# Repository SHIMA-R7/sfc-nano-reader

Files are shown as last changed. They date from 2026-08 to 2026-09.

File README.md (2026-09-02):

# SFC (Super Famicom) Cartridge Reader — Nano x3

Arduino Nano 3台だけでスーパーファミコンのカートリッジROMを読み出すプロジェクト。

ESP32-S3やレベル変換IC、シフトレジスタ(74HC595)を一切使わず、**5VネイティブなNanoを
「アドレス生成」「データ読み取り」「バンク生成」の3役に分担させる**ことで、
手持ちのNano以外の追加部品ゼロで構成しています。

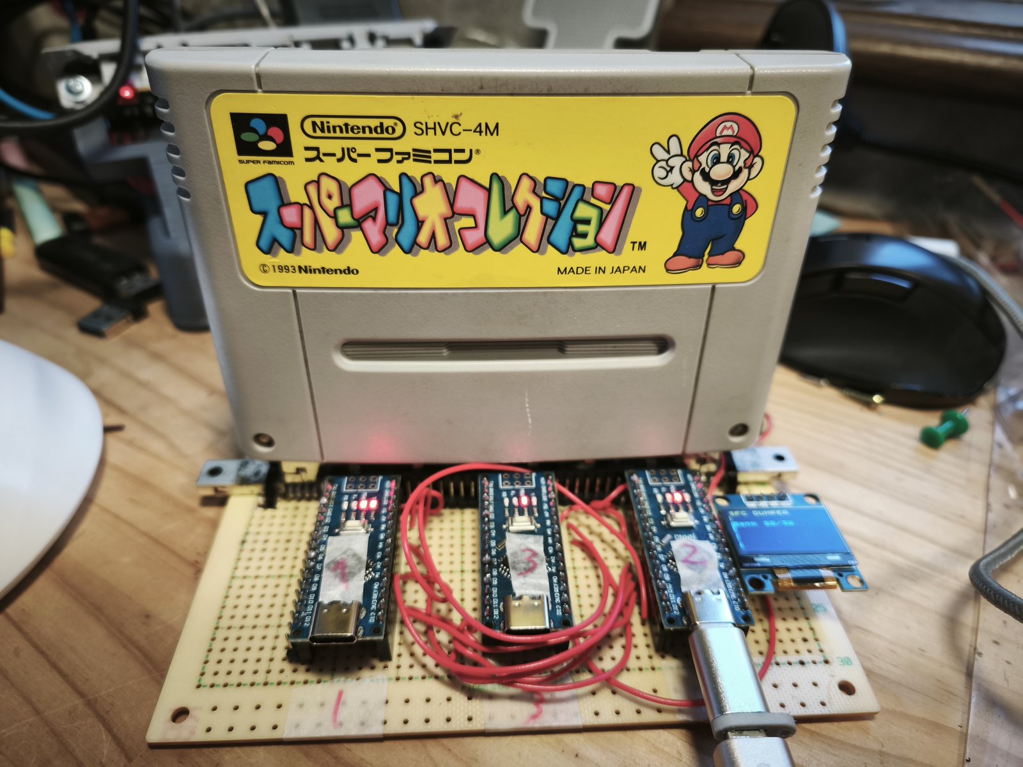
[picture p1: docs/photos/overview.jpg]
全体図


*スーパーマリオコレクション（SHVC-4M）をダンプ中。ユニバーサル基板にNano×3とOLEDを直付けし、
カートリッジコネクタを載せただけの構成。PCBは使っていない。*

> **自分でも作ってみたい方へ** → **[製作・使用ガイド (docs/GUIDE.md)](docs/GUIDE.md)**
> 部品表、コネクタ加工のコツ、配線表、書き込み手順、検証方法、
> トラブルシューティングをまとめてあります。
>
> **ここに至るまでの経緯** → **[開発史 (docs/HISTORY.md)](docs/HISTORY.md)**
> 踏んだ地雷と誤診の記録。「なぜこの設計なのか」はこちらに書いてあります。

## この文書について

**ここには結論と、使うときの注意だけを書いています。**
どう間違え、どう気づいたかの経緯は [開発史](docs/HISTORY.md) にまとめました。
同じ地雷を踏む人を減らすための記録なので、似た症状で困ったらそちらを見てください。

- [開発史](docs/HISTORY.md) — 誤診と訂正の記録（10章）
- [製作報告PDF](docs/SFCダンパー製作報告.pdf) — 20ページの詳細版
- [やさしい解説PDF](docs/やさしい解説.pdf) — 非技術者向け10ページ
- [実験データ](data/) — 判定つきCSV。読み方の注意も同梱

## なぜNano×3なのか

SFCカートを読むには最低でも **アドレス24本 + データ8本 + 制御2本 ≒ 34本** のI/Oが要ります。

| 構成 | 問題点 |
|---|---|
| ESP32-S3 単体 | 5Vトレラントでないため、カートの5V出力を直結すると壊れる。レベル変換IC必須 |
| Arduino Uno 単体 | 5Vネイティブで電圧問題はないが、使えるI/Oが18本しかなく全く足りない |
| Arduino Mega 2560 | I/O 54本で直結でき最も素直（Sanni's Cart Readerがこの構成）。ただし買い足しが必要 |
| **Nano × 3** ← 本プロジェクト | **手持ちのみで完結。全ボードが5Vネイティブなので電圧問題が原理的に発生しない** |

Raspberry Pi Zero 2 を併用する案も検討しましたが、3.3V系のためデータバス8本＋ACKに
分圧抵抗が18本ほど必要になり、「手持ち部品だけで完結する」という利点が失われるため見送りました。

## 構成

```
                    ┌──────────────┐
   A0-A15 ─────────>│              │
                    │  SFCカート   │
   A16-A23 ────────>│  (62pin)     │
                    │              │
   /RD,/ROMSEL ────>│              │
                    └──────┬───────┘
                           │ D0-D7
                           v
  [Nano-1]  <--STROBE--  [Nano-2]  --STROBE-->  [Nano-3]
  A0-A15生成             マスタ/データ読取      A16-A23生成
                         + OLED + USB
                              │
                              v  USBシリアル (1,000,000 bps)
                             PC
```

| ボード | 役割 | スケッチ |
|---|---|---|
| Nano-1 | カートアドレス **A0-A15** を生成。STROBEの立ち上がりで16bitカウンタを+1、RESETで0クリア。**ピン変化割り込み(PCINT)で受ける** | [nano1_addr_low/](nano1_addr_low/) |
| Nano-2 | `/RD`・`/ROMSEL`制御、**D0-D7**読み取り、USBシリアルでPCへストリーム、SH1106 OLEDへ進捗表示 | [nano2_master/](nano2_master/) |
| Nano-3 | カートアドレス **A16-A23**（バンク）を生成。Nano-1と同じくSTROBE方式＋PCINT | [nano3_bank/](nano3_bank/) |

`/WR` と `/RESET` はカート側で +5V に直結（読み出し専用のため）。

**通常のカートではCICロックアウトチップは関係ありません。** CICは本体側のリセット線を
駆動するだけで、ROMバスを塞いではいないので、無視してアドレスを叩けば読めます。
**ただしSA-1カートは例外で、CIC認証が必要です**
（[SA-1はクロックを与えず、CIC認証を通して読む](#sa-1はクロックを与えずcic認証を通して読む)）。

## 実機の写真

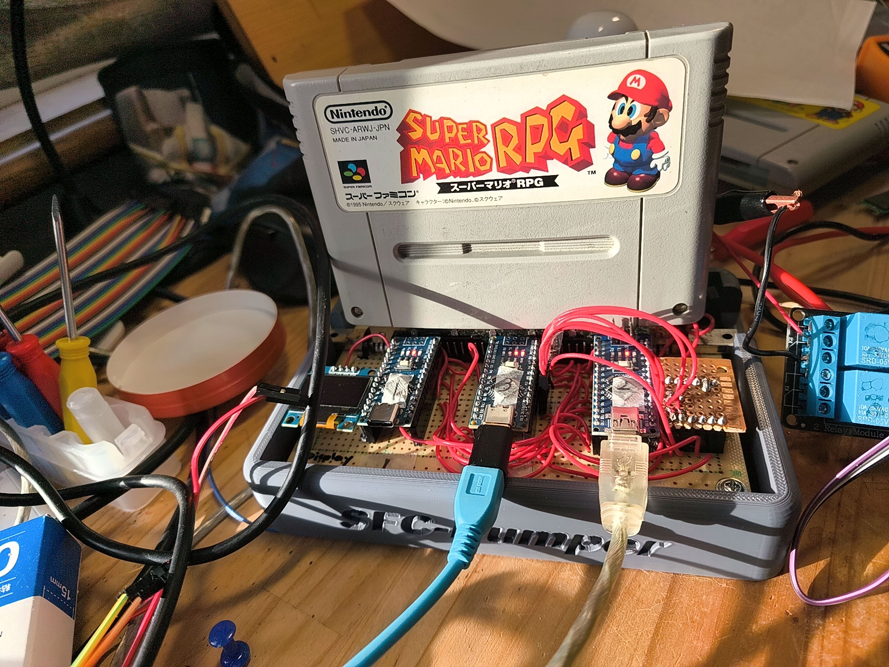
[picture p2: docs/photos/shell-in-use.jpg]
シェルに収めた状態


*3Dプリントしたシェルに基板を収めた状態。スーパーマリオRPG（SA-1）を読み出している。
左からOLED、Nano-3、Nano-1、Nano-2、右端が電源リレー。USBは2本（Nano-2とUno）。*

- 手書きのポンチ図: [docs/schematic-sketch.pdf](docs/schematic-sketch.pdf)
- **シェル（筐体）**: [hardware/shell/](hardware/shell/) — 基板を収める外装。
  裏面の配線を保護し、カートリッジの抜き差しで基板がたわむのも防げる
  - `shell_dumper.stl` — 本体シェル
  - `SFC.stl` — 天面のロゴ
- 3Dプリント部品: [支柱.stl](支柱.stl) — **4本印刷して基板の四隅に取り付ける脚**。
  裏面は配線がびっしり出ているので、机に直置きすると断線やショートの原因になる
  （シェルを使う場合は不要）

| | |
|---|---|
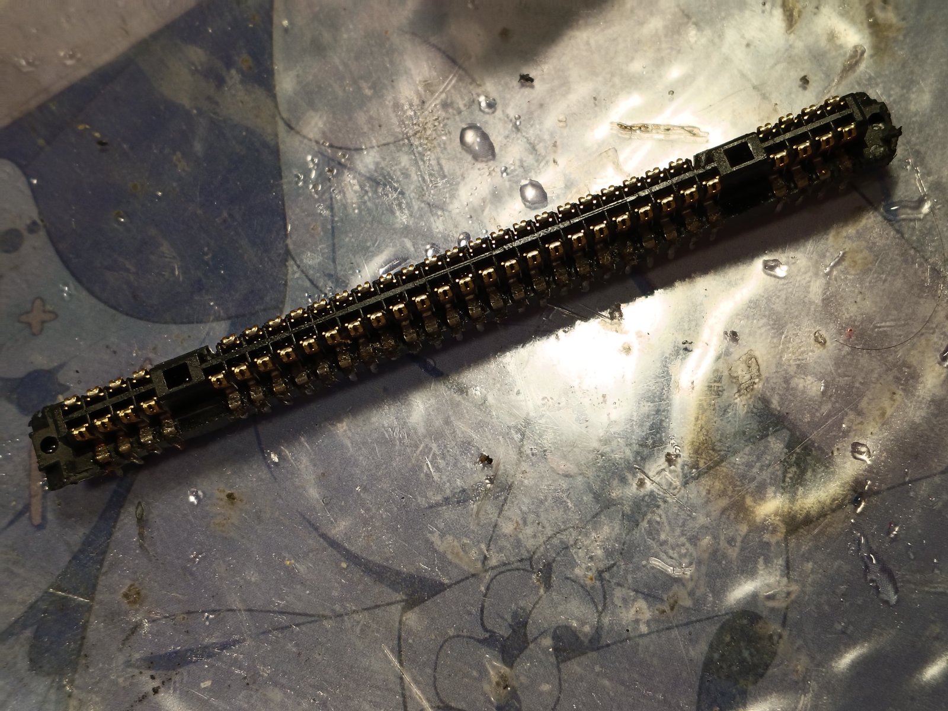
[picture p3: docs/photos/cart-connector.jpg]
カートリッジコネクタ
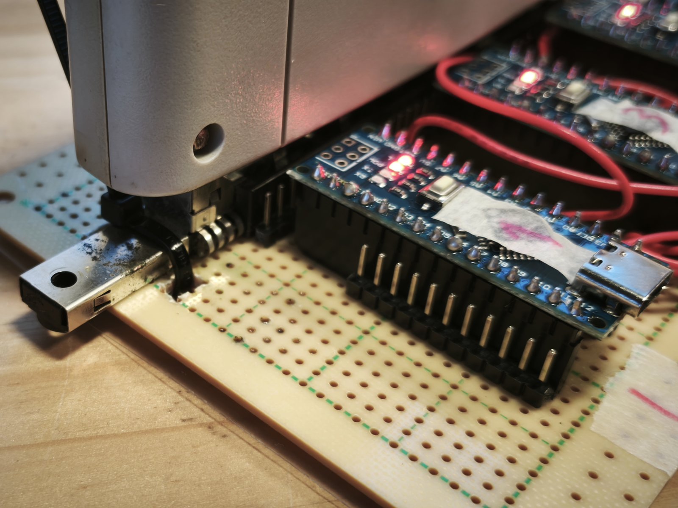
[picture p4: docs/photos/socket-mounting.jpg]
ソケット取り付け
|  |  |
| **ジャンクのスーパーファミコンから取り外した62pinコネクタ。** これが本プロジェクトで唯一「買わずに済ませた」最大の部品。ピッチ2.50mm・列間隔もキー溝も非標準なので、2.54mmのユニバーサル基板に載せるためキー溝を超音波カッターで切断している。 | **Nanoはピンソケットではなくピンヘッダで直付け。** 基板が2.54mmグリッドなので、コネクタ側の寸法差はここで吸収せず力技で押し込んでいる。 |
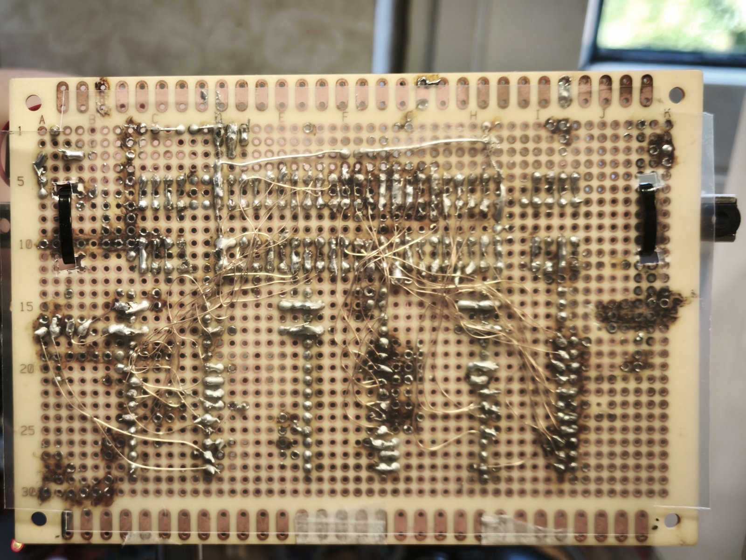
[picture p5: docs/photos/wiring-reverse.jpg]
配線面
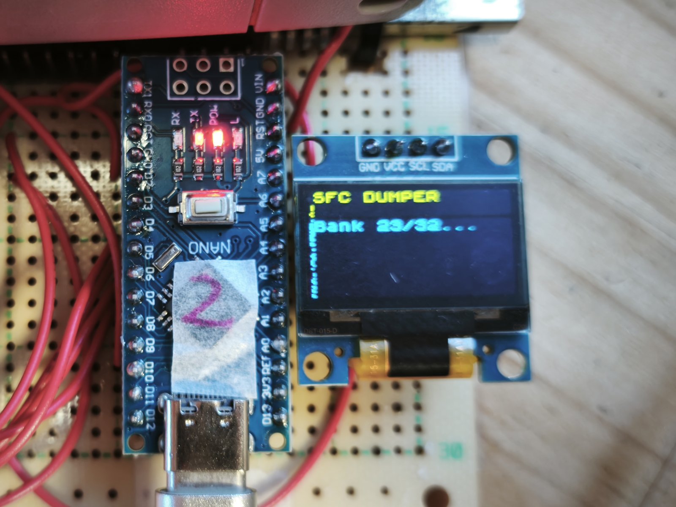
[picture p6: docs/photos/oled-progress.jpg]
OLED表示
|  |  |
| **裏面の配線。** Nano↔カートリッジ間はすべてUEW（ポリウレタン銅線）、それ以外はAWG22のビニール導線。アドレス24本＋データ8本＋制御を手配線している。 | **SH1106 OLEDによる進捗表示。** ハードウェアI2Cピン(A4/A5)はカートのデータバスD4/D5で埋まっているため、ソフトウェアI2CでD11/D12に逃がしている。 |

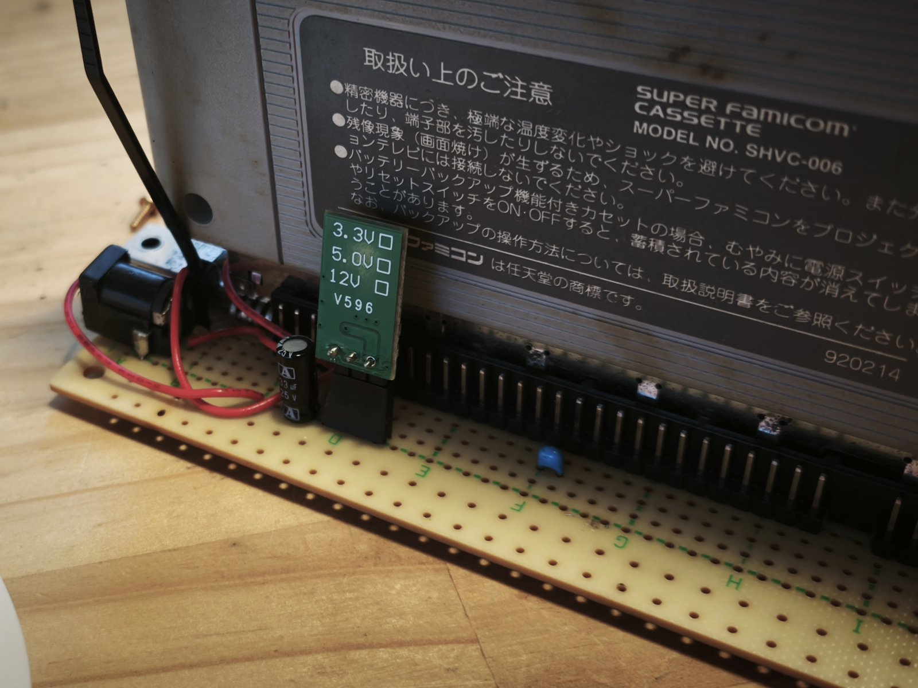
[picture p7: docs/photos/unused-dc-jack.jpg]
未使用のDCジャック


*当初は電源不足を懸念してDC12V入力＋降圧モジュール(3.3V/5.0V/12V可変のV596)を用意したが、
結局USBケーブル1本のバスパワーだけで3台のNano＋OLED＋カートが安定動作したため未使用に終わった。
写真手前の青い部品と電解コンデンサがパスコン。*

## ソフトウェア

### GUIアプリ（推奨）

**[最新版の実行ファイルをダウンロード（Releases）](https://github.com/SHIMA-R7/sfc-nano-reader/releases/latest)**
— Windows向け単一exe。Pythonのインストール不要です。

ソースから動かす場合:

```bash
python gui/sfc_dumper_gui.py
```

ブラウザ不要、Python標準のTkinterのみ（追加依存は `pyserial` だけ）。

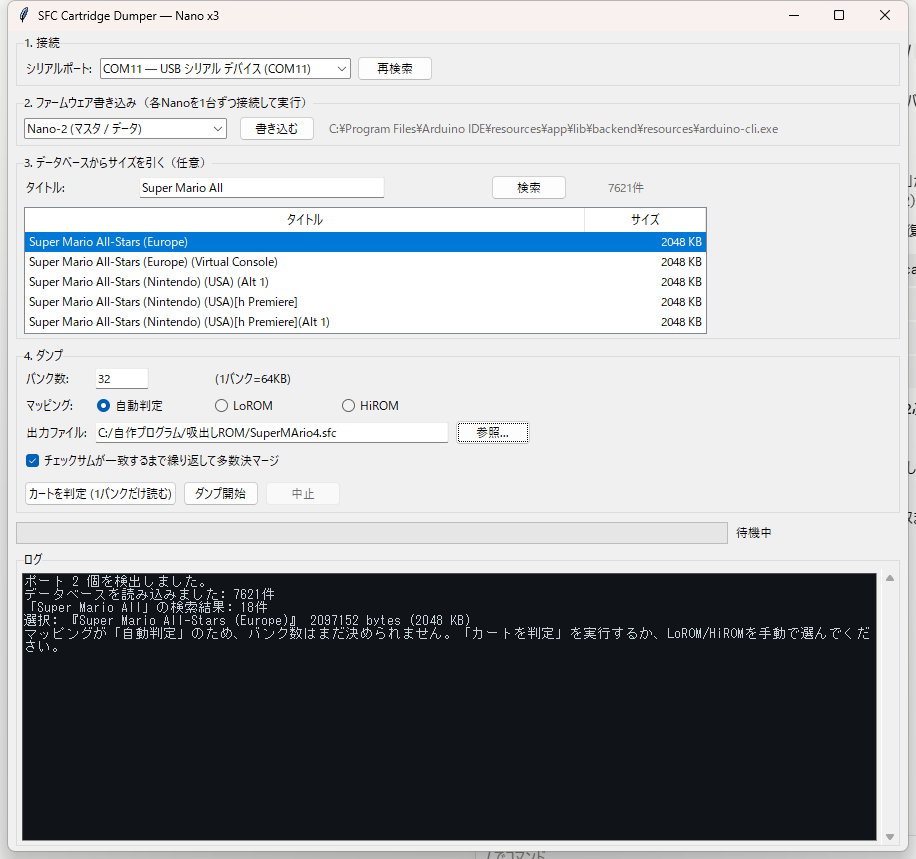
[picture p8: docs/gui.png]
GUI


- **COMポート選択**と自動検出
- **ファームウェア書き込み** — Nano-1/2/3を選んでボタン1つ（`arduino-cli`のパスも自動発見）
- **ROMサイズの指定を3通りから選べる**
  1. **自動判定** — 1バンクだけ読んでヘッダからLoROM/HiROM・サイズ・タイトルを認識
  2. **手動** — バンク数とマッピングを直接入力
  3. **データベース検索** — タイトル名で検索して正確なバイト数を引く（後述）
- **チェックサムが一致するまで自動でダンプを繰り返し、複数サンプルをマージ**
  （バイト単位の多数決とビットORの両方を試し、チェックサムが一致した方を採用する）
- **ダンプ方式を選べる**
  - **2回読んで一致するまで繰り返す**（推奨・速い）
  - **多数決マージ** — 何度読んでも一致しないカート向け。窓ごとの外れ値排除、
    ビット単位の再構成、決着しないバンクだけタイミングを上げて読み足す
    （[host/contact_merge.py](host/contact_merge.py) と同じ実装を共有）
- **タイミング掃引ボタン** — 同じバンクを5段階で2回ずつ読み、
  「タイミング不足 / 接触 / Super FX」のどれなのかを切り分けて、適切な段階を自動で選ぶ
  （[切り分けの根拠](#0xff率が動くかどうかで接触とタイミング不足を切り分ける)）
- **キャッシュのカート照合** — 前回のサンプルを再利用する前に1バンクだけ読んで、
  同じカートかを突き合わせる。違えばその場で止まる
- **2の累乗でないROMの検出** — 読んだ長さで合わなければ短いサイズも試し、
  末尾のミラーを切り落とす（12Mbitのカートが2MBと名乗る問題への対処）

### CLI

```bash
# バンク単位で読む（推奨）。1バンクごとにリセットし、2回読んで一致するまで繰り返す
python host/dump_by_bank.py --port COM12 --banks 64 --mapping lorom --out MyGame.sfc
```

長時間の連続読み出しで誤りが出る問題（後述）を避けられるので、この方式が最も確実です。
確定したバンクは `<出力名>.banks/` にキャッシュされ、中断しても続きから再開できます。

```bash
# 通しで一気に読む（要ファーム変更: バンク単位モードを外す）
python host/receive.py COM12 2097152 dump.bin

# 通しダンプを繰り返してマージ（多数決 / ビットOR）
python host/dump_until_valid.py --port COM12 --banks 32 --mapping hirom --out MyGame.sfc
```

```bash
# 接触が悪くて「2回一致」が永久に取れないカート用。窓ごとの多数決で押し切る
python host/contact_merge.py --port COM12 --banks 64 --mapping lorom --out MyGame.sfc

# カートを挿し直した/配線を変えた直後は、それまでのサンプルを退避してから
python host/contact_merge.py --port COM12 --banks 64 --mapping lorom --out MyGame.sfc --fresh

# 既に取ってあるサンプルだけでマージし直す（カートを挿さなくてよい）
python host/contact_merge.py --merge-only --banks 64 --mapping lorom --out MyGame.sfc
```

生サンプルは `<出力名>.votes/` に1本ずつ残り、中断しても続きから積み増せます。
決着しなかったバイトは `<出力名>.report.txt` に位置が出ます。詳細は
[接触不良のカートを回数で押し切る](#接触不良のカートを回数で押し切る)。

### セーブデータ（バッテリーバックアップSRAM）の吸い出し

GUIの「5. セーブデータ」から実行できます。「カートを判定」を先に押すと、ヘッダから容量を
読んでボタンが有効になります。CLIなら:

```bash
python host/dump_sram.py --port COM12 --rom MyGame.sfc --out MyGame.srm
```

ROMは焼き直せば同じものが手に入るが、**セーブデータは世界に1つしかない**。しかもカート内の
ボタン電池は寿命が近く、切れた瞬間に永久に失われる。ROMより優先度が高い。

`--rom` に検証済みのROMを渡すと、そのヘッダからマッピングとSRAM容量を読んで自動設定する。
出力した `.srm` はそのままRetroArchの `saves/<コア名>/` に置けば実機の続きから遊べる
（夜光虫で3スロットぶんのセーブが読み込めることを実機確認済み）。

**書き込み事故は原理的に起こらない。** `/WR` はカート側で +5V に直結してあるので、
ファームに何を書こうとSRAMへの書き込みは物理的に発生しない。読み出し専用として作った
配線が、そのまま救出対象を守る安全装置になっている。

#### /ROMSEL の極性はマッピングで逆になる

ここが唯一の落とし穴だった。当初は「SRAMはROMとは別物だから `/ROMSEL` をアサートしない」と
考えて実装したが、LoROMでは全バイトが 0x00 になった。SNESの `/CART` がアサートされる条件は
**「バンク $40-$7D は全アドレス、バンク $00-$3F は $8000-$FFFF のみ」** なので:

| マッピング | SRAMの位置 | `/ROMSEL` |
|---|---|---|
| LoROM | `$70:0000-$7FFF` | **アサートする**（バンクが $40-$7D 側） |
| HiROM | `$20:6000-$7FFF` | **アサートしない**（$8000未満） |

全バイト0x00を見て「電池切れか」と早合点しなかったのは、**電池が切れていてもSRAMチップ自体は
カート動作中は+5Vで動くので、読めば何かしら返るはず**という理屈があったため。0x00で埋まるのは
「誰もバスを駆動していない」ときの症状で、これはROMダンプ時にも観測済みだった。

#### ミラーを検証に使う

SRAMの実容量(2KB〜32KB)はバンクの窓(LoROM 32KB / HiROM 8KB)より小さいことが多く、余りには
同じ内容が繰り返し現れる。この繰り返しが一致するかを**1回の読み出しだけで完結する検査**として
使える。ただしカートによってはSRAM外がオープンバスになりミラーが出ないので、判定の主軸は
従来どおり「2回読んで一致」に置き、ミラーは補助的な手がかりとして扱っている。

### データベース検索について

RetroArchに同梱されている `database/rdb/Nintendo - Super Nintendo Entertainment System.rdb`
（No-Intro準拠、7,621件）をそのまま読んでいます。**ネットワークアクセスは不要**です。

このファイルはlibretro独自のバイナリ形式（MessagePack）なので、外部ライブラリを増やさずに
済むよう最小限のデコーダを [gui/rdb.py](gui/rdb.py) に実装しています。

DBを使う利点は、**ヘッダの自己申告が2の累乗に切り上げられている場合があるため**です。
例えば `Super Nazo Puyo Tsuu (Japan)` は実際には 1,572,864 bytes (1.5MB) ですが、
ヘッダのROMサイズバイトは2の累乗でしか表現できません。

## 使い方

1. 62pinカードエッジコネクタ経由でカートと3台のNanoを配線
2. GUIから各ボードにスケッチを書き込み（`arduino:avr:nano:cpu=atmega328old` を使用。
   クローン品はOld Bootloader指定でないと `programmer is not responding` になることが多い）
3. 「カートを判定」でROMサイズを特定し、`nano2_master.ino` の `NUM_BANKS` をその値に変更して再書き込み
4. 「ダンプ開始」

## 特殊チップ搭載カートについて

### SA-1（スーパーマリオRPG / 星のカービィ スーパーデラックス）

**手順が決まっています。GUIの「SA-1カートを吸う」ボタンか、`host/sa1_wake.py` を使ってください。**

```bash
python host/sa1_wake.py --port COM19 --out KirbySDX.sfc --power-cycle --rounds 5
```

| 条件 | 内容 |
|---|---|
| **カート1番（マスタークロック）** | **駆動しない。** LOWに落とすと読めなくなる（通算 0/29） |
| カート57番（PHI2） | 駆動しない |
| **起動読み** | 大きく読む前に $C0〜$FF のどれか1バンクを短く読む |
| 読み方 | 1接続で64バンクを読み切る（4MBで約95秒） |
| 検証 | **総和検査とCRC照合を必ず通す** |

**成功率は40〜60%です。2回に1回失敗します。** リトライ前提で使ってください。
これはカート個体差ではなくSA-1の性質で、2タイトル各20回で確認しています。

**失敗の仕方が危険です。** 「64バンク全部がROMらしい」「ヘッダも読める」のに
中身が3割違う、という壊れ方をします。**品質判定は当てになりません。**
総和検査だけが弾きます。GUIのプレイボタンが検証済みROMしか受け付けないのはこのためです。

CIC認証の要否は**分かっていません**。各20回の全ダンプで 40% 対 45% と、
差を検出できませんでした。「不要」と結論したわけではありません（[開発史](docs/HISTORY.md)参照）。

### Super FX（スターフォックス / ヨッシーアイランド）

**特別な手順は要りません。** 通常のダンプで読めます。

ただし**GSUが $0000-$7FFF に応答する**ため、下位32KBだけを見る古い判定では
HiROMと誤判定されました。現在はヘッダの `map_mode` を優先するので問題ありません。
判定時に「搭載チップ: スーパーFX (GSU)」と表示されます。

### DSP-1（スーパーマリオカート など）

チェックサムが合わない場合、GUIが自動で $C0 から読み直します。
DSP-1は $00-$3F の $6000-$7FFF に居座るためROMが隠れます。

### SA-1のセーブデータ（BW-RAM）

**この装置では読めません。配線の制約です。**

sanniの手順は、SA-1のレジスタに書き込んで窓を開けることが前提です。

```c
// Direct writes to BW-RAM (SRAM) in banks 0x40-0x43 don't work
writeBank_SNES(0, 0x2224, block);   // BMAPS: 8KBブロックを $6000-$7FFF へ
writeBank_SNES(0, 0x2226, 0x80);    // SBWE:  書き込み許可
writeBank_SNES(0, 0x2228, 0);       // BWPA:  保護解除
→ その後 $00:6000-7FFF を読む
```

**バンク $40 を直接読んでも取れません**（sanni自身がそう書いています）。

本機は `/WR` をカート側で **+5V に直結**しており、書き込み事故が物理的に
起こらない設計です。そのぶん**SA-1のレジスタも叩けず、窓を開けられません**。

読めるようにするには `/WR` をマイコンに引き直す配線変更が要ります。
**その場合「書き込み事故は起こらない」という保証が失われます。**
対象は電池でしか保たれていないセーブデータなので、判断は慎重に。

---

## 電源（Alientek DP100）

Unoのリレーは不要です。DP100（USB HID / VID 2E3C / PID AF01）をPCから直接叩けば、
出力ON/OFF・電圧設定・**電流測定**がまとめてできます。

```bash
# SA-1を吸う（起動読み＋電源サイクルつき、無人で粘れる）
python host/sa1_wake.py --port COM19 --out KirbySDX.sfc --power-cycle --rounds 3

# 電源だけ落とす
python -c "from host.dp100 import DP100; p=DP100(); p.apply(False,5000,1000); p.close()"
```

### 安全装置は「引数で渡せない」形にしてある

このダンパーは5V専用で、それ以上かけると壊れる。`host/dp100.py` は次の3段構え。

1. **`VMAX_MV = 5000` を超える要求は例外で拒否する。** 電圧を引数で自由に渡せない
2. **投入前に設定を読み戻して一致を確認する。** 違えば出力を入れない
3. **投入直後に実測を読み、5.3Vを超えていたら即座に切る**

3が要るのは、`index=0x20` の書き込みでは **OVPが30.5Vのまま変更できない**ため。
電源側の過電圧保護は当てにできない。

**実際に効いた。** 初回接続時、DP100には **9.000V / 4.000A の設定が残っていた。**
そのまま出力を入れていたら9Vがかかっていた。

### プレイボタン（RetroArch連携）

吸ったROMをそのままRetroArchで起動する「▶ プレイ (RetroArch)」を付けた。

**検証を通ったROMだけ**が対象で、`.unverified` は遊べない。
64/64バンクが「ROMらしい」のに中身が3割違うダンプを何度も見ているので、
検査を通っていないものを起動させると、動かない理由が分からなくなる。

#### 探し方（配布しても動くように）

**まずこのアプリからの相対で探す。**

    <アプリの場所>/RetroArch/retroarch.exe          同梱した場合
    <アプリの場所>/../RetroArch/retroarch.exe       隣に置いた場合
    <アプリの場所>/../../RetroArch/retroarch.exe    exeを dist/ に置いたまま動かす場合
    <アプリの場所>/retroarch.exe                    RetroArchのフォルダに直接置いた場合

見つからなければ C:\RetroArch / %LOCALAPPDATA% / Program Files を当たり、
それでも駄目なら利用者に選んでもらう。選んだ場所は
`%LOCALAPPDATA%\sfc_dumper.json` に覚えるので、次回から聞かない。

コアは RetroArch の `cores/` から snes9x → bsnes → snes9x2010 → mesen-s の順に探す。
起動は `retroarch.exe -L <コア> <ROM>` で、作業ディレクトリはRetroArch側に置く
（設定やアセットを相対で探すため）。

### 連続読み（最速）

GUIのダンプ方式に「連続読み（最速・1バンクごとにリセットしない）」を追加した。
1接続で全バンクを続けて読む。SA-1で使っているのと同じ経路。

    従来方式（バンクごとにリセット）  214.5秒   9.5 KB/s
    連続読み（2回読んで照合込み）      97.1秒  42.2 KB/s
    → 全体 2.2倍 / 読み出し速度そのものは 4.4倍

スターフォックス(1MB)で実測。**従来方式のダンプとバイト単位で完全一致**し、
チェックサム 0xab12 とNo-Intro『Star Fox (Japan)』にも一致した。

既定では**2回読んで完全一致を確認する**（それでも従来より速い）。
一致しなければ保存せず、「2回読んで一致するまで繰り返す」方式へ切り替えるよう促す。

### 消費電流（5V、参考値）

| 状態 | 電流 |
|---|---|
| 電源断 | 1.2 mA / 0.091 V |
| 待機（カービィSDX） | 87〜91 mA |
| 待機（スターフォックス） | 81 mA |
| 読み出し中 | 66 mA (±1.7) |

**読み出し中のほうが待機より低い。** 待機中はカートの入力が浮いてCMOSの貫通電流が
流れ、読み出し中は正しく駆動されるので減る、という説明がつく。

`host/sa1_dp100.py` は0.5秒刻みで `power_log.csv` に記録する
（列: `t_s, iso, phase, round, mV, mA, mW`。`phase` は off/on/idle/read/done）。

## 注意

読み出したROMデータそのもの（`.sfc` / `.bin`）は著作物なので、このリポジトリには含めていません。
自分が正規に所有するカートリッジのバックアップ用途を想定しています。

## 謝辞 / Acknowledgements

このプロジェクトは、先人が公開してくださった資料・ソフトウェアなしには成立しませんでした。
以下すべてに深く感謝します。

### ハードウェア資料

- **[SNESdev Wiki — Cartridge connector](https://snes.nesdev.org/wiki/Cartridge_connector)**
  62pinカードエッジコネクタの完全なピンアサインを参照しました。本プロジェクトの配線表は
  ここの情報が基になっています。
- **[NESdev Wiki — Cartridge connector](https://www.nesdev.org/wiki/Cartridge_connector)**
  コネクタ全般の背景知識について。
- **[NESdev Forums — SNES Edge Connector](https://forums.nesdev.org/viewtopic.php?t=11389)**
  「SNESコネクタは2.54mmではなく2.50mmピッチであり、列間隔とキー溝も非標準」という、
  自作時に最も重要な指摘をここで得ました。
- **[shmups.system11.org — SNES 62-Pin Connector Replacement Dilemma](https://shmups.system11.org/viewtopic.php?t=53375)**
  互換コネクタの実情について。
- **[Sanni's Open Source Cart Reader](https://github.com/sanni/cartreader)**
  カートリッジダンパーの事実上の標準実装。ピンアサインとメモリマップ処理の
  正解を確認する基準として参照しました。Arduino Megaを使う理由（5Vネイティブ＋I/O数）も
  ここから学んでいます。

### ソフトウェア / ライブラリ

- **[U8g2 by olikraus](https://github.com/olikraus/u8g2)** (BSD-2-Clause)
  SH1106 OLEDの駆動に使用。ハードウェアI2Cピンが埋まっていたため、
  ソフトウェアI2C対応が決定的に助かりました。
- **[libretro-database / RetroArch](https://github.com/libretro/libretro-database)**
  タイトル検索とROMサイズ特定に使用している `.rdb` データベースの提供元。
- **[No-Intro](https://no-intro.org/)**
  上記データベースの元となっているROMセット情報の編纂プロジェクト。
- **[Snes9x](https://github.com/snes9xgit/snes9x)** / **[RetroArch](https://www.retroarch.com/)**
  ダンプ結果の検証に使用。特にSnes9xコアが出力する `Checksum OK` / `Invalid Checksum` の
  判定は、「ヘッダだけ正しくて本体が壊れている」状態を発見する決め手になりました。
- **[pyserial](https://github.com/pyserial/pyserial)**
  PC側のシリアル通信全般。
- **[arduino-cli](https://github.com/arduino/arduino-cli)**
  GUIからのコンパイル・書き込み自動化。

### その他

- SNESのメモリマップ、内部ヘッダ構造（チェックサム/補数の配置、ROMサイズバイトのlog2表現）
  に関する知見は、上記NESdev系Wikiのコミュニティが長年かけて解析・公開してくれたものです。

### 製作者より

こんにちは、ここまでのReadmeはすべてClaudeCodeが書いてくれたものです。お作法などよろしくないところも多そうですが、どうかご勘弁してください。さて、このダンパーは自分の力試しの側面がとても大きいです。というのも、「追加で一つもパーツを購入しない」という縛りプレイで制作したからです。62ピンのコネクターなどというぞっとしないパーツを使ってるにもかかわらず、PCBを使ってないのもそういうわけです。ユニバーサル基盤は2.54mmしかなかったので、カートリッジコネクターの一部を超音波カッターでぶった切る、無理やり結束バンドで止めるなどの無茶をやっています。結線はNano↔カートリッジはすべてUEW、それ以外はAWG22のビニール導線です。このような無茶苦茶な作り方をしても、一応動くようにはなるんだから、SFCってのはやっぱり世界一頑丈なハードなんじゃないかな、と思います。パスコンはあったほうがいいですよ！あと、最初は電源が足りないかなと思いましたが、思いのほかデータ通信用につないだケーブル一本で作動します。最後に、実用性についてですが、まぁ手間に合いませんな。ありあわせのパーツで動かすにはもってこいですが、安く仕上げたいんじゃなかったら絶対ほかのプロジェクトや既製品を参考にした方がいいです。1カートリッジあたり二桁回は吸い出さないとまともなデータが手に入らないのでね。(追記:一発で行けるようになったからそこそこ実用的かも？)もしやるなら絶対にClaudeCodeとかCodexとかといっしょにやった方がいいよ。

## ライセンス

MIT License（[LICENSE](LICENSE) を参照）

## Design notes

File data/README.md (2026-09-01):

# 実験データ

すべてカービィ スーパーデラックス（SA-1）またはスターフォックス（GSU）の実測。
判定は「既知の正解ROMとバイト単位で一致するか」。

| ファイル | 内容 | 試行数 |
|---|---|---|
| `voltage_sweep.csv` | GSU（スターフォックス）の電圧掃引 5.00-4.50V | 60 |
| `clock_sweep.csv` | SA-1のクロック掃引（初回・各5回） | 35 |
| `clock_confirm.csv` | 同上を3条件×20回で取り直し | 60 |
| `wake_sweep.csv` | 起動読みの要素分解 5条件×20回 | 100 |
| `sa1_voltage.csv` | SA-1の電圧掃引 5.00-4.50V ×20回 | 120 |
| `wake_decay.csv` | 起動読みの持続時間 0/10/30/60/180秒 ×15回 | 75 |
| `proxy_check.csv` | 1バンク判定と全64バンク読みの突き合わせ | 20 |
| `baseline40.csv` | 基準条件の追試 | 40 |

`power_log.csv`（0.5秒刻みの電流記録）はリポジトリ直下にある。

## 読むときの注意

**`match` 列は約10%の上振れを含む。** `proxy_check.csv` で検証したところ、
1バンク判定は全64バンク読みと18/20で一致し、外れた2件はどちらも楽観側
（判定は成功・全体は失敗）だった。条件間の比較は同じ偏りを受けるので有効だが、
絶対値は割り引くこと。

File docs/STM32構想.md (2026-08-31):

# STM32F103 + 74HCT による1チップ化の検討

**状態: 机上検討。まだ何も作っていない。**

現行機はNano 3枚でGPIOの不足を人海戦術で埋めている。1枚のマイコンで
まかなえるなら、USB変換チップ由来の 100 KB/s の壁も同時に消える。
ここでは「秋月・千石・共立・アリエクで買えるもの」に限って構成を検討する。

---

## 1. なぜ直結できないのか

STM32F103C8T6（Blue Pill）のGPIOは37本。必要な信号を数えると足りない。

| 信号 | 本数 |
|---|---|
| A0-A23 | 24 |
| D0-D7 | 8 |
| /RD, /ROMSEL, /WR | 3 |
| /RESET | 1 |
| CIC 4線 | 4 |
| マスタークロック(カート1番) | 1 |
| **合計** | **41** |

**41 > 37。落ちる。** さらにBlue Pillの実装では USB(PA11/PA12)、
SWD(PA13/PA14)、32.768kHz水晶(PC14/PC15) が埋まるので実際はもっと厳しい。

## 2. 本当の制約は5Vトレラントピンの数

**F103は全ピンが5Vトレラントではない。** アナログ入力を持つピンは非トレラント。

```
非トレラント : PA0-PA7, PB0, PB1, PC13, PC14, PC15
トレラント   : PA8-PA15, PB2-PB15          （計22本）
  うち USB で PA11/PA12、SWD で PA13/PA14 が埋まる → 実質18本
```

ただし**トレラントが要るのは入力方向だけ**である。

| 方向 | 対象 | 対策 |
|---|---|---|
| カート → MCU | D0-D7、CICのKey応答 | 5Vトレラントピンに直結（10本） |
| MCU → カート | アドレス・制御・クロック | 74HCTでシフト（トレラント不要） |

必要な10本に対して18本。**足りる。** 非トレラントのPA0-PA7は
出力専用として使えば無駄にならない。

## 3. 74HCTでなければならない理由

```
74HC  : V_IH = 3.5V (5V動作時) → 3.3V出力では規格を満たさない
74HCT : V_IH = 2.0V            → 3.3V出力でOK
```

**HCとHCTを間違えると動いたり動かなかったりする。** 買うときに必ず確認する。

---

## 4. ピン割り当て

### 出力専用（非トレラントピンを充てる）

| STM32 | 信号 | 行き先 |
|---|---|---|
| PA0-PA7 | LD0-LD7 | 573×4 の D入力へ共通バス |
| PB0 | LE_A | 573#1 ラッチ許可 (A0-A7) |
| PB1 | LE_B | 573#2 ラッチ許可 (A8-A15) |
| PC13 | /OE | 573×4 共通。10kΩで3.3Vへプルアップ |

`PC13` は駆動能力が3mAしかないが、HCTの入力はほぼ電流を食わないので問題ない。
**プルアップ先は3.3Vにすること。PC13は5Vトレラントではない。**

### 5Vトレラントピン

| STM32 | 信号 | 経路 |
|---|---|---|
| PB8-PB15 | D0-D7 | **カートに直結**（入力） |
| PB2 | LE_C | 573#3 ラッチ許可 (A16-A23) |
| PA8 | MCLK | 573#4 経由 → カート1番 |
| PA9 | /RD | 573#4 経由 |
| PA10 | /ROMSEL | 573#4 経由 |
| PB7 | /WR | 573#4 経由 |
| PB6 | /RESET | 573#4 経由 |
| PB5 | CIC_CLK | 573#4 経由 |
| PB4 | CIC_RESET | 573#4 経由 |
| PB3 | CIC_D0 | **直結**（オープンドレイン）+ 4.7kΩ→5V |
| PA15 | CIC_D1 | **直結**（オープンドレイン）+ 4.7kΩ→5V |

### 予約・使用不可

| ピン | 理由 |
|---|---|
| PA11, PA12 | USB D-/D+ |
| PA13, PA14 | SWD（書き込み・デバッグ） |
| PC14, PC15 | 32.768kHz水晶。外せば空くが用途なし |

**使用 29本 + USB 2 + SWD 2 = 33本。実質的な余りはゼロ。**

---

## 5. 設計上の注意

### PB8-PB15にD0-D7を置いた理由
`GPIOB->IDR >> 8` の1命令で8ビットまとめて読める。ここを飛び飛びに割ると、
読むたびにビットを組み立て直すことになって速度が出ない。

### PB3, PB4, PA15 を使うにはJTAG無効化が要る
これらはJTAGピンなので、起動時に一度だけ解放する。SWDは残るので書き込みはできる。

```c
__HAL_RCC_AFIO_CLK_ENABLE();
__HAL_AFIO_REMAP_SWJ_NOJTAG();   // JTAGだけ切る。SWDは残す
```

**これを忘れるとPB3/PB4/PA15が動かない。** 配線を疑う前にここを見る。

### PB2 は BOOT1 なので、リセット時にLowでなければならない
LE_C に割り当てたのは、573のLEが**Lowでラッチ保持**だから。リセット時にLow＝
アドレスが保持されたまま、で都合がよい。ここに「リセット時にHighであってほしい信号」
を置いてはいけない。

### /OE を必ず入れる
MCUのリセット直後、GPIOは入力（ハイインピーダンス）になる。/OEが無いと
573の出力が不定のままカートのアドレス線を叩く。10kΩのプルアップで
**電源投入時は出力禁止**にしておき、ファームが準備できてからLowに落とす。

### CICの2本はオープンドレインで済む
半二重で、双方が交互に喋る。STM32側をオープンドレイン出力にして5Vへプルアップすれば、
Lowは自分で引き、Highはプルアップが5Vまで持ち上げる。**シフタが要らない。**
ピンは5Vトレラントなので、相手が5Vを出しても壊れない。

### CICのカート側ピン番号は現物で確認すること
この表は機能名で書いてある。24/25/55/56 の対応は現行のNano-3の配線を正とする。

---

## 6. 部品表

### 必須

| 部品 | 個数 | 備考 |
|---|---|---|
| STM32F103C8T6 (Blue Pill) | 1 | アリエク。**WeAct等の素性の良いものを選ぶ** |
| 74HCT573 (8bitラッチ) | **4** | 3個がアドレス、1個が制御。**HCTであること** |
| 62ピン カートスロット | 1 | 現行機から流用可 |
| 0.1µF セラミック | 5 | 各HCTの直近に1個ずつ + 予備 |
| 100µF 電解 | 1 | 5Vバルク |
| 4.7kΩ | 2 | CIC_D0 / CIC_D1 → 5V |
| 10kΩ | 1 | /OE → 3.3V |
| ST-Link V2 | 1 | 書き込み。アリエクで数百円 |
| 5V電源 | 1 | 現行の安定化電源を流用 |

**ロジックICは4個。** 内訳は以下のとおり。

```
573#1 → A0-A7     (LE_A / PB0)
573#2 → A8-A15    (LE_B / PB1)
573#3 → A16-A23   (LE_C / PB2)
573#4 → MCLK, /RD, /ROMSEL, /WR, /RESET, CIC_CLK, CIC_RESET  （7本、LEはHigh固定＝素通し）
```

4個目は「ラッチ」ではなく単なるレベルシフタとして使う。74HCT541でもよいが、
**品番を1種類に揃えた方が買うのも実装も楽**なので573で統一している。

### あると良い

| 部品 | 個数 | 備考 |
|---|---|---|
| DIP-20 ICソケット | 4 | 573用。焼いたとき差し替えられる |
| ピンヘッダ | 適量 | |
| ユニバーサル基板 | 1 | まずは手配線で組んで検証する |

---

## 7. 分かっている限界

**OLEDもSDカードも載らない。** 実質的な余りピンがゼロなので、
現行機のOLED表示を移植する余地がない。

必要なら **STM32F103RCT6（LQFP64、GPIO 51本）** の最小基板に上げる。
アリエクで千円前後。ピンが14本増えるので、OLEDのI2C 2本もSDのSPI 4本も入る。
Flashも256KB、RAMも48KBに増えるので、**バンクを丸ごとRAMに溜めてから
まとめて送る**ことができるようになる。速度面ではこちらの方が有利かもしれない。

## 8. 未検証の前提

以下は**まだ確かめていない**。作る前に潰すこと。

1. **カートの入力が74HCTの出力High(約4.8V)で確実に認識されるか。**
   ほぼ問題ないはずだが、実測していない。
2. **CICのオープンドレイン化が実際のCICと噛み合うか。**
   SuperCICの実装はプッシュプルで送って受信時にHi-Zにしている。
   オープンドレインでも論理的には成立するが、実物で確認していない。
3. **アリエクのBlue Pillに載っているのが本物のSTM32か。**
   CS32/CKSなどのクローンが混ざる。動くことが多いがUSBが不安定な個体がある。
4. **USBネイティブにして実際に何 KB/s 出るか。**
   理屈の上ではNanoの100 KB/sの壁は消えるが、
   ボトルネックがバスのタイミングに移るだけかもしれない。

---
---

# 付録: Raspberry Pi Pico (RP2040) の場合

**状態: 机上検討。**

秋月で買えるという一点でSTM32より条件が良い。ただし**5Vトレラントではない**ので、
レベル変換が両方向に必要になる。

## 1. 決定的な違い

```
STM32F103 : 入力は5Vトレラント → 変換は 出力側だけ
RP2040    : トレラント無し     → 変換は 両方向
```

RP2040のGPIOは絶対最大定格が 3.3V + 0.3V。**カートの5Vを直結すると壊れる。**
pakutoma氏の構成にレベル変換が入っているのはこのためで、避けようがない。

## 2. ピン数

Picoの外に出ているGPIOは26本（GP0-GP22, GP26-GP28）。
STM32の割り当てをそのまま持ってくると29本必要で、**3本足りない。**

そこで**ラッチ入力とデータバスを共用する**。8本浮いて21本になる。

共用が成立する理由は、両者が同時に使われないからである。

```
アドレス確定時 : /RD=High → カートはデータを出さない → MCUがバスを駆動して573にラッチ
データ読み出し : /RD=Low  → カートが駆動 → MCUは入力に切り替えて受ける
```

## 3. ピン割り当て

| GPIO | 信号 | 経路 |
|---|---|---|
| GP0-GP7 | SD0-SD7（共用バス） | 573×4のD入力 ／ LVC245経由でカートD0-D7 |
| GP8 | LE_A | 573#1 (A0-A7) |
| GP9 | LE_B | 573#2 (A8-A15) |
| GP10 | LE_C | 573#3 (A16-A23) |
| GP11 | /OE | 573共通。10kΩで3.3Vへプルアップ |
| GP12 | /RD | 573#4経由。**同時にLVC245の/OEへ** |
| GP13 | /ROMSEL | 573#4経由 |
| GP14 | /WR | 573#4経由 |
| GP15 | /RESET | 573#4経由 |
| GP16 | MCLK | 573#4経由 → カート1番 |
| GP17 | CIC_CLK | 573#4経由 |
| GP18 | CIC_RESET | 573#4経由 |
| GP19 | CIC_D0 | BSS138モジュール経由 |
| GP20 | CIC_D1 | BSS138モジュール経由 |
| GP26, GP27 | (空き) | I2C1。**OLEDが載る** |
| GP21, GP22, GP28 | (空き) | |

**使用21本 / 空き5本。** STM32構成と違ってOLEDが載る。

## 4. うまくいく仕掛け

### LVC245の/OEを/RDに繋ぐ
`74LVC245A` は VCC=3.3V で動かしても**入力が5Vトレラント**なので、
5V→3.3V の変換にそのまま使える。

その /OE を **/RD にそのまま繋ぐ**と、方向制御が自動になる。

```
/RD = Low  → 245が有効。カートのデータが3.3Vに落ちてMCUへ
/RD = High → 245がHi-Z。MCUが共用バスを駆動して573にラッチできる
```

**方向制御にGPIOを1本も使わない。** しかも論理的に間違えようがない。

### GP0-GP7を連番に置く
PIOのステートマシンが「/RDを下げる→待つ→8ビット読む→上げる」を
**CPUを介さずに**回せる。RP2040の速度の源はここにある。飛び飛びに割ると使えない。

### CICの2本はBSS138モジュールで済ませる
CICは半二重で双方が交互に喋る。これはI2Cと同じ使い方なので、
アリエクで100円前後の**BSS138 4chレベルシフタモジュール**がそのまま使える。
オープンドレイン+プルアップ方式なので、双方向の向き制御が要らない。

STM32ではここをピンのトレラント性で解決できたが、Picoではモジュールが1個要る。

## 5. 部品表

| 部品 | 個数 | 入手 |
|---|---|---|
| Raspberry Pi Pico | 1 | **秋月** |
| 74HCT573 | 4 | 3.3V→5V。**HCTであること** |
| 74LVC245A | 1 | 5V→3.3V。**VCC=3.3Vで使う** |
| BSS138 4ch双方向レベルシフタ | 1 | アリエク。CIC 2本用 |
| 62ピン カートスロット | 1 | 流用 |
| 0.1µF セラミック | 6 | 各IC直近 |
| 100µF 電解 | 1 | |
| 10kΩ | 1 | /OE プルアップ |

**ロジックIC 5個 + モジュール1個。** STM32より1個多い。
その代わり**ST-Linkが要らない**（USBにドラッグ&ドロップで書ける）。

## 6. STM32との比較

| | Pico | Blue Pill |
|---|---|---|
| 秋月で買えるか | **○** | ✗（アリエク） |
| 5Vトレラント | ✗ | ○（一部のみ） |
| レベル変換 | **両方向** | 出力側のみ |
| ロジックIC | 5個+モジュール | 4個 |
| GPIO | 26（21使用） | 37（29使用） |
| OLED | **載る** | 載らない |
| RAM | **264KB** | 20KB |
| PIO | **あり** | なし |
| 書き込み | **USB直** | ST-Link必要 |
| 速度の実績 | **200 KB/s（pakutoma氏実測）** | 不明 |

## 7. どちらを採るか

**部品点数だけならSTM32、それ以外はすべてPicoが有利。**

決め手になりそうなのは3つ。

1. **秋月で買える**（今回の制約そのもの）
2. **pakutoma氏が200 KB/sを実測している。** 机上の見積もりではない
3. **264KBのRAM。** 64KBのバンクを丸ごと溜めてから一気に送れる

ロジックICが1個増えることは、これらと引き換えにするなら安い。

## 8. 未検証の前提

1. **74LVC245Aの/OEを/RD(5V)に直結してよいか。**
   LVCは5Vトレラントなので問題ないはずだが、実測していない。
2. **BSS138モジュールがCICの速度に追いつくか。**
   プルアップで持ち上げる方式なので立ち上がりが鈍い。
   CICは1ビットあたり372パルスと遅いので大丈夫と見ているが、確認していない。
3. **共用バスの切り替えが実際のタイミングに間に合うか。**
   入出力の切り替えに時間がかかると、せっかくのPIOが台無しになる。

---
---

# 付録2: Waveshare Core2350B (RP2350B) の場合

**状態: 机上検討。実物の仕様はWaveshareの公表値による。**

## 1. 何が変わるか

RP2350**B** は RP2350A（Pico 2）と違って **GPIO が 48 本**ある。
これで**ラッチが不要になる**。

| | Pico (RP2040) | Core2350B (RP2350B) |
|---|---|---|
| GPIO | 26 | **48** |
| SRAM | 264 KB | **520 KB** |
| PSRAM | なし | **0 / 2 / 8 MB（選択可）** |
| Flash | 2 MB | 16 MB |
| PIOステートマシン | 8 | **12** |
| クロック | 133 MHz | 150 MHz |
| 5Vトレラント | ✗ | **✗（変わらず）** |

**5Vトレラントでないのは同じ**なので、レベル変換は両方向に必要なまま。
増えたのはピンとメモリである。

## 2. ラッチが要らなくなる

必要な信号は41本。**48本あるので全部直結できる。**

| GPIO | 信号 | 本数 |
|---|---|---|
| GP0-GP23 | A0-A23 | 24 |
| GP24-GP31 | D0-D7 | 8 |
| GP32 | /RD | 1 |
| GP33 | /ROMSEL | 1 |
| GP34 | /WR | 1 |
| GP35 | /RESET | 1 |
| GP36 | MCLK | 1 |
| GP37 | CIC_CLK | 1 |
| GP38 | CIC_RESET | 1 |
| GP39 | CIC_D0 | 1 |
| GP40 | CIC_D1 | 1 |
| GP41-GP47 | 空き | 7 |

**41本使用、7本空き。** OLEDのI2C 2本もSDのSPI 4本も入る。

読み出しサイクルが単純になる。

```
ラッチ方式 : 8bit書く→LE_A→8bit書く→LE_B→8bit書く→LE_C→/RD→読む   (7手)
直結方式   : 24bitまとめて書く→/RD→読む                            (3手)
```

**手数が半分以下。** これが速度に効く。

## 3. SA-1にとっての本命は PSRAM

8MB版を選ぶと、**4MBのROMを丸ごとRAMに落としてからPCに送れる。**

現行機はSA-1の窓の中で93秒間ずっとUSB転送を続けている。
PSRAM版なら、**窓の中でやるのはバス読み出しだけ**でよい。

```
現行機      : 窓の中で 93秒 必要（バス読み+USB転送が同時進行）
Core2350B   : 窓の中で 2〜4秒 必要（バス読みのみ。転送は窓が閉じた後）
```

バス側の理論値は、ROMのアクセス時間200ns + HCTの遅延13ns で
1サイクル300nsとすると 3.3 MB/s。4MBなら1.3秒。
余裕を見て1µs/byteでも4.2秒。

**窓の要求が93秒から数秒に落ちる。** 34連敗している今の問題に、
速度の話としてではなく**成功条件の話として**効く。

ただしこれは「窓の長さが有限で、短い方が有利」という仮説に立っている。
**その仮説自体はまだ検証されていない。**

## 4. 部品表

| 部品 | 個数 | 備考 |
|---|---|---|
| Waveshare Core2350B（**8MB PSRAM版**） | 1 | PSRAM版でないと3章の利点が出ない |
| 74HCT541（または245） | 4 | 出力31本を3.3V→5V |
| 74LVC245A | 1 | D0-D7 を5V→3.3V。VCC=3.3V |
| BSS138 4chレベルシフタ | 1 | CIC 2本 |
| 62ピン カートスロット | 1 | 流用 |
| 0.1µF | 7 | 各IC直近 |
| 100µF | 1 | |

**IC 5個 + モジュール1個。Picoと同数。**
ラッチが要らなくなった分がレベルシフタに置き換わっただけで、部品は減らない。

## 5. 実装上の注意

### E9エラッタ。**必ず A4 ステッピングを買うこと**
初期のRP2350には、入力ピンが約2.1Vで固着する不具合(E9)があった。
**バス読み出しでこれが起きると、データが化けたまま気づけない。**

- 2025年7月のA4ステッピングで修正済み
- 刻印が `RP2350B0A4` であることを確認する
- 2025年中頃以降の出荷分は該当するはずだが、**現物の刻印を見ること**

### PIOのGPIOウィンドウ
RP2350のPIOは一度に32本の窓しか見られない（GPIOBASEで 0-31 か 16-47 を選ぶ）。
A0-A23とD0-D7でちょうど GP0-31 を使い切るので、**制御線(GP32以降)が窓の外に出る。**

PIOブロックが3つあるので、
- PIO0 … base=0 でアドレス出力
- PIO1 … base=16 でデータ+制御

と分ければよい。**この分割が要ることを知らずに設計すると詰まる。**
（GPIOBASEがブロック単位かステートマシン単位かは、データシートで確認すること）

### USBがFPCコネクタ経由
Core2350Bは基板上にUSBポートを持たず、**6ピンのFPCコネクタ + 変換基板**で出す。
抜き差しの多い工具としては弱点になる。ケースを作るなら、
変換基板ごと固定してUSBコネクタだけを外に出す設計にする。

### 2.54mmの64ピン
キャリア基板に載せる前提の「コア基板」であって、Picoのように単体で
ブレッドボードに挿す用途は想定されていない。**ユニバーサル基板で試作するなら
先にピンヘッダを立てる必要がある。**

## 6. 入手性

Waveshare製なのでアリエクにはある。**秋月・千石・共立にあるかは未確認。**
PSRAM 8MB版は品番が分かれているので、注文時に取り違えないこと。

## 7. 3案の比較

| | Blue Pill | Pico | Core2350B |
|---|---|---|---|
| ロジックIC | 4 | 5+M | 5+M |
| ラッチ | 必要 | 必要 | **不要** |
| GPIO余り | 0 | 5 | **7** |
| RAM | 20KB | 264KB | **520KB + PSRAM 8MB** |
| SA-1の窓要求 | 93s | 約20s | **数秒** |
| 秋月で買えるか | ✗ | **○** | 未確認 |
| USB | 直 | **直** | FPC経由 |
| 実測の裏付け | なし | **あり(200KB/s)** | なし |

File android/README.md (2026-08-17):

# SFC-Dumper Android アプリ

PCを使わず、Android端末とNano-2(マスタ)をUSB(OTG)で直結してカートをダンプするアプリ。
`host/bankio.py` と `gui/sfc_dumper_gui.py` のロジックをKotlinへ移植したもの。

**ファームウェア(nano1/nano2/nano3)は一切変更していない。** PC版と同じスケッチのまま動く。

実体のAndroid Studioプロジェクトは `C:\Users\<user>\AndroidStudioProjects\SFCDumper`。
このフォルダはソースの参照・バックアップ用。

## 構成

| ファイル | 内容 |
|---|---|
| `CartReader.kt` | Nano-2とのUSBシリアル通信。タイミング段階制御、2回読み一致検証、`AdaptiveTiming` |
| `RomAnalyzer.kt` | LoROM/HiROM判定、ヘッダ解析、ROM本体の抽出、チェックサム検証 |
| `DumpJob.kt` | カート判定 → 全バンク読み出し → ROM抽出 → 検証 の流れ |
| `MainActivity.kt` | 画面、USB接続・権限処理、SAFでの保存先選択 |

## ビルド

Android Studio で `Empty Views Activity` / Kotlin / minSdk 26 /
package `com.shvc.sfcdumper` のプロジェクトを作り、上記ファイルを配置する。
依存関係は `app/build.gradle.kts` と `settings.gradle.kts` を参照
(`usb-serial-for-android` を JitPack 経由で取得)。

## Android移植で判明した注意点

実機で動かすまでに3つの落とし穴があった。同じことをやる人向けに記録しておく。

### 1. 受信は必ずチャンク単位で扱う

`SerialInputOutputManager` の `onNewData()` で受け取ったデータを、1バイトずつ
`LinkedBlockingQueue<Byte>` に詰める実装にすると **1,000,000bps では取りこぼす**。
64KBのバンク1本で65536回のボクシングが発生し、USB受信スレッドが処理に追いつかなくなる。
実際に「59642/65536 で止まる」という症状が出た。
届いた配列をそのままキューに積む方式(`LinkedBlockingQueue<ByteArray>`)にすれば解決する。
併せて `readBufferSize` も既定値から 16384 に上げている。

### 2. 読み出しのたびにDTRでNanoをリセットする必要がある

`nano2_master.ino` は `setup()` の中で `'R'` を送り、1バンク送ったら `loop()` は空、
という「使い切り」の設計になっている。
PC版(pyserial)が読み出しのたびに `serial.Serial()` でポートを開き直していたのは、
**その際のDTR操作でNanoがリセットされ `setup()` が再実行される**ことを利用していたため。

Androidではポートを開いたままにするので、明示的に `setDTR(false)→true` で
リセットパルスを送らないと、2回目以降の `'R'` が来ない。

### 3. Android 14以降のPendingIntent制限

USB権限リクエストで `Intent(ACTION_USB_PERMISSION)` に `FLAG_MUTABLE` を付けると、
Android 14(API 34)以降では暗黙的インテント扱いで例外になりアプリが落ちる。
`setPackage(packageName)` を付けて明示的インテントにする必要がある。

## 既知の制限・今後

- 読み出しのたびにNanoのリセット(ブートローダ起動待ち)が入るため、
  バンクあたり数秒のオーバーヘッドがある。これはPC版と同じ構造。
  ファーム側を `loop()` で繰り返し受け付ける形に改造すればリセット不要になり
  大幅に速くなるが、PC版との互換性に影響するため未着手。
- SRAM(セーブデータ)の読み出しはUI未実装。`CartReader.readBankOnce(sram=true)` は用意してある。
- CIC関連(`cic=true`、クロック分周指定)も同様に引数は用意済みだがUIからは未接続。

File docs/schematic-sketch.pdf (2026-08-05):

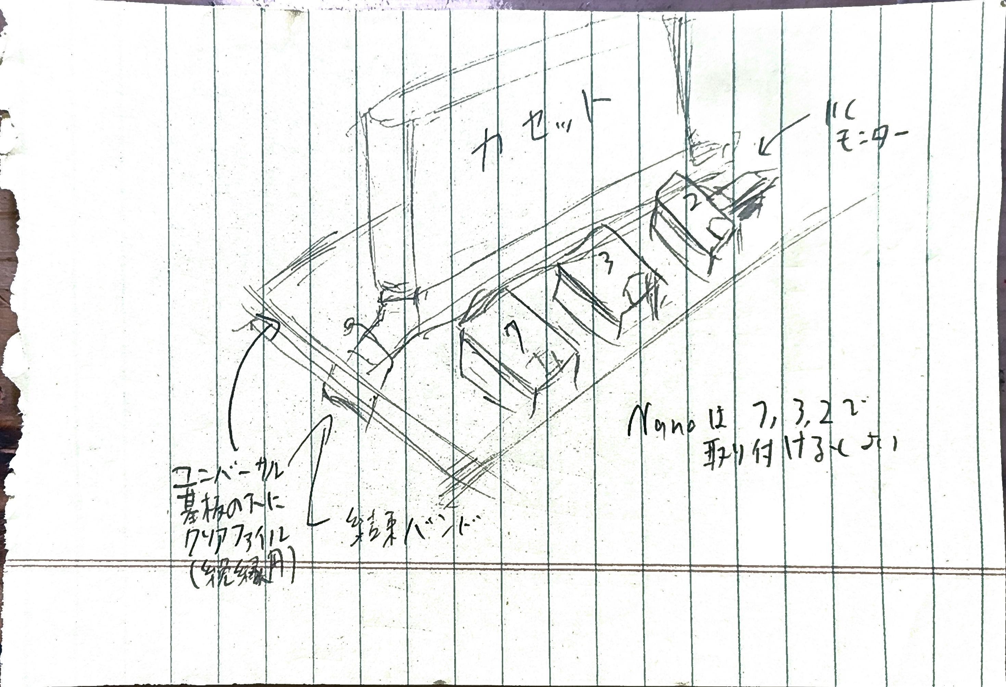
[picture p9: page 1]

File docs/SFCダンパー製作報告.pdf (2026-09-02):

# 「読めない」を分解する

Arduino Nano 3台によるスーパーファミコン

### カートリッジ読み出し装置の製作と、SA-1攻略の報告

2026年8月 実測記録にもとづく報告

要旨

追加部品を一切購入しないという制約のもとで、Arduino Nano 3台によるスーパーファミコン（SFC）カートリッ ジ読み出し装置を製作した。アドレス下位・データバス制御・バンクアドレスの3役を分担させ、レベル変換IC もシフトレジスタも用いずに34本以上の入出力要求を満たしている。17タイトルの読み出しに成功し、全ROMに

ついてヘッダ申告値と全バイト総和の一致を確認した（うち8タイトルはNo-IntroのCRC32とも照合済み）。

本報告の主題は成功手順ではなく、「読むたび内容が変わる」という単一の症状が、電源不足・接触不良・タイ ミング余裕不足・バス調停という4つの異なる原因から生じるという点にある。これらを区別する手続きとして 、「読み出しタイミング段階に対する相違バイト数の単調性」と「0xFF率の安定性」の2指標を提案し、実測で 検証した。

あわせて、SA-1搭載カートリッジ2タイトルの読み出しに成功したことを報告する。必要だったのは、CIC認証を 通したうえで、カートリッジにクロックを一切与えないことだった。SA-1はクロックを与えれば起動してバスを 掌握するが、与えなければ眠ったままでROMは素通しで読める。文献が必須とするマスタークロックは不要だっ たが、CIC認証は必要だった。なお本報告は当初この点を誤って「CIC認証も不要」と結論しており、その誤りの 原因（実験順序による交絡）も7章に記録した。セーブデータは逆にSA-1が動作していなければ読めず、未達で ある。

表1 装置と成果の概要

項目 | 内容
構成 | Arduino Nano ×3（すべて5Vネイティブ）＋ ジャンク実機から摘出した62ピンコネクタ
追加購入部品 | なし（設計上の制約）
読み出し速度 | 1バイト47us（初期実装331usから7.0倍）／2MBあたり約3分
検証済みタイトル | 17（総和一致17／No-Intro CRC32照合8）
対応した特殊チップ | Super FX（GSU / GSU-2）、DSP-1、SA-1（CIC認証あり）
未達 | SA-1カートのセーブデータ（ROMは取得済み）
ソフトウェア | GUI（Tkinter）／CLI／オフラインDB検索（No-Intro準拠7,621件）

本報告は、うまくいった手順よりも外れた仮説の記録に紙面を割いている。誤診はいずれも「もっともらしい説明が先 に立ち、それを検証せずに次の実験へ進んだ」という同じ形をしており、そこに再利用可能な教訓があると判断したた めである。

Arduino Nano 3台によるSFCカートリッジ読み出し装置

1. 序論

1.1 背景

SFCのカートリッジは、62ピンのカードエッジコネクタを介してROMをアドレス空間へ直接露出している。したが って外部からアドレスを与え、制御線を操作し、データバスを読み取れば、原理的にはROMの内容を取り出せる。

この操作を実装した装置は複数存在し、事実上の標準実装は sanni の Open Source Cartridge Reader（以下

OSCR）である。

本プロジェクトの出発点は「ESP32-S3の開発ボードとジャンクのスーパーファミコンが手元にある。これだけで吸 い出せないか」であった。そこに「追加で一つも部品を購入しない」という制約を課した。この制約は単なる縛り ではなく、以降の設計をほぼすべて決定している。

### 1.2 入出力要求と構成の選定

SFCカートの読み出しに必要な信号は、アドレス24本・データ8本・制御2本、電源系を除いて最低34本である。こ の一点で候補の大半が脱落した。

表2 構成候補と却下理由

構成 | I/O | 判断
ESP32-S3 単体 | 十分 | 却下。5Vトレラントでない。カートの5V出力を直結すると破損する。レベル変換ICが必須 だが手持ちがない
Arduino Uno 単体 | 18本 | 却下。34本に遠く及ばない
Arduino Mega 2560 | 54本 | 却下。直結でき最も素直（OSCRがこの構成）。ただし買い足しが要る
Raspberry Pi Zero 2 ＋ Nano | 十分 | 却下。3.3V系のためデータバス8本＋ACKに分圧抵抗が18本ほど必要になり、「手持ちだけ で完結」という利点が消える
Arduino Nano ×3 | 60本 | 採用。全ボードが5Vネイティブで電圧問題が原理的に発生しない。追加部品ゼロ

採用理由は消去法である。しかしこの選択は、後述するようにCIC認証への取り組みにおいて予期しない構造的優位 を生んだ（7章）。

### 1.3 本報告の構成

2章で装置の構成を述べる。3章で読み出しプロトコルと検証手法を整理し、4章で誤診の記録を扱う。ここが本報告

の中核である。5章で性能、6章で検証結果を示す。7章はSA-1に関する未達の報告であり、8章で全体の考察を述べ

る。

## 2. 装置の構成

### 2.1 役割分担

3台のNanoに、アドレス下位・バス制御とデータ読み取り・バンクアドレスを分担させた。Nano-2がマスタとして動 作し、PCとのUSBシリアル通信を独占する。Nano-1とNano-3はPCと通信せず、Nano-2からのSTROBEパルスでカウ ンタを進めるだけの自律動作をとる。

SFCカートリッジ
62ピン カードエッジ

Nano-1
A0-A15 生成

Nano-2（マスタ）

/RD /ROMSEL・D0-D7

Nano-3
A16-A23 生成

PC

アドレス A0-A15 | バンク A16-A23
/RD /ROMSEL | D0-D7
STROBE | STROBE

USB 1 Mbps

PCINTでエッジをラッチ | PCINTでエッジをラッチ

図1 装置のブロック図。Nano-1／Nano-3はPCと通信せず、STROBEの立ち上がりで内部カウンタを+1する。

表3 各ボードの担当

ボード | 担当 | 実装上の要点
Nano-1 | カートアドレス A0-A15 | STROBEの立ち上がりで16bitカウンタを+1、RESETで0クリア。ポート直叩き ・PCINT割り込み・millis()停止まで実装済み
Nano-2 | /RD・/ROMSEL制御、D0-D7読 み取り、USB送信、OLED表示 | 唯一PCと通信する。制御ピンはPORTDにまとめてマクロ化
Nano-3 | カートアドレス A16-A23（バンク）

Nano-1と同一方式。SA-1実験ではCIC役を兼務させた（8章で述べる問題を起こ した）

/WR はカート側で +5V に直結している。読み出し専用として設計したため、ファームウェアに何を書いてもSRA Mへの書き込みは物理的に発生しない。この配線は、後にバッテリーバックアップSRAMの吸い出し機能を追加し たとき、そのまま救出対象を守る安全装置として働いた。

### 2.2 コネクタという物理的な壁

62ピンのカードエッジは基板の両面に31本ずつ端子が並ぶ形式であり、表裏で124本ではない。この装置では、ジャ ンクのスーパーファミコン本体からコネクタを取り外して流用した。これが「買わずに済ませた」最大の部品であ

る。

当初「ピッチが2.0mmだから31ピンで大きくずれる」と説明したが、これは誤りだった。「それなら20ピンで1cmず れる、刺さるはずがない」という指摘を受けて資料を当たり直したところ、実際のピッチは2.50mmで、2.54mmと の差は0.04mm、31ピンでも累積1.2mm程度に留まる。整合しない主因はピッチではなく列間隔とキー溝の位置が非 標準であることだった。最終的にキー溝を超音波カッターで切断し、金属シールドで位置決めして押し込んでいる

。

記録: 数字が合わないと指摘されたときは、自分の記憶ではなく一次資料を当たる。この誤りは、指摘がなければそ のまま設計判断に影響していた。

## 3. 読み出しプロトコルと検証手法

3.1 メモリマップとミラー

SFCのROMマッピングにはLoROMとHiROMがあり、ヘッダの map mode バイトが自己申告している（0x20=LoROM 、0x21/0x31=HiROM、0x30=LoROM+FastROM、0x23=SA-1）。LoROMではA15がROM選択に関与しないため、1バ ンク64KBの上位32KBと下位32KBに同じ内容が現れる。これは故障ではなく正常な電気的挙動である。

この性質は「後半のバンクが前半のミラーになる」と誤解されやすいが、ミラーはバンクの中で起きるのであって バンク単位ではない。2MBのLoROMを読むには32KB×64バンクが必要であり、32バンクでは足りない。

バンク $01

$8000-$FFFF ROM 32KB

$0000-$7FFF ミラー

バンク $00

$8000-$FFFF ROM 32KB

$0000-$7FFF ミラー

実際のLoROM ─ ミラーは「バンクの中」

後半32バンク

＝前半のミラー

前半32バンク

＝実データ

よくある誤解（バンク単位のミラー）

図2 LoROMのミラーは1バンクの内部で起きる。バンク単位のミラーではない。

3.2 チェックサム検証の限界

SFCの内部ヘッダにはチェックサムとその補数が格納されており、2つを足して0xFFFFになるかを検査できる。しか しこれはヘッダの4バイトが正しく読めたことしか保証しない。ROM本体が壊れていても通る。

初期にSuper Puyo Puyoの1MBダンプでこの検査が通ったため「成功」と判断したが、誤判定だった。エミュレータ （Snes9xコア）に読ませたところ Invalid Checksum が出力された。正しい検証はROM全体のバイト総和である。

checksum = rom[off+30] | (rom[off+31] << 8) # ヘッダが主張する値
computed = sum(rom) & 0xFFFF # 実際に計算した値

以降、この総和とNo-IntroのCRC32の両方を検証に用いている。

3.3 2の累乗でないROMの扱い

ヘッダのROMサイズバイトはlog2表現であり、2の累乗でしか表現できない。したがって12Mbit（1.5MB）のカート は2MBと名乗る。このとき後半4Mbitはアドレス空間に2回現れるため、総和も同じ数え方をしなければならない。

ドラゴンクエストI・IIを読んだとき、64バンクすべてが未決着0バイト（＝5サンプルが全バイトで一致）だったに もかかわらず総和が合わなかった（計算0x47b5／期待0x2d8a）。読みが完全に安定している以上、犯人は読み出し

ではない。

sum(前半1MB) + 2 × sum(後半512KB) = 0x2d8a → 期待値と一致
CRC32 = 98bb6853 → No-Intro "Dragon Quest I & II (Japan)" / 1,572,864 bytes と一致

本報告の作成にあたり、かまいたちの夜（3MB）についても同じ検算を行い、sum(前半2MB) + 2 × sum(後半1MB) = 0x815c で期待値と一致することを確認した。

「チェックサムが合わない＝読めていない」ではない。読み出しの品質と、サイズの解釈は別々に疑う必要がある。

## 4. 誤診の記録 — 同じ症状、異なる原因

本章が報告の中核である。「読むたび内容が変わる」という症状は、少なくとも4つの独立した原因から生じる。そ して同じ原因を当てはめると必ず間違える。それを実際に3回繰り返した。

4.1 ストローブの取りこぼし — 最も長く誤診した問題

高速化のため digitalWrite/digitalRead（1回約4us）をポートレジスタ直叩きへ置き換え、ボーレートを1Mbpsに上 げたところ、速度は12倍になったがデータが壊れた。

表4 最初に立てた仮説と、その顛末

仮説 | 検証結果
ポート直叩きで同時スイッチングノイズが増えた | アドレスは毎回+1なので遷移するビットは平均2本程度。説明として苦しい
長時間の連続動作による電圧降下 | 外部電源に替えても変化なし
デカップリング不足 | 最短距離で実装済み・33uF搭載済み・GNDも両方引いている。打つ手は尽 きていた

決定打は、同じバンクを10回読んで毎回きっかり30,966バイトの相違が出たことだった。ノイズであれば数値はば らつく。完全に決定的である。そこで「どう壊れているか」を総当たりで検算した。

表5 出力と正解の対応づけを総当たりで検算した結果

仮説 | 一致率
そのまま 出力[i] == 正解[i] | 5.5%
2倍速 出力[i] == 正解[2i] | 66.7%
半分（重複読み）出力[i] == 正解[i÷2] | 100.0%（32,768/32 ,768）

同じアドレスを2回ずつ読んでいた。Nano-1がストローブをきっかり1回おきに取りこぼしていたのである。ポーリ ングには「ループを一周する間に来たパルスを取りこぼす」という原理的な穴があり、Nano-1の処理時間がNano-2 の1サイクルより長くなれば必ず半分落ちる。パルス幅を60us、100usと広げていたのは、穴を塞がずに誤魔化して

いただけだった。

解決はNano-1／Nano-3のピン変化割り込み（PCINT）化である。エッジをハードウェアがラッチするため、ISRが動 く前にパルスが終わっていても取りこぼさない。穴そのものが消える。

STROBE

ポーリング | 1回おきに落ちる
| → 同じアドレスを2回読む

PCINT

ハードウェアがラッチ

→ 穴そのものが消える

図3 ポーリングは処理時間が1サイクルを超えた瞬間から半分を落とす。PCINTはエッジをハードウェアで保持するため、この失 敗モードが存在しない。

教訓: 数値が毎回ぴたりと同じなら、それはノイズではなく構造的な誤りである。「壊れている」で止めずに「どう 壊れているか」を測ったことが突破口になった。

4.2 スターフォックス — 犯人は電源だった

Super FX（GSU）搭載カートは長らく読めなかった。同じバンクを読むたび数百バイトが化け、2回一致が永久に成 立しない。多数決ダンプを実装して10サンプルを積んだが、1MB中38,937バイトが決着せずCRCも合わなかった。

誤診に至った理由は、症状が「動作中のバスマスタと衝突している」ようにしか見えなかったことである。特に遅 くするほど悪化するという挙動が決定的な誤解を招いた。「読み出しに時間をかけるほどGSUが割り込む機会が増 える」と解釈したが、実際は遅い設定ほど1バンクの読み出しが長引き、弱い電源を長時間虐めていただけだった。

表6 安定化電源を5Vバスへ直結する前後の比較（同一バンクの2回読みの相違バイト数）

段階 | 1バンクの所要 | 改善前 | 改善後
高速 (5us) | 15.0 s | 89 / 75
やや低速 (20us) | 19.2 s | 338 / 611
低速 (50us) | 27.8 s | 5,259 / 2,758
安全 (100us) | 42.3 s | 1,969 / 1,340
最安全 (300us) | 99.1 s | 2,524 / 9,828 | 29

電源改善後、同じ設定で連続5回読んで1バイトも違わなくなった。その状態でLoROM 32バンクを読んだところ、総和もCRC32も一発で一致した（Star Fox: 41a60b3f）。原因はGSUではなく電源だった。

この結果は自動化機構の前提を壊した。本装置のタイミング自動エスカレーション（5→20→50→100→300us）は「 遅くすれば安全になる」を前提にしているが、その前提は電源が健全なときにしか成り立たない。電源が弱いと自動 エスカレーションが自ら傷口を広げる。

4.3 ヨッシーアイランド — 今度は接触だった

次のSuper FXカート（GSU-2、2MB）で、まったく同じ症状が出た。電源が犯人だった直後なので当然そちらを疑 ったが、外れだった。

表7 ヨッシーアイランドで疑ったものと検証結果

疑ったもの | 検証結果
電源不足 | × 安定化電源が4.99Vを維持
発熱 | × 触っても熱くない
アドレス線・データ線の不良 | × どのビットにも偏りなし（各3.4〜6.6%）
カートリッジの接触 | ○ 挿し直しで0xFFが12分の1、連続3回読みで相違0

決め手は数分の間に品質が12倍変動したことである（上位32KBの0xFFが15,306個から1,268個へ）。電気的な設計 問題であればこのような不連続な揺れ方はしない。接触であれば当然である。持ち主の「実機で遊んでいた頃から 調子の悪いカセット」という証言が、こちらの測定より早く正解に近かった。

4.4 かまいたちの夜 — タイミング余裕不足

LoROM 3MBのこのカートは、連続2回読みで上位32KBが2,271バイト相違し、0xFF率が16.8%あった。接触不良にし か見えない。しかし段階を掃引したところ、相違が段階に対して単調に減り、かつ0xFF率がまったく動かなかった

。

表8 かまいたちの夜のタイミング段階掃引

読み出しタイミング | バンク$00 相違 | バンク$28 相違 | 0xFF率
高速 (5us) | 3,238 | 1,502 | 0.1675
やや低速 (20us) | 1,028 | 239 | 0.1678
低速 (50us) | 438 | 51 | 0.1678
安全 (100us) | 110 | | 0.1677
最安全 (300us) | | | 0.1678

0xFF率が段階によらず0.1675〜0.1678に留まることが、その0xFFが本物のデータであることの証拠になる。読 み落としであれば段階を変えれば率が動く。接触不良であれば跳ね回る。

4.5 切り分け手順の確立

以上3件から、2つの指標で原因を分離できることが分かった。

指標 | 意味
相違バイト数の、段階に対する単調性 | 単調に減る＝タイミング不足／無関係＝接触／遅くすると増える＝電源
0xFF率の安定性 | 不動＝その0xFFは実データ／跳ね回る＝接触で読み落としている

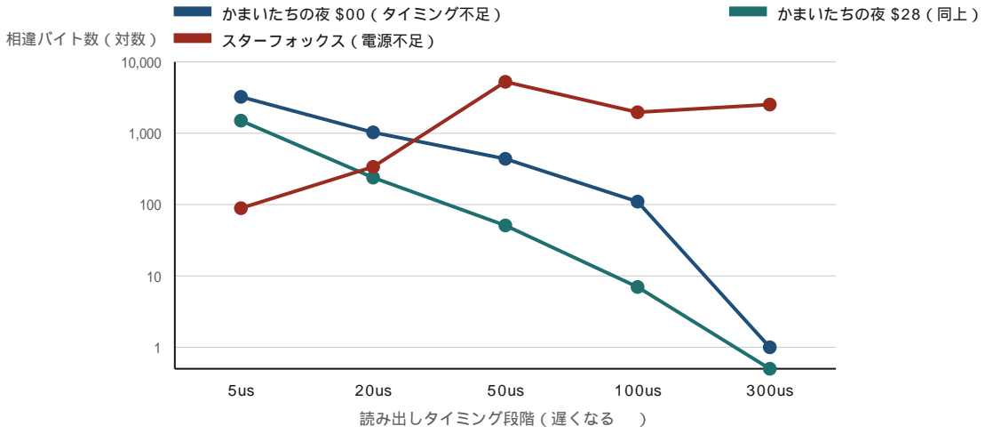
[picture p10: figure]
相違バイト数（対数）; 読み出しタイミング段階（遅くなる →）; かまいたちの夜 $00（タイミング不足）; かまいたちの夜 $28（同上）; スターフォックス（電源不足）

図4 同じ「読むたび化ける」でも、段階に対する応答は逆向きになる。かまいたちの夜は単調減少（タイミング不足）、スター フォックスは遅くするほど悪化（電源不足）。

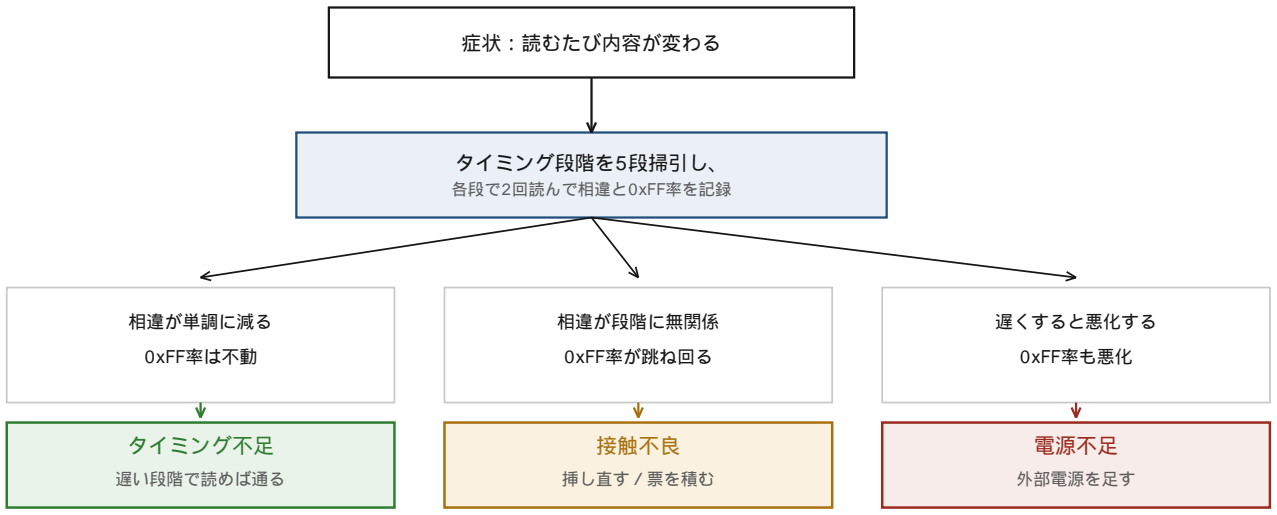
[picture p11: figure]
症状：読むたび内容が変わる; タイミング段階を5段掃引し、; 各段で2回読んで相違と0xFF率を記録; 相違が単調に減る; 0xFF率は不動; タイミング不足; 遅い段階で読めば通る; 相違が段階に無関係; 0xFF率が跳ね回る; 接触不良; 挿し直す／票を積む; 遅くすると悪化する; 0xFF率も悪化; 電源不足; 外部電源を足す

同じ症状に同じ原因を当てはめると必ず間違える。2つの指標で分ける。

図5 確立した切り分け手順。GUIの「タイミング掃引」ボタンとして実装した。

4.6 検証手法そのものが持つ穴

「2回読んで一致すれば正しい」という検証には落とし穴がある。カートが外れて全バイト0x00になった場合、そ の出力は自分自身と必ず一致する。同様に0xFF一色の読みも安定していて一致する。そのため全バイトが同一値の データは異常として弾いている。

さらに深い問題として、キャッシュ機構はカートの同一性を確認していなかった。かまいたちの夜を読み終えたあ と、以前の実行が残していたキャッシュを照合したところ、32,768バイト中32,191バイトが相違した。ずれや化けで はなく、中身がスターフォックスだった（ヘッダのタイトルが STAR FOX、先頭256バイトが別ファイルのオフセッ ト0と完全一致）。現在はキャッシュ再利用時に開始バンクを1本だけ読んで突き合わせ、食い違えばその場で停止

する。

## 5. 性能 — 何が律速か

### 5.1 高速化の経過

初期実装は331us/バイト（2MBで約12分）だった。内訳はほぼ全部が待ち時間であり、ROMの実力（アクセスタイ

ム120〜200ns）から見て500倍以上過剰である。4.1節のPCINT化ののち、待ち時間を段階的に掃引して詰めた。判定 基準は各条件で2回読み、両方とも正解と完全一致した場合のみ合格とした。

この基準は必要だった。実際PULSE=60usは単発では完全一致したのに、繰り返すと数千バイト化けている。

表9 待ち時間の掃引結果（正解既知のカートで照合）

設定 (RD / ADDR / PULSE) | 1バイト | 判定
20 / 20 / 5 | 79 us | 合格
10 / 10 / 3 | 57 us | 合格
5 / 5 / 3 | 47 us | 合格 ← 採用
3 / 3 / 2 | 42 us | 合格
2 / 2 / 2 | 40 us | 合格
1 / 1 / 1 | 38 us | 不合格（ヘッダが化ける）

最速値ではなく1段手前を採用したのは、カートの接触状態のばらつきに対する余裕のためである。

5.2 律速の分解

後日、SA-1攻略のためさらなる高速化を検討した際、「Nano-1が16本のdigitalWriteをしているのでそこが本丸」と いう見込みを立てたが誤りだった。実装を読むと、ポート直叩き・PCINT・millis()停止まですべて済んでいた。誤 解の元は次のコメントである。

delayMicroseconds(addrSettleUs); // Nano-1側の16本分のdigitalWrite完了を待つマージン

これは直叩き化する前の古い記述が残っていただけで、実コードは3命令しか使っていない。コメントを鵜呑みにし て実装を見なかった。

そこで待ち時間を振って実測したところ、明確な回帰が得られた。

1バイトあたり所要時間 ＝ 1.011 × 待ち時間 ＋ 34.1 us

傾きがほぼ1なので待ちはそのまま効くが、問題は切片の34usである。待ちを0にしても36us/バイトより速くならな い。内訳のうちシリアル送信1Mbps 8N1の10us/バイトは物理的な下限であり削れない。残る約26usはArduinoのシリ アル実装（リングバッファ、割り込み）、関数呼び出し、ループ処理である。

331us（初期） | （89us で図の外へ続く）

80us（20/20/5）

47us（5/5/3 採用）

36us（待ち0の床）

20 | 40 | 60 | 80
1バイトあたりの所要時間 [us]
固定費（回帰の切片 34.1us） | 待ち時間（傾き1.011）
うちシリアル1Mbps 10us | うち実装の間接費 26us

図6 1バイトあたり所要時間の内訳。待ちを0にしても36usの床が残り、その約4割はシリアル送信の物理的下限である。

なお、Nano-2の制御ピンをポート直叩き化する変更も実施したが、計算上24us削れるはずのところ実測は77.7us→ 79.6usでほぼ変化がなかった。見込みが外れた事実として記録しておく。

5.3 OSCRとの構造差

OSCRは1バイトあたり約375ns（アドレスを置いて6NOP待って読むだけ）で読み出す。本装置は約48usであり、約1 28倍の差がある。この差は実装の巧拙ではなく構造に由来する。

表10 読み出し1バイトあたりの構造比較

項目 | OSCR (sanni) | 本装置
/RD | 起動時にLow固定、以後不動 | バイトごとにLow→High
/ROMSEL (/CS) | 起動時にLow固定、以後不動 | バイトごとにLow→High
アドレス生成 | PORTF/PORTKへ直接書く | STROBEでNano-1のカウンタを+1
バンク生成 | PORTLへ直接書く | STROBEでNano-3のカウンタを+1
データの行き先 | SDカードへ直接書き込み | USBシリアルでPCへ（1Mbps）
1バイト所要 | 約375 ns | 約48 us

本装置の構造上、シリアル転送が律速である。OSCRはSDカードへ直接書くためシリアル送信が存在しない。した がって375ns/バイトには原理的に届かない。この128倍の差は、7章で述べるSA-1攻略において決定的な意味を持つ

。

6. 結果

2026年8月時点で読み出しに成功したタイトルを示す。総和欄は、ROMサイズを正しく解釈したうえでヘッダ申告 値と全バイト総和が一致したことを表す。CRC32欄の印は、記録上No-Introのデータベースと照合したことが確認で

きるものに限って付けた。

表11 読み出しに成功したタイトル一覧（全ファイルを再検証した）

タイトル | サイズ | map | CRC32 | 総和 | No-Intro
SUPER MARIOWORLD | 512 KB | 0x20 | 0ec0ddac
SIMCITY | 512 KB | 0x20 | a39fd8d8
SUPER MARIO KART（DSP-1） | 512 KB | 0x31 | c8002453
FINAL FANTASY 4 | 1 MB | 0x20 | caa15e97
MARIOPAINT | 1 MB | 0x20 | 38c9626c
SUPER PUYOPUYO | 1 MB | 0x30 | 9b386875
STAR FOX（Super FX） | 1 MB | 0x20 | 41a60b3f
DRAGONQUEST 1・2 | 1.5 MB | 0x20 | 98bb6853
DRAGONQUEST5 | 2 MB | 0x20 | a19c95d1
SUPERMARIO COLLECTION | 2 MB | 0x20 | 232bb5b8
Street Fighter 2 | 2 MB | 0x20 | 5556c5c9
YOSSY'S ISLAND（GSU-2） | 2 MB | 0x20 | 343e0dfb
夜光虫 | 2 MB | 0x30 | 0cd0e8d8
KAMAITACHI NO YORU | 3 MB | 0x20 | 71c631aa
SUPER DONKEY KONG | 4 MB | 0x31 | 50f2d1bc
SUPER MARIO RPG（SA-1） | 4 MB | 0x23 | 5527071e
KIRBY SUPER DELUXE（SA-1） | 4 MB | 0x23 | 1f35f230

17タイトル、合計約32MB。所要時間は現在の設定で2MBあたり約3分である。初期には1タイトルあたり20回以上の ダンプと多数決マージを要していたが（Super Puyo Puyoは27サンプル）、4.1節の解決以降は一発で通るようになった。

6.1 副次的に得られたもの

バッテリーバックアップSRAMの吸い出し。ROMは焼き直せば同じものが手に入るが、セーブデータは世界に1つし かない。しかもカート内のボタン電池は寿命が近い。夜光虫で3スロットぶんのセーブがRetroArchで読み込めるこ とを実機確認した。

実装上の落とし穴は /ROMSEL の極性がマッピングで逆になることだった。SNESの /CART がアサートされる条件は「バンク $40-$7D は全アドレス、バンク $00-$3F は $8000-$FFFF

のみ」であるため、LoROM（$70:0000-$7FFF）ではアサートし、HiROM（$20:6000-$7FFF）ではアサートしない。

DSP-1カートは $C0 から読む。スーパーマリオカートはHiROM 512KBとして8バンク読めるが総和が合わない（実測0x110e／期待0x8a23）。DSP-1がバンク $00-$3F の $6000-$7FFF にマップされ、8KB×8バンク＝64KB分がROMではなくDSPの応答になるためである。領域ごとに異なるバイト値 の種類数を数えると一目で分かる。

領域 | 異なるバイト値の種類数 | 解釈
$4000-$5FFF | 200種 | ROM
$6000-$7FFF | 4種 | DSP-1に乗っ取られている
$8000-$9FFF | 255種 | ROM

HiROMではバンク $C0 以降にもROM全体がマップされ、そちらにDSP-1は居ない。開始バンクを $C0

に変えるだけで総和もCRC32も一致した。

オフラインのタイトルデータベース。RetroArch同梱の .rdb（No-Intro準拠、7,621件）を読むMessagePackデコーダを 外部ライブラリなしで実装した。3.3節で述べた「ヘッダのサイズ申告が2の累乗に切り上げられる」問題に対し、 正確なバイト数を引ける。ネットワークアクセスは不要である。

## 7. SA-1 — クロックを与えず、認証を通す

SA-1搭載カートリッジ2タイトルの読み出しに成功した。本章は成果の報告であると同時に、なぜ25日もかかった のかの分析である。必要だったのはCIC認証と、カートリッジにクロックを一切与えないことだった。文献が必須と するマスタークロックは要らなかった。

表12 SA-1搭載カートリッジの読み出し結果

タイトル | サイズ | CRC32 | 総和 | 所要 | Snes9x
Super Mario RPG (Japan) | 4 MB | 5527071e | 0x4575 一致 | 95秒 | Checksum OK
Hoshi no Kirby Super Deluxe (Japan) (Rev 2) | 4 MB | 1f35f230 | 0xf602 一致 | 95秒 | Checksum OK

カービィは電源を入れ直した2回目の読み出しが1回目と0バイト相違で、再現性がある。両タイトルともRetroArch （Snes9xコア）が ROM+RAM+BAT+SA-1 と正しく認識し、エラーなく起動する。

7.1 なぜSA-1が難しいと思われていたのか

SA-1は10.74MHz動作の65816であり、ROMとバスの間に位置するバス調停チップである。この構造から「SA-1を通 してもらわなければROMに届かない」と考えられてきた。本報告の初版にも、筆者はそう書いた。

文献も一致してそう述べている。sanniのOpen Source Cartridge Reader（OSCR）はSA-1を読む必須要件として、PIC1 2F629にsnesCICを書き込んで実装することと、Si5351によるクロック供給を挙げている。nesdevのフォーラムにも「 21.477MHzがSA-1の認証にとって決定的だった」とある。

本装置ではそのどちらも使っていない。

7.2 実際の構造 — Super FXと同型だった

正しい理解はこうである。SA-1はクロックを与えなければ眠っており、ROMは素通しで読める。クロックを与える と起動してバスを掌握し、自分の状態を返すようになる。つまりクロックを与えるほど読めなくなる。

SA-1は「直列だから読めない」のではなかった。眠らせれば素通しになる

ROM

SA-1
眠っている クロック無し | カートエッジ

ROMが素通しで読める

（セーブ領域には届かない）

ROM

SA-1
起きてバスを握る クロック有り | カートエッジ

ROMはSA-1に握られる

（かわりにセーブ領域が読める）

この2つは両立しない。カート1番へのクロック配線1本で切り替わる。

図7 クロックの有無で見え方が反転する。眠っているSA-1はROMを素通しにするが、セーブ領域には手が届かない。

これは本報告の4.2節で述べたスターフォックスの結論とまったく同じ形である。当時こう書いた——「クロックが 無いから通せない」ではなく「クロックが無いから大人しかった」が正解だった、と。同じ結論が、別のチップで もう一度現れた。

過去の観測が、すべて逆向きに読み直せる。マスタークロックを供給していた時期、SA-1はバンク$C0に対して0x02 や0x34を返していた。これを「施錠されている」と解釈していたが、実際は起動したSA-1がバスを握って自分の状 態を返していた。読めなかったのではなく、こちらが起こしていた。

7.3 誤った結論と、その原因

本報告は当初、この章に「CIC認証も不要だった」と書いた。それは誤りである。原因は実験の順序による交絡であ り、記録として残す価値があるので経緯を書く。

誤った根拠は次のものだった。

① CIC認証を行うファームで、カービィ成功・再現成功・マリオRPG成功
② 認証しないファームに書き換えて「CICなしでも5/6で成功」

②を独立した検証として扱ったが、独立していなかった。①でCIC認証を何度も通したあとの状態で②を実行してい る。SA-1のBW-RAMは電池でバックアップされており、状態が電源サイクルを越えて残る経路が実在する。

表13 交絡を除いた検証（2026-08-29）

条件 | 試行 | 成功
CIC認証なし（一度も認証していない状態から） | 16回
CIC認証あり | 2回 | 1（2回目で成 功）

順序を変えれば結論が変わる実験を、独立した検証として扱っていた。4章で「1回の観測を結論にするな」と繰り 返し述べておきながら、ここでは観測の独立性という別の前提を踏み外している。試行回数を増やしても、交絡は 消えない。

この誤りは指摘によって発見された。装置の製作者から「昨夜の実験はCIC認証→CICなしの順だったから、SA-1に 認証が残っていたのかもしれない」という指摘があり、検証したところ覆った。実験を設計した側は、自分が置いた 順序を疑いにくい。

7.4 実際に必要だったもの

表14 SA-1の読み出しに必要な条件（交絡を除いた検証にもとづく）

項目 | 要否 | 理由
CIC認証 | 不明 | 各20回の全ダンプで 40% 対 45%。差を検出できなかった（7.6節）
起動読み（本番前に短く読む） | 必要 | 無いと 0/20。$E0 を1バンク読むだけで 18/20 になる
マスタークロック（カート1番） | 不要 | 1〜8MHzなら読めるが得はない。21.477MHzは速すぎて有害。ただしLO
Wに落としてはいけない（0/29）。浮かせること
システムクロック（カート57番） | 出さない | sanniの手順でも明示的に禁止されている
1回の接続で全64バンクを読み切る | 必要 | SA-1は時間とともに提示内容を変える。4MBを95秒で読み切る
接触の良いカートリッジ個体 | 必要 | 同一タイトルでも個体で結果が変わる
リトライ | 必要 | 最良条件でも全ダンプ成功率は70%前後。3〜4回に1回は失敗する

マスタークロックが不要である点は、交絡の影響を受けていない。2026-08-29の検証では、I-RAM窓が単一値である こと（＝SA-1が起動していないこと）を確認したうえで読み出しに成功している。

速度が要件になるのは、SA-1が時間とともに提示内容を変えるためである。バンクごとに接続し直す方式では1回の 吸い出しに5〜7分かかり、その間に状態が変わる。1回の接続で読み切る連続バンクモードにより95秒へ短縮したこ とで、この問題は消えた。5.3節で述べたOSCRとの128倍の速度差は、ここでだけ実際に効いていた。

7.5 対照実験でわかったこと（355試行）

上の要件は当初、失敗の観察から推定したものだった。2026年9月1日、条件を1つずつ変えて各20回ずつ取り直した 。判定は「起動読みの後に$C0を1バンク読み、既知の正解とバイト単位で一致するか」。

起動読みの中身 | 成功 | 95%信頼区間
起動読みなし | 0/20 （0%） | 0-16%
$C0 を1回（sanni相当） | 13/20 （65%） | 43-82%
$C0 を6回 | 13/20 （65%） | 43-82%
$E0 を1回 | 18/20 （90%） | 70-97%
6バンク全部 | 18/20 （90%） | 70-97%

効いているのは回数ではなく、どのバンクを叩くかである。$C0 を6回叩いても1回と変わらず、$E0 を1回叩けば6バンク全部と同じ結果になる。

訂正。 本稿では当初「sanniのダミー読みでは足りない」と書いていた。45回連続の失敗が根拠だったが、実験では6 5%通る。真の失敗率が35%なら45連敗の確率は10のマイナス20乗であり、事実上ありえない。あの45回は、いまと は別の何かが違っていた。それが何かは分かっていない。

クロックについても同じ方法で測った。ハイインピーダンス 17/20、2.667MHz 16/20、4.000MHz 10/20、LOW固定 0

/20。カート1番をLOWに落とすと読めなくなり、消費電流も20mA増える。「駆動しない」ことと「LOWにするこ と」は違う。従来は配線していなかったため結果的に浮いており、区別が付いていなかった。

窓の寿命も測った。起こしてから0秒・10秒・30秒・60秒・180秒待って読んでも、成功率は80%・80%・80%・80% ・73%で落ちない。窓は閉じない。「1回の接続で読み切れ」という要件は、窓の寿命が理由ではないことになる。

判定方法そのものも検証した。1バンク判定と全64バンク読みを20回突き合わせ、一致は18/20。外れた2件はどちら も「判定は成功・全体は失敗」という楽観側で、64バンクすべてがROMらしく見えるのにCRCだけ違う型だった。 本節の成功率はすべて約10%の上振れを含む。基準80%に対し、実際の全ダンプ成功率は70%前後と見るのが妥当

である。

7.6 CIC認証は、結局のところ分かっていない

本稿は当初「CIC認証は不要」と書き、次に「必要」と訂正した。その訂正の根拠は「CICあり4回中4回成功、CIC なし6回中1回成功」だった。2026年9月2日、全64バンクをバイト単位で比べて各20回取り直したところ、差は消え た。

条件 | 1バンク判定 | 全64バンク | 95%信頼区間
CICなし | 11/20 | 8/20 （40%） | 22-61%
CICあり | 13/20 | 9/20 （45%） | 26-66%

それでも本稿は「CIC認証は不要」とは書かない。この問いでは既に3回結論を変えている。そして今回の結果は差を 否定できなかっただけであり、「同じである」ことを示したものではない。書けるのは「20回ずつでは差が検出でき なかった」までである。

なお、CICなしのときに観測された「64バンクすべてがROMらしく見えるのに中身が3割違う」という壊れ方は、CI Cありでも同じ頻度で起きた。あれはCIC認証の効果ではなく、元々ある失敗モードだった。

実際の成功率も、この測り直しで下方修正された。1バンク判定では80〜90%だが、全64バンクを正しく吸えるのは 40〜60%である。判定は40回中7回が偽陽性で、楽観側に偏っていた。SA-1は2回に1回失敗する。リトライ前提

の運用しかない。

スーパーマリオRPGでも同じ手順を20回試し、10回成功した（50%）。カービィと同じ水準であり、この成功率は カート個体ではなくSA-1の性質である。失敗した10回はほぼ全て異なるCRCで、しかも64バンクすべてがROMらし く見え、ヘッダの『SUPER MARIO RPG』まで読めた。弾いたのは総和検査だけだった。

7.7 「1回の陰性を結論にしない」

成功率が70〜90%であることは、判断の方法そのものに影響する。スーパーマリオRPGは1回目の読み出しが施錠状 態だった。そこで打ち切っていれば「マリオRPGは読めない」と結論していた。2回目で成功している。

同じ日、筆者は1回の陰性から誤った結論を3回出した（「データ線が断線している」「クロックが届いていない」 「カートを挿すとクロックが死ぬ」）。いずれも試行回数を増やしただけで消えた。

確率的な現象に対して、単発の観測は証拠にならない。これは4章で扱った「決定的か確率的かを見分ける」の裏返 しである。決定的な誤りは1回の観測で捕まえられるが、確率的な現象は陰性を何回積んでも陰性の証明にならない

。

7.8 セーブデータは、逆に取り出せない

ROMとは対称の問題が残った。セーブデータ（BW-RAM）はSA-1が調停しており、SA-1が動作していなければ読 めない。

クロックを与えない → SA-1は眠る → ROMが読める／BW-RAMには届かない
クロックを与える → SA-1が起きる → BW-RAMが読める／ROMはSA-1に握られる

両立しない。カート1番へのクロック配線1本の抜き差しで切り替わる。

表15 BW-RAM窓（$6000-$7FFF）の応答

条件 | I-RAM窓 | BW-RAM窓 | 判定
クロック無・CIC無 | 0x00一色 | 0x00一色 | SA-1が眠っている
クロック無・CIC有 | 0x11一色 | 0x11一色 | 同上
クロック有・CIC有 | 228種 | 204種 | SA-1が起動。実データ

SA-1を起動させた状態で読み出した8KBは、ゲーム自身が初期化する空セーブと同じ位置に同じ構造を持っており 、本物のセーブデータであることは間違いない。しかしゲームに読ませると拒否され、空データで初期化される。

読みごとの相違が8192バイト中27〜166バイトあり、多数決でも詰めきれていない。セーブデータはROMと違い、1 バイト違えば全体が無効になる。原因が読み取り誤差なのか、起動したSA-1が自分でBW-RAMを書き換えているの かは未検証である。同一の電源投入内で連続2回読んで比較すれば判別できる。

なお、スーパーマリオRPGはSRAM 32KBだが窓は8KBであり、残りはSA-1のレジスタ $2224 でブロックを切り替える必要がある。/WR
を+5Vに直結した読み出し専用機では書き込めないため、原理的に到達できない。カービィはSRAM 8KBなので窓1枚で全体が入る。

### 7.7 先行実装との関係

外部ダンパーでSA-1に対応していると明記されているのはOSCRだけであり、そのソースは全て読んだ。本装置は それとは別の解に到達したことになる。

表16 SA-1に対する2つの解

| OSCR (sanni) | | 本装置
方針 | SA-1を起動させて正規の手順で通す | SA-1を眠らせたままROMだけ抜く
必要な追加装備 | PIC12F629（snesCIC）＋ Si5351 | なし
ROM読み出し | 可能 | 可能
セーブデータ | 可能（SA-1が動作しているため） | 不可

両者は優劣ではなく目的が違う。SA-1を起動させるOSCRの方針は、セーブデータまで扱える点で本装置より広い 。本装置の方針は、ROMだけでよいなら追加部品ゼロで済む点で単純である。

「追加で一つも部品を購入しない」という制約から出発した本プロジェクトが、結果として追加部品を必要としな い解に到達したのは偶然ではないかもしれない。部品を足せる立場にあれば、足す方向の解が先に見つかる。

8. 考察

### 8.1 制約が構造を決めた

1.2節で述べたとおり、Nano 3台という構成は消去法で選ばれた。I/Oが足りないから分けるしかなかったのであって 、設計思想があったわけではない。しかしその結果として役割ごとに専任のマイコンを持つ構造が生まれた。

CICは自前のクロックを持たず、与えられたパルスの個数で状態を進める（7.2節）。1ビットあたり372パルスを1つ も取りこぼさずに送る必要がある。3.072MHzなら1ビット周期は121us、1ラウンド16ビットで1.94ms、16ラウンド完 走で31msである。この間、数msのブロッキングも許されない。

表17 CIC担当を確保する構造の比較

構成 | 並行する仕事 | CIC担当
OSCR (sanni) | Mega 1枚に集約。I/Oは足りる | SDカード書き込み・表示・U
SB

別途PIC12F629が必要

本装置 | Nano
3枚に分散。I/Oのため仕方なく

Nano-3は本来バンク生成のみ 3台目がそのまま担える

MegaはSDカードへの書き込み・表示更新・USB処理を抱えており、us精度のパルス生成を並行できない。だから専 用チップを足している。本装置は「1枚では足りない」という弱みのおかげで、CIC専任のマイコンが追加コストゼ

ロで手に入っていた。

強みがそのまま弱みになり、弱みがそのまま強みになった。ただし正確に言えば、これは先見性ではない。Nano-3 は本来バンクアドレス生成係であり、CIC役は後から兼務させたものである。制約が生んだ構造がたまたま適合した というのが正確なところである。

8.2 そして同じ罠を、規模を小さくして踏んだ

SA-1実験のためNano-3にCIC役とバンク生成役を兼務させたところ、割り込み競合でバンクアドレスを2回壊した。 loop() が PORTB
をリードモディファイライトで回している隙間にPCINT0のISRが入り、ISRが書いたバンク上位2ビット（PB0, PB1 = A22, A23）を古い値で上書きしていた。バンク $C0 以降はこの2ビットが両方1なので、潰れると $00-$3F のまったく別のバンクを読むことになる。

実測での現れ方: 「前回と98%相違（64,106/65,536）」の頻発／bank_196.bin と bank_197.bin が完全に同一／ヘッダの補数対がNG

ピンが重複していないことは確認していたが、同じポートレジスタを割り込みとメインループの両方が触る点を見落 としていた。重複はピン単位ではなくレジスタアクセス単位で見る必要がある。精密なタイミングを要する仕事は専 任させること——OSCRのMegaが陥ったのと同じ罠を、規模を小さくして踏んだ。

### 8.3 誤診に共通する形

本報告に記録した誤診は、いずれも同じ形をしている。もっともらしい説明が先に立ち、それが正しいかを測らず に次の実験へ進む。そして測っていないので、その後の実験がすべて無効になる。

表18 誤診の一覧と、気づいた契機

誤診 | 気づいた契機
データ化けは電源／デカコン／電圧降下のせい | 毎回きっかり30,966バイトという決定性
Super FXはバスを支配するので読めない | 安定化電源を直結したら相違0になった
読むたび化けるのは電源不足（ヨッシー） | 数分の間に0xFFが12倍動いた（15,306→1,268）
32KB周期の繰り返しはA15の配線不良 | はんだ付けをやり直しても変化なし。LoROMの正常な 挙動だった
バンク0の前後半が違う＝HiROM | 前半は全部0x00で死んでいただけ。8KB刻みのゼロ率で 判明
1バイトずれるのはストローブの数の問題 | 補正したら2バイトずれた。真因はホスト側の受信バッ ファ未クリア
CICクロック入力は生きている（波形が静止） | 測定器側のバグ。生値を記録したらクロックとリセット が短絡していた
短絡を直したら安定Highになった＝成立 | 数時間後にチップが焦げた。安定Highは動けなくなった 部品の沈黙だった
Nano-1のアドレスが進まないのはファームか配線 | 受け手にパルスを数えさせて切り分け。ソケットに挟ま った金属片だった
高速化の本丸はNano-1のdigitalWrite | 実装は最適化済み。古いコメントが残っていただけだっ た
sanniはSA-1にCIC認証をしていない | 握手はコードでなく別チップ(PIC12F629)が独立して やっていた

特に重い失敗を2つ挙げる。ひとつは測定系そのものが壊れていた件である。CIC認証の「成立」判定を5回作り直し ては、すべて失敗時に条件を満たされた。原因は判定基準ではなく測り方で、analogRead() は1回に約100usかかり 、相手が数十us単位で動いているなら意味のあるしきい値は存在しない。ADCをフリーランニングにして約6.5us間 隔で900サンプルを持ち帰る簡易ロジックアナライザを作って初めて、クロック入力とリセット入力が短絡していた ことが分かった。この時点で、それ以前の実験は全て無効になった。

もうひとつは規定外で動かした部品を信用した件である。短絡を修正した直後、リセット出力は「Highで安定、351 msにわたり遷移ゼロ」になった。これは最初に「成立の証拠」として定義した条件そのものだったが、カートは何 も返さず、数時間後にチップは焦げた。抜いて測るとクロック入力・リセット入力・GNDの3本が導通しており、入 力段が内部で焼損していた。「直った」と「間に合った」は別の話である。

8.4 本装置の実用性について

率直に述べると、費用対効果は良くない。ありあわせの部品で動かすには適しているが、安価に仕上げたいのであ れば既製品や他プロジェクトを参照した方がよい。ただし4.1節の解決以降は一発で通るようになったため、初期の 「1カートあたり20回以上吸わないとまともなデータが得られない」状態からは大きく改善した。

設計上の反省として、相手がどう振る舞うか分からない信号線をマイコンの端子へ直結したのは甘かった。片側がL owに固定された線に電流が流れ込む形になり得る。直列抵抗を入れるべきだった。

## 9. 結論と今後

追加部品を購入しないという制約のもとで、Arduino Nano 3台によるSFCカートリッジ読み出し装置を製作し、15タ イトルの読み出しと検証に成功した。特殊チップのうちSuper FXとDSP-1には対応した。

本報告の主たる成果は装置そのものではなく、「読むたび内容が変わる」という単一の症状を4つの原因へ分離する 手続きである。「相違バイト数の段階に対する単調性」と「0xFF率の安定性」という2指標で、電源不足・接触不良

・タイミング余裕不足・バス調停を区別できることを実測で示した。この手続きは装置に依存せず、他のカートリ ッジ読み出し装置にも適用できる。

SA-1については2タイトルの読み出しに成功した。必要だったのは、文献が必須としている装備を用意することでは なく、それらを一切与えないことだった。クロックを与えなければSA-1は眠り、ROMは素通しで読める。先行実装 がCIC認証を要求するのは、その実装がクロックを供給する設計だからであり、設計選択が自身の要件を作っていた

。

残る未達はSA-1カートリッジのセーブデータである。BW-RAMはSA-1が動作していなければ読めず、ROMの読み 出しとは両立しない。実データの取得までは到達したが、byte単位で正確な複製には至っていない。

9.1 次に行うべきこと

優先 | 項目 | 根拠
| SA-1のセーブデータを正確に取 る | 実データまでは到達している。読みの誤差か、起動したSA-1自身による書き換えかを 、同一電源投入内の連続2回読みで判別する（7.6節）
| 読み出しのさらなる高速化 | シリアル送信の10us/バイトは物理下限。残る26usの間接費を削る（UDR0直書き、読 み出しと送信のパイプライン化）。SA-1では速度がそのまま成功率に効く
| 他のSA-1タイトルでの検証 | 本報告の結論は2タイトル・3個体で確認したものである。一般性の主張には母数が足 りない

なお本報告の結論には、明示しておくべき限界がある。「CIC認証もマスタークロックも不要」は本装置・2タイト ル・3個体で確認した事実であり、他の環境や他のSA-1タイトルで同じとは限らない。とくにカートリッジ個体差 の影響は無視できず、カービィは3枚目で初めて成功している。

## 付録A 装置の諸元

項目 | 内容
制御ボード | Arduino Nano（ATmega328P、16MHz、5V）×3
カートリッジコネクタ | ジャンクのスーパーファミコン本体から摘出した62ピン（実測ピッチ2.50mm、列間隔・キー溝とも非標
準）
配線 | Nano↔カートはUEW（ポリウレタン銅線）、それ以外はAWG22
基板 | 2.54mmユニバーサル基板。PCBは使用していない
表示 | SH1106 OLED。ハードウェアI2Cピン(A4/A5)はデータバスD4/D5で埋まっているためソフトウェアI2Cで
| 逃がしている
ホスト通信 | USBシリアル 1,000,000 bps（Nano-2のみ）
電源 | 通常はUSBバスパワー1本で動作。消費電流の大きいカートでは安定化電源から5Vバスへ直結が必須
読み出しタイミング | RD=5us / ADDR=5us /
PULSE=3us（47us/バイト）。ホストから起動のたびに送るため書き込み直しは不要
CICクロック源 | Nano-2 D11(OC2A)。16MHz/(2×(1+1))＝4.000MHz、誤差0%
マスタークロック源 | 摘出水晶＋裸ATmega328P（CKOUTヒューズ、lfuse=0xBF）で21.477MHz

## 付録B OSCRとのクロック設定の比較

OSCRはSi5351を用いる。設定値の単位は0.01Hz（センチヘルツ）である。投入順序も指定されており、CLK2(CIC) → CLK0(マスター) → 最後にCLK1(CPU) となる。

カートピン | 信号 | OSCRの値 | 本装置
| EXT / マスタークロック | 21.477272 MHz | 21.477 MHz（摘出水晶）
56 | CICクロック | 3.072 MHz | 4.000 MHz（実機旧基板と同値）
57 | システム(CPU)クロック | SA-1では出さない | 無結線（一致）
33 | REFRESH | Low | Low（一致）
26 | RESET | High | High（一致）

CICクロックの周波数について、当初「21.477/7＝3.0682MHzは実機と同じ導出」と記録したが誤りだった。CICクロ ックは映像系（21.477MHz）ではなく音声系（APUの24.576MHz÷8）から来る。数字が近いのを見て、それらし い説明を後付けしていた。また旧型の実機基板は4MHzでCICを回していた実績があるため、本装置は16MHzから誤 差0%で作れる4.000MHzを採用している。

## 付録C 参考にした資料

・ SNESdev Wiki — Cartridge connector.
62ピンカードエッジの完全なピンアサイン。本装置の配線表はこの情報が基になっている。

・ NESdev Forums — SNES Edge Connector (t=11389).
「2.54mmではなく2.50mmピッチであり、列間隔とキー溝も非標準」という、自作時に最も重要な指摘を得た。

・ sanni — Open Source Cart Reader (GitHub). カートリッジダンパーの事実上の標準実装。ピンアサインとメモリマップ処理の正 解を確認する基準として参照した。SA-1関連ではSNES.ino、Discussion #173（SA-1クロックの校正手順）、公式Wiki「Flashing the snesCIC」を参照している。

・ ikari — SuperCIC / snesCIC. supercic-lock.asm および supercic-key.asm。「Key はカートリッジ側、Lock は本体側」という役割の定義、および毎ビットの「両線Low」検査の実装。

・ segher — 本家CIC(D411)の逆アセンブル (Neo-Desktop/SNES-CIC-Disassembly)。SuperCICの再実装ではなく本物のチップのコ ード。命令数を数えて372パルス/ビットを確定した根拠。

・ MAME — SM590の実装。CICの命令セットの確定に使用。

・ nocash / NESdev Forums (t=19441)。旧型の実機基板がCICに4MHzを供給していたという記述。

・ libretro-database / No-Intro。タイトル検索とROMサイズ特定に用いた .rdb データベース（7,621件）。

・ Snes9x / RetroArch。ダンプ結果の検証。Snes9xコアの Checksum OK / Invalid Checksum の判定は、「ヘッダだけ正しくて本体が壊れている」状態を発見する決め手になった。

・ olikraus — U8g2 (BSD-2-Clause)。SH1106
OLEDの駆動。ハードウェアI2Cピンが埋まっていたためソフトウェアI2C対応が決定的に助かった。

・ dumping.guide。SA-1対応の実装に関する調査。

本報告における「確定」と「仮説」の区別について
本文中の数値はすべて実測値であり、装置の記録（README、開発史、CIC実験ノート）および出力ファイルの再検 証から取っている。検証していない推論には、その旨を明記した。とくに7.6節のクロック停止仮説と7.7節の制御線 仮説は、因果の筋は通るが未検証である。

── 門の前までは来ている。記録は続く。

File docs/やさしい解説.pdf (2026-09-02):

# ゲームカセットの中身を

# そっくり写し取る機械を作った話

むずかしい言葉を使わない説明

2026年8月・25日間の記録

ひとことで言うと

30年前のスーパーファミコンのゲームカセットから、中身のデータをそっくりそのままパソコンに 写し取る機械を、新しい部品を一つも買わずに作りました。

最後には、世界でもほとんど誰も成功していない「いちばん手強いカセット」からも中身を取り出 せました。しかもその方法は、専門家が必要だと言っていた装置を何一つ使わない、拍子抜けする ほど単純なものでした。

この文書には専門用語をほとんど出しません。
出すときは必ず、その場で普通のことばに言い換えます。

## 1. 何を作ったのか

ゲームカセット
中に「ROM」がある

自作した装置
Arduino 3台

パソコン
ファイルとして保存
読む | 送る

カセットの中身をそっくりそのままパソコンへ写し取る装置です。

遊ぶためではなく、失われる前に「保存」するために作りました。

図1 カセットの中身を読み取って、パソコンにファイルとして保存します。

そもそも、なぜそんなことを？

ゲームカセットは永遠には持ちません。中の部品は少しずつ傷みますし、端子が汚れて読めなくなる こともあります。とくに深刻なのがセーブデータです。

昔のカセットは、セーブの記録を保つために中に小さな電池が入っています。この電池が切れると、

それまでの冒険の記録は一瞬で消えます。そして30年前の電池は、もういつ切れてもおかしくありま

せん。

ゲームそのものは、また同じカセットを探せば手に入ります。でも自分が遊んだセーブデータは、世 界に一つしかありません。だから中身を写し取っておく意味があります。

中身って、どんなもの？

ゲームの中身は、ぜんぶ「数字の並び」です

78 | 9c | 00 | 42 | 9c | 0c | 42 | 9c | 0b | 42 | 9c | 40

…… これが 400万個 つづきます

絵も音楽もセリフも、すべてこの数字に化けて入っています。

1個でも間違って読み取ると、ゲームは動きません。だから正確さがすべてです。

この装置がやるのは「400万個の数字を、1個も間違えずに読み上げること」。

図2 カセットの中身は、400万個の数字の並びです。

ゲームの絵も、音楽も、セリフも、キャラクターの動きも、すべてこの数字の並びに化けて入ってい

ます。この装置の仕事はその400万個を、1個も間違えずに読み上げることです。

1個でも間違えると、ゲームは正しく動きません。「だいたい合っている」では意味がない、という

のがこの作業の難しさです。

## 2. なぜ3台も使うのか

カセットとやりとりするには、34本以上の電線を同時に操る必要があります。ところが手元にあっ

た小さなコンピュータ（Arduino）は、1台で18本しか扱えませんでした。

本来なら、もっと大きくて高いものを買えば1台で足ります。でも今回は「新しい部品を一つも買わ

ない」という縛りを自分に課していました。そこで、手元にあった小さいものを3台使って分担させ

ることにしました。

1台では手が足りないので、3台で分担しました

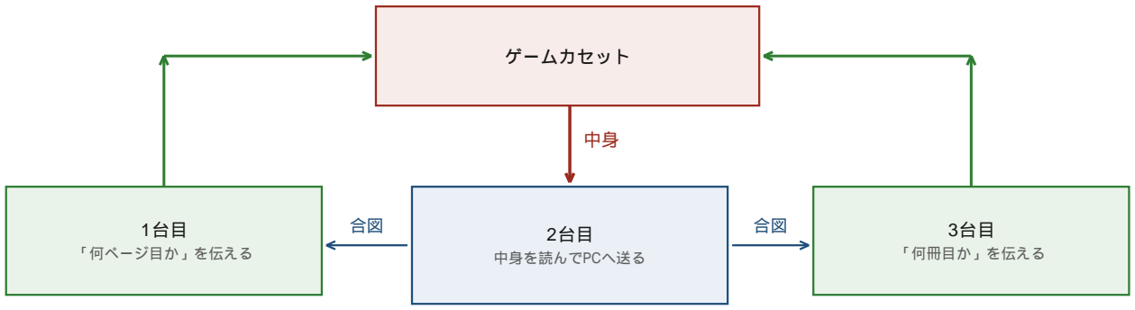
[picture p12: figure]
ゲームカセット; 「何ページ目か」を伝える; 中身を読んでPCへ送る; 「何冊目か」を伝える

図書館で本を読み上げるようなものです。「何冊目の何ページ」を係が伝え、別の係が読み上げる。

図3 図書館で本を読み上げるような分担です。

この「仕方なく」が、あとで効いてきます

じつはこの構成は、世界で一番有名な同種の装置よりもある一点で有利でした。あちらは大きなコン ピュータ1台で全部やるので、他の作業をしながら細かい時間を刻むことができず、専用の部品を追 加で買い足す必要があります。

こちらは最初から3台に分かれているので、1台を専任にすることがタダでできました。「1台では足 りない」という弱みが、そのまま強みになっていたわけです。

ただし正直に言えば、これは狙ってやったことではありません。部品を買えなかったから、そうする しかなかっただけです。結果的に噛み合っただけ、というのが正確なところです。

## 3. いちばん苦労したこと

この25日間で本当に大変だったのは、機械を組み立てることではありませんでした。「うまくいかな

い理由が分からない」ことでした。

しかも症状はいつも同じです。「同じところを読んでいるのに、読むたびに違う答えが返ってくる」

。これだけです。

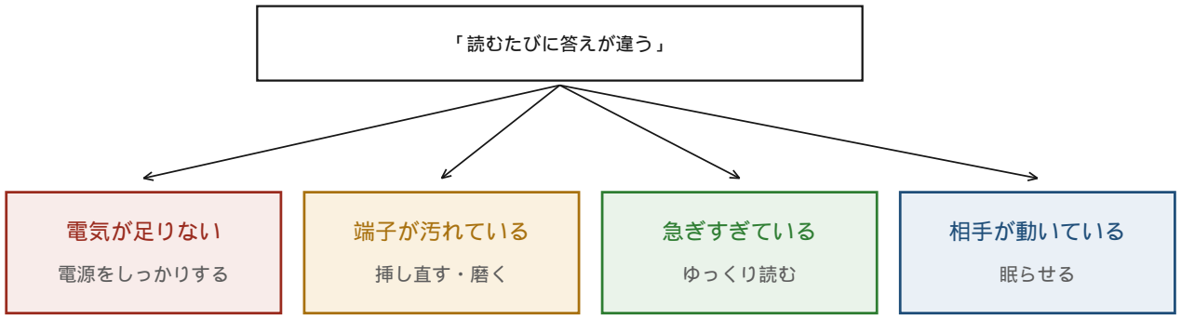
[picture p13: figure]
「読むたびに答えが違う」; 電気が足りない; 電源をしっかりする; 端子が汚れている; 挿し直す・磨く; 急ぎすぎている; ゆっくり読む; 相手が動いている; 眠らせる

たった一つの症状の裏に、まったく違う4つの原因がありました。

医者が「お腹が痛い」の原因を切り分けるのと同じで、

見分ける手順を作るまで、同じ間違いを何度も繰り返しました。

図4 同じ症状の裏に、まったく違う4つの原因がありました。

同じ原因を当てはめて、何度も間違えました

あるカセットで「電気が足りない」ことが原因だと分かりました。そこで次のカセットで同じ症状が

出たとき、当然また電気を疑いました。外れでした。今度は端子の汚れでした。

その次はまた同じ症状で、今度は急ぎすぎが原因でした。ゆっくり読めば正しく読めたのです。

見分ける方法を作りました

そこで、原因を切り分ける手順を考えました。難しいことはしていません。読む速さを5段階に変え

て、間違いの数がどう変わるかを見るだけです。

速さを変えたときの様子 | 犯人
ゆっくりにするほど間違いが減る | 急ぎすぎ。ゆっくり読めばいい
速さを変えても変わらない | 端子の汚れ。挿し直す
ゆっくりにすると、かえって増える | 電気不足。電源を強くする

3番目が意外なところです。ふつう「ゆっくりやれば安全」と思いますが、電気が足りていないとき は、ゆっくり読むほど長い時間だけ無理をさせるのでかえって悪化します。これに気づくまで、ずい ぶん遠回りしました。

## 4. 思い込みで失敗した話

この記録でいちばん多いのは、自分の思い込みで間違えた話です。せっかくなので、分かりやすいも

のを3つ紹介します。

その1 毎回きっちり同じ数だけ間違える

あるとき、読み取りがうまくいかなくなりました。電気のせいだろう、部品が足りないのだろうと、

いろいろ疑いました。全部はずれです。

転機は、10回読んでみて毎回きっかり同じ数だけ間違えていると気づいたときでした。もし電気の乱 れや汚れが原因なら、間違いの数はバラつくはずです。ぴったり同じということは、偶然ではなく仕

組みの間違いです。

調べたら、同じところを2回ずつ読んでいただけでした。1ページ読むごとに「次のページ」と伝える 係が、1回おきに合図を聞き逃していたのです。

教訓：数字がいつもぴったり同じなら、それは偶然の乱れではない。「壊れている」で止めずに「ど ういうふうに壊れているか」を測ったのが突破口になりました。

その2 測っている道具の方が壊れていた

ある晩、電気の様子を見るために測定用の線を1本追加しました。そしてその線から読み取った値を もとに、「ここが繋がりすぎている」「犯人はこの部品だ」と結論を出しました。

その測定用の線が、正しい場所に付いていませんでした。つまり全然関係ないところを測って、そこ から物語を組み立てていたのです。この間、製作者は「配線は正しい」と何度も言っていました。そ

ちらが正しかったのです。

教訓：新しい道具を使い始めたら、まず答えの分かっているもので試す。この日の午前中に「正解の 分かっているカセットで確かめよう」と自分で言っておきながら、自分の測定器には同じことをしま

せんでした。

その3 1回だめだったくらいで諦めない

最後の難関では、うまくいったりいかなかったりを繰り返しました。6回試して5回成功、というよう な具合です。

ここで1回失敗しただけで「これはダメだ」と結論すると、間違えます。実際この日、1回の失敗から

誤った結論を3回出しました。どれも「もう何回かやってみる」だけで消えました。

最後に成功したときも、1回目は失敗しています。そこでやめていたら、25日間は実らずに終わって

いました。

## 5. 最後の壁と、拍子抜けする答え

ゲームカセットの中には、特別な部品が追加で入っているものがあります。当時としては豪華な作り で、より複雑なゲームを動かすためのものです。

その中でも「SA-1」という部品が入ったカセットが、最大の難関でした。スーパーマリオRPGや、星

のカービィ スーパーデラックスがこれにあたります。

なぜ難しいと思われていたのか

この部品は、ゲームの中身と装置のあいだに見張り番のように立っています。だから「見張り番に話 をつけて、通してもらわないと中身に手が届かない」と考えられていました。

実際、世界的に有名な同種の装置の説明書にも、「専用の認証用の部品を追加で用意すること」が必 須条件として書かれています。そこで、その通りにやろうとしました。

見張り番と話をするための「合言葉」の仕組みを解読し、壊れたスーパーファミコン本体から部品を 取り出し、専用の回路を組み、何日もかけて挑みました。通りませんでした。

答えは、まったく逆でした

いちばん手強かったカセットの正体

ゲームの中身 | 見張り番
眠っている 何も与えない | 装置へ | 読める
ゲームの中身 | 見張り番
起きて通せんぼ 電気の合図を送る | 装置へ | 読めない

「起こして話をつける」と何日も頑張っていましたが、答えは逆でした。

図5 見張り番は、放っておけば眠ったままでした。

見張り番は、電気の合図を送らなければ眠ったままだったのです。そして眠っている見張り番は、通 せんぼをしません。中身は素通しで読めました。

こちらは「起こして話をつけよう」と何日もかけていたわけですが、起こしていたのは自分たちで、

起こすから読めなくなっていたのでした。

### 必要だったのは、精密な装置でも特別な部品でもなく、「見張り番を起こさない

こと」と「素早く読み切ること」、そして合言葉を通すことでした。

そして、いちど間違えました

実は一時期、「合言葉も要らなかった」と結論していました。そう思って文書に書き、インターネッ トで公開までしました。これは間違いでした。

なぜ間違えたか。実験の順番のせいです。

最初は合言葉を使って何度も成功させていました。そのあと「合言葉を使わない設定」に変えて試し たら、それでも読めた。だから「合言葉は要らない」と結論したのです。

しかしそれより前に何度も合言葉を通していたので、その影響が残っていた可能性がありました。カ セットの中には電池でデータを保つ部分があり、電源を切っても状態が残る仕組みが実際にあります

。

製作者の指摘で気づきました。

「昨夜の実験は合言葉あり→なしの順だったから、残っていたのかもしれない」と言われて、一度も 合言葉を通していない状態から試し直したところ、16回連続で失敗しました。合言葉を使うと、3回 中2回成功しました。

回数を増やしても、この間違いは見つかりません。順番そのものが間違っていたからです。そして実 験の順番を決めた本人は、それを疑いにくいのです。

それでも45回、続けて失敗しました

合言葉も用意し、見張り番も起こさない。条件は揃ったはずでした。それでも45回続けて失敗しま

した。

読み出そうとすると、いつも同じ「何も入っていない」という結果が返ってきます。そこで「見張り 番が門を閉ざしている」のだと考え、「時間を置けば開くのでは」「電気が足りないのでは」と、い

くつも仮説を立てては外しました。

### 解釈が間違っていました。

きっかけは、製作者が別の普通のカセットに差し替えたことでした。切り分けのために、そのカセッ トの「何も入っていない場所」を読んでみたところ、45回見ていたのと寸分違わぬ結果が出ました

。

「門が閉まっている」のではなく、「そこに何も置かれていない」だけでした。開錠の問題ではなく 、中身を出してもらう問題だったのです。

では、どうすれば出してくれるのか。答えは拍子抜けするほど簡単でした。

### いきなり全部を読もうとせず、先に少しだけ読んで声をかけておく。それだけで

### 、以後は全部読めるようになりました。

ノックもせずに扉を開けようとしていた、という話です。45回の失敗は、運が悪かったのでも装置が 悪かったのでもなく、手順が一段抜けていただけでした。

今度は、ちゃんと数えました

これまで何度も、数回の結果から早とちりして間違えてきました。そこで最後に、条件を1つずつ変 えながら355回読み出して確かめました。夜通し自動で動かした記録です。

分かったことを、いくつか。

・声をかけずに読むと、20回中0回しか読めない。手順は本当に必要だった ・声をかける場所を選べば、1回で十分。何度も繰り返す必要はなかった

・電圧を5.0Vから4.5Vまで下げても、成績は変わらない

・一度声をかけたら、3分待っても効果は消えない

そして、以前の説明の一部が間違っていたと分かりました。

「世界的に有名な装置のやり方では足りない」と書いていたのですが、実際に数えてみるとそのやり 方でも20回中13回は成功します。45回続けて失敗する確率としては、あまりにも低すぎます。

つまり、あの45回の時期は、いまとは別の何かが違っていたのです。それが何なのかは、まだ分かっ ていません。分からないことを、分かったふりで埋めないでおきます。

そして、合言葉の話がまた分からなくなりました

前の版で「合言葉は必要だった」と訂正したことを書きました。その根拠は「合言葉ありで4回中4回 、なしで6回中1回」という結果でした。

回数を20回ずつに増やして測り直したら、差が消えました。合言葉なしで20回中8回、ありで20回中

9回。ほとんど同じです。

それでも「合言葉は要らない」とは書きません。

この一点について、すでに3回も結論を変えているからです。そして今回の結果は「違いを見つけら れなかった」だけで、「同じだ」と示したわけではありません。書けるのは「20回ずつでは違いが分

からなかった」までです。

もうひとつ、成績も下方修正しました。先頭だけ見て確かめていたときは8〜9割成功しているように 見えましたが、全部を正しく読めているのは半分ほどでした。確かめ方が甘かったのです。

### 2回に1回は失敗する。だから毎回きちんと検算して、だめならやり直す。それが

### 正しい使い方でした。

スーパーマリオRPGでも同じ手順を20回試し、10回成功しました。カービィと同じくらいです。この

成績はカセットの個体差ではなく、この部品そのものの性質だと分かりました。

## 6. できたこと・できなかったこと

25日間の道のり

装置を作る

ふつうのカセットが
読めるまで

特殊なカセット

電気不足・端子・速さ
を切り分ける

最後の壁に挑む

見張り番を「起こす」
方法をひたすら探す

答えが出る

起こさなければ
読めた

ここに20日近く

図6 20日近くを「見張り番を起こす方法」に費やしました。

できたこと

項目 | 結果
読み取れたゲーム | 18本（約36MB）
正しさの確認 | 全部について、世界共通の照合表と完全に一致
最難関のカセット | 2本とも成功（マリオRPG／カービィSDX）
かかる時間 | 1本あたり約2〜3分
買い足した部品 | ゼロ

「正しさの確認」が大事なところです。読み取ったつもりでも間違っているかもしれない。そこで、 世界中の人が作った照合表と突き合わせて、1個の数字も違わないことを確かめています。ゲームソ フトとして実際に起動することも確認しました。

できなかったこと

最難関カセットのセーブデータは取り出せませんでした。しかも理由がきれいに裏返しです。

やり方 | ゲームの中身 | セーブデータ
見張り番を眠らせる | 読める | 読めない
見張り番を起こす | 読めない | 読める

両立しません。セーブデータは見張り番が管理しているので、起こさないと手が届きません。ところ が起こすと、今度はゲームの中身が読めなくなる。

セーブデータ自体は、実際に取り出せるところまで来ています。ただ数字がわずかに読み違っていて

、ゲームに読ませると「壊れている」と判断されてしまいます。ここは今後の課題です。

10

## 7. この経験から言えること

うまくいかないときは、まず自分の思い込みを疑う

25日のうち、実際に手を動かしていた時間より、間違った思い込みを追いかけていた時間の方がずっ

と長かったです。

しかもその思い込みは、いつも「もっともらしい説明」の形をしていました。もっともらしいから、 確かめずに次へ進んでしまう。そして確かめていないので、その後の作業が全部むだになる。これを

何度も繰り返しました。

答えの分かっているもので試す

装置が壊れたかと思ったとき、いちばん早い確認方法は「正しく読めると分かっているカセットを1

枚入れてみる」ことでした。2分で終わります。

実際、これで「装置は無実だ」と30分で確定した場面がありました。逆に、これをやらずに重い調査

を始めて、一晩をむだにした場面もありました。

先人に学ぶことと、鵜呑みにすることは違う

今回、世界的に有名な先行例を徹底的に参考にしました。その姿勢自体は正しかったと思います。見 張り番の仕組みを解読できたのも、公開されている資料のおかげです。

ただその資料には「あちらの設計だから必要」な条件も混ざっていました。そこを区別せずに丸ごと

持ち込んだために、20日近くを費やしました。

そして最後に効いたのは、自分たちで見つけたことでした。

別のカセットで苦労して得た「電気の合図を送らなければ、特別な部品はおとなしくしている」とい う発見。そして部品を買えなかったから3台に分けた、という構成。答えは、最初から手元にありま した。

── 25日間の記録より

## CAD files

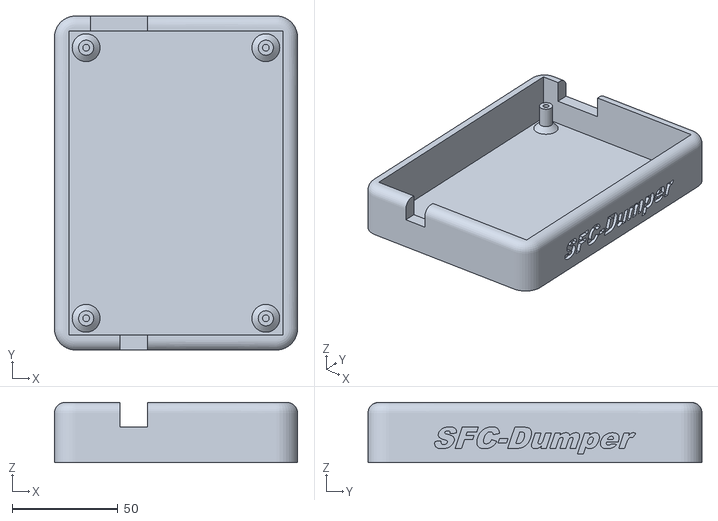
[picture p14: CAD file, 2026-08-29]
hardware/shell/shell_dumper.stl
115.0 x 158.0 x 28.4

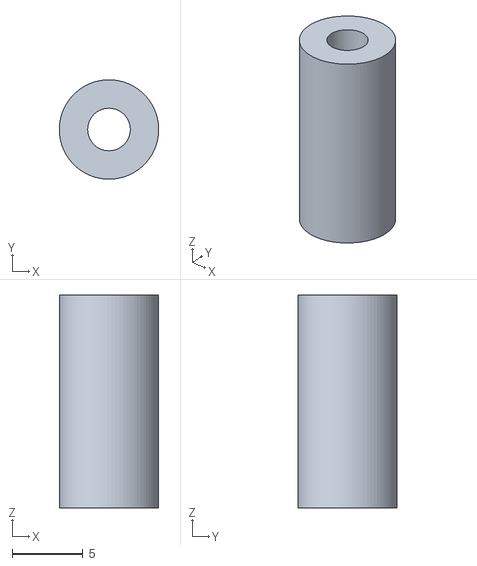
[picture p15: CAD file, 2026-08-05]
支柱.stl
7.00 x 6.99 x 15.0

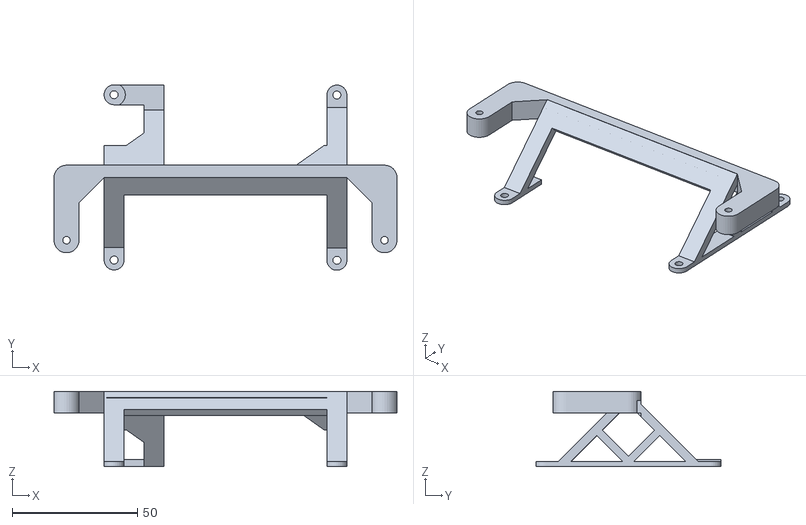
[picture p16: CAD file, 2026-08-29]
hardware/shell/SFC.stl
137.0 x 74.1 x 30.0

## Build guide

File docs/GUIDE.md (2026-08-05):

# 製作・使用ガイド

このダンパーを自分でも作ってみたい人向けの手順書です。
**AIエージェント（Claude Code など）がなくても最後まで到達できるように**、
実際に踏んだ手順と落とし穴をそのまま書いています。

---

## 0. 最初に読んでほしいこと

正直に書きます。**このプロジェクトは「安く手軽にROMを吸い出す」用途には向きません。**

- 62pinカードエッジコネクタの実装が物理的にかなり厳しい（後述）
- 完成後も読み出しが一発で決まらず、検証と再読み出しの仕組みが要る
- 1カートの吸い出しに30分〜数時間かかる

目的が「手持ちの部品だけで動くものを作る」「仕組みを理解する」ならとても面白い題材です。
実用性が目的なら、[Sanni's Open Source Cart Reader](https://github.com/sanni/cartreader) か
市販品を強くおすすめします。

---

## 1. 用意するもの

| 品目 | 数 | 備考 |
|---|---|---|
| Arduino Nano（互換品可） | 3 | クローン品は書き込み時に Old Bootloader 指定が必要なことが多い |
| SFC 62pin カードエッジコネクタ | 1 | ジャンクのスーパーファミコン本体から取り外すのが安上がり |
| ユニバーサル基板 | 1 | 2.54mmピッチ。コネクタとの寸法差は後述の力技で吸収する |
| 配線材 | — | Nano↔カートリッジはUEW（ポリウレタン銅線）が取り回しやすい。他はAWG22程度 |
| 積層セラミックコンデンサ 0.1µF | 数個 | 各Nanoとカートの電源ピン直近に。**あった方がよい** |
| 電解コンデンサ 10〜47µF | 1 | 電源引き込み部に |
| SH1106 or SSD1306 OLED (I2C) | 0〜1 | 進捗表示用。無くても動く |
| 3Dプリント部品 `支柱.stl` | 4 | 基板の底面を机から浮かせる脚。裏面配線を潰さないために必要 |

PC側は Python 3 と `pyserial` だけです。

```bash
pip install pyserial
```

---

## 2. コネクタの取り付け（最大の難所）

### 寸法が合わない

SFCのカードエッジコネクタは**ピッチ2.50mm**で、ユニバーサル基板の2.54mmと合いません。
さらに**列間隔とキー溝の位置も非標準**です。31ピン分でおよそ1.2mmずれます。

実際にやった対処:

1. **キー溝（切り欠き）を超音波カッターで切断する。** 誤挿入防止のためだけの構造なので、
   電気的には切っても問題ありません
2. 上からかぶせる金属シールドで位置決めして押し込む
3. 結束バンドで固定する

### 切った後に必ず確認すること

- **隣接ピン間が短絡していないか。** 切りくずの金属粉が端子間に挟まると、
  1ピンずつの導通チェックでは気づけません。**隣り合うピン同士**に抵抗計を当てて
  無限大（非導通）を確認してください
- **金属シールドが信号ピンに触れていないか。** シールドがGNDに落ちるのは構いませんが、
  信号ピンに触れるとその線がGNDに固定されます
- 挿抜を数回繰り返して、毎回同じ導通結果が出るか（接触の再現性）

### 3Dプリント部品

`支柱.stl` を**4本印刷**し、基板の四隅に取り付けて底面を机から浮かせてください。
裏面は配線がびっしり出ているので、直置きすると断線やショートの原因になります。

---

## 3. 配線

62pinのうち、実際に配線が必要なのは以下だけです。GND/VCCは重複ピンが多いので全部つなぐ必要はありません。

### カートリッジ側ピン番号順

| カートピン | 信号 | 接続先 |
|---|---|---|
| 5, 36 | GND | 共通GNDレール（両方つなぐのが望ましい） |
| 27, 58 | +5V | 共通+5Vレール |
| 6〜17 | A11〜A0 | Nano-1 D13〜D2（番号が逆順なので注意） |
| 37〜40 | A12〜A15 | Nano-1 A0〜A3 |
| 41〜48 | A16〜A23 | Nano-3 D2〜D9 |
| 19〜22 | D0〜D3 | Nano-2 A0〜A3 |
| 50〜53 | D4〜D7 | Nano-2 A4, A5, D8, D9 |
| 23 | /RD | Nano-2 D2 |
| 49 | /ROMSEL | Nano-2 D3 |
| 54 | /WR | **+5Vへ直結**（読み出し専用のため） |
| 26 | /RESET | **+5Vへ直結** |

未接続でよいピン: 1(SYSCLK), 2/33(拡張), 3/4/28〜30/34/59〜61(周辺アドレスバス・/PRD),
18(/IRQ), 24/25/55/56(CIC), 31/62(オーディオ), 32/35(WRAM制御), 57(PHI2)

**CICロックアウトチップは一切関係ありません。** ROMを直接バス読みするだけなので認証は絡みません。

### Nano間

| 信号 | 接続 |
|---|---|
| ADDR_RESET | Nano-2 D10 → Nano-1 A5 |
| ADDR_STROBE | Nano-2 D4 → Nano-1 A4 |
| BANK_RESET | Nano-2 D5 → Nano-3 D10 |
| BANK_STROBE | Nano-2 D6 → Nano-3 D11 |
| GND | 3台すべて共通に |

OLEDを付ける場合は Nano-2 の D11(SDA) / D12(SCL) へ。
ハードウェアI2Cピン(A4/A5)はカートのデータバスで埋まっているので、ソフトウェアI2Cを使います。

### 電源について

3台のNano + OLED + カートで実測おおむね100〜150mAです。USBケーブル1本のバスパワーで
動きますが、**長時間の連続動作では電圧降下が起きて読み出しが化けます**（後述）。
DCジャック＋降圧モジュールで外部給電できるようにしておくと安心です。

---

## 4. ファームウェアの書き込み

3台それぞれに対応するスケッチを書き込みます。

| ボード | スケッチ |
|---|---|
| Nano-1 | `nano1_addr_low/` |
| Nano-2 | `nano2_master/` |
| Nano-3 | `nano3_bank/` |

Arduino IDE でも `arduino-cli` でも構いません。CLIなら:

```bash
arduino-cli compile --fqbn arduino:avr:nano:cpu=atmega328old nano1_addr_low
arduino-cli upload -p COM3 --fqbn arduino:avr:nano:cpu=atmega328old nano1_addr_low
```

### よくあるエラー

```
avrdude: stk500_recv(): programmer is not responding
```

クローンNanoでは **`cpu=atmega328old`（Old Bootloader）** を指定しないと書き込めません。
Arduino IDE の場合は「ツール → プロセッサ → ATmega328P (Old Bootloader)」です。

それでも失敗する場合は、USBケーブルを一度抜き差ししてください。実際これで直ったことが何度もあります。

---

## 5. 吸い出し

### GUIを使う場合（推奨）

```bash
python gui/sfc_dumper_gui.py
```

1. シリアルポートを選ぶ
2. 「カートを判定」でROMサイズとマッピング(LoROM/HiROM)を自動認識
   - タイトル名でデータベース検索して正確なバイト数を引くこともできます
3. `nano2_master.ino` の設定を判定結果に合わせて書き込み直す
4. 「ダンプ開始」

### CLIを使う場合（確実）

**バンク単位方式を使ってください。** 長時間連続で読むと化けるためです。

```bash
python host/dump_by_bank.py --port COM3 --banks 32 --mapping hirom --out MyGame.sfc
```

1バンク（64KB）ごとにNanoをリセットして読み直し、**2回読んで完全一致するまで繰り返します**。
確定したバンクは `MyGame.sfc.banks/` にキャッシュされるので、中断しても続きから再開できます。

---

## 6. 検証（ここが一番大事）

**ヘッダのチェックサム欄だけを見て「読めた」と判断しないでください。**

内部ヘッダにはチェックサムとその補数が入っており、この2つのXORが `0xFFFF` になるかを
見るチェックがあります。しかしこれは**ヘッダの4バイトが正しく読めているかを見ているだけ**で、
ROM本体が壊れていても通ってしまいます。実際これで「成功した」と誤判定しました。

正しい検証は**ROM全体のバイト総和**です。

```python
# HiROMなら 0xFFC0、LoROMなら 0x7FC0 がヘッダ位置
off = 0xFFC0
checksum = rom[off+30] | (rom[off+31] << 8)   # ヘッダが主張する値
computed = sum(rom) & 0xFFFF                  # 実際に計算した値
print(computed == checksum)
```

さらに確実なのは、エミュレータに読ませることです。**Snes9x / RetroArch の Snes9x コアは
ログに `Checksum OK` / `Invalid Checksum` を出力します。**

```bash
retroarch -L cores/snes9x_libretro.dll MyGame.sfc -v --log-file=log.txt
```

No-Intro のCRC32と照合するのも有効です。RetroArch同梱の
`database/rdb/Nintendo - Super Nintendo Entertainment System.rdb` にCRCが入っており、
本リポジトリの `gui/rdb.py` で読めます（ネットワーク不要）。

---

## 7. トラブルシューティング

### 全部 0x00 になる

カートが挿さっていない、GNDが共通化されていない、`/RESET` が+5Vに繋がっていない、
`/RD` や `/ROMSEL` の配線間違い、のいずれかです。まずカートが挿さっているか確認を（実話）。

### 同じ値が2回ずつ並ぶ

アドレスの最下位ビット(A0)が固定されています。カートpin17 ↔ Nano-1 D2 の配線を確認してください。

### 32KB周期で内容が繰り返す

**これは故障ではありません。** LoROMではバンク内の上位32KBと下位32KBが同じ内容に
ミラーされます（A15がROM選択に関与しないため）。ダンプ後に前半32KBだけ抽出してください。
HiROMなら64KBフルに使うのでミラーは出ません。

### 毎回違う位置で少しずつ化ける

長時間の連続読み出しが原因の可能性が高いです。**バンク単位方式**に切り替えてください。
1バンクだけ単独で読む分には、実測で完全に再現します（2回読んで差分0バイト）。

原因は数分間の連続動作による電圧降下と見ています（USBポートのポリスイッチ発熱が有力）。
外部給電にできるなら試す価値があります。

### タイミングを長くしても直らない

読み出しの待ち時間は現行の100usで既に十分です。実測:

| 設定 | 同じバンクを2回読んだ差分 |
|---|---|
| RD=20us / ADDR=20us | 2 バイト |
| RD=100us / ADDR=100us | **0 バイト** |
| RD=400us / ADDR=400us | **0 バイト** |
| RD=1000us / ADDR=1000us | **0 バイト** |

待ちを伸ばしても改善しないので、タイミング以外を疑ってください。

### 読めないカートがある

Super FX / SA-1 / DSP-1 / S-DD1 / SPC7110 / CX4 などの**コプロセッサ搭載カートは
この設計では読めません**。ROMがコプロチップの内部バスにぶら下がっており、
カートのエッジコネクタから直接見えないためです。

該当タイトル例: スターフォックス、ヨッシーアイランド、スーパーマリオRPG、
星のカービィ スーパーデラックス、スーパーマリオカート、スターオーシャン など

---

## 8. 所要時間の目安

| 工程 | 時間 |
|---|---|
| コネクタ取り外し・加工 | 1〜2時間 |
| 配線（アドレス24＋データ8＋制御） | 3〜5時間 |
| 導通チェック | 1時間 |
| ファーム書き込み・動作確認 | 30分 |
| 1カートの吸い出し（バンク単位方式・2MB） | 30分程度 |

---

## 9. 法的な注意

自分が正規に所有するカートリッジのバックアップを想定しています。
吸い出したROMデータの配布は著作権侵害にあたります。本リポジトリにもROMは含めていません。

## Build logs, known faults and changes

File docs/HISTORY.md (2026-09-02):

# 開発史

このダンパーが動くようになるまでの記録です。**うまくいったことより、間違えたことを重点的に**
書いています。同じ地雷を踏む人を減らすためと、「なぜこの設計なのか」を残すためです。

診断を誤った箇所には、何を根拠に誤り、何で気づいたかを明記しています。

---

## 第1章 構成を決める

出発点は「ESP32-S3の開発ボードとジャンクのスーパーファミコンがある。これだけで吸い出せないか」
でした。

SFCカートを読むには最低でも **アドレス24本 + データ8本 + 制御2本 ≒ 34本** のI/Oが要ります。
検討した候補:

| 案 | 却下/採用の理由 |
|---|---|
| ESP32-S3 単体 | **5Vトレラントではない。** カートの5V出力を直結すると壊れる。レベル変換ICが必須だが手持ちなし |
| Arduino Uno 単体 | 5Vネイティブで電圧問題なし。しかし使えるI/Oが18本しかなく、34本には遠く及ばない |
| Arduino Mega 2560 | I/O 54本で直結でき最も素直（Sanni's Cart Readerがこの構成）。**ただし買い足しが必要** |
| Raspberry Pi Zero 2 + Nano | 3.3V系のためデータバス8本＋ACKに分圧抵抗が18本ほど必要。「手持ちだけで完結」の利点が消える |
| **Nano × 3** | **採用。** 全ボードが5Vネイティブで電圧問題が原理的に発生しない。追加部品ゼロ |

制作者の縛りが「追加で一つもパーツを購入しない」だったため、最後の案に決まりました。

途中でESP32-S3を「バスに触らない受け皿（UART受信＋WiFi転送）」として使う案も検討しました。
バスマスタとして使うのが問題だったのであって、受信専任なら電圧問題は起きないという整理です。
結局はPC直結で足りたため採用しませんでした。

---

## 第2章 コネクタという物理的な壁

### 62ピンは表31＋裏31

「62ピン」を表裏で124本と誤解しがちですが、カードエッジは基板の両面に端子が並んでいて、
それをまとめて挟むタイプです。合計62本で正しい。

さらに、62本のうち相当数はGND/VCCの重複です。実際に配線が必要なユニーク信号は
アドレス24＋データ8＋制御2＋電源/GND数本で足ります。

### ピッチは2.54mmではなく2.50mm

制作者から「ユニバーサル基板に微妙に合わない」という報告があり、当初は
「2.0mmピッチだから31ピンで大きくずれる」と回答しました。**これは誤りでした。**
「それなら20ピンで1cmずれる、それでは刺さるはずがない」と指摘され、調べ直したところ:

- 実際のピッチは **2.50mm**（2.54mmとの差は0.04mm、31ピンでも累積1.2mm程度）
- **列間隔とキー溝の位置も非標準**

つまり主犯はピッチの累積誤差ではなく、列間隔とキー溝の変則さでした。
制作者はキー溝を超音波カッターで切断し、金属シールドで位置決めして押し込むという
力技で解決しています。

**教訓: 数字が合わないと言われたら、自分の記憶ではなく資料を当たる。**

---

## 第3章 最初の設計と、そこに埋めた欠陥

3台の役割分担:

| ボード | 役割 |
|---|---|
| Nano-1 | アドレス A0-A15。STROBEパルスで16bitカウンタを+1 |
| Nano-2 | `/RD`・`/ROMSEL`制御、D0-D7読み取り、USBでPCへ送信、OLED表示 |
| Nano-3 | アドレス A16-A23（バンク）。**Nano-2から DATA/CLK/LATCH の3線シリアルで受信** |

Nano-3だけ方式が違います。これが後で牙を剥きます。

---

## 第4章 動き出すまでに踏んだ地雷

### 全部 0x00 になる

原因は**カートが挿さっていなかった**。制作者の申告で判明。
以降、トラブルシューティングの筆頭に「まずカートが挿さっているか」を書いています。

### 同じ値が2回ずつ並ぶ

アドレス最下位ビットが効いていない典型的な症状に見えました。配線を疑いましたが導通は正常。
実際は**待ち時間不足**で、`/RD`アサート後の待ちを1µs→100µsにして解消。

### 32KB周期で内容が繰り返す

「A15の配線不良」と判断して制作者にハンダ付けをやり直してもらいましたが、**変化なし**。
これは故障ではなく、**LoROMではバンク内の上位/下位32KBが同じ内容にミラーされる**という
正常な電気的挙動でした。無駄な作業をさせてしまった箇所です。

### 実行のたびにデータ位置がずれる

Nano-1のアドレスカウンタが起動時に0から始まっていませんでした。
Nano-2 D10 → Nano-1 A5 に **ADDR_RESET線を1本追加**して解決。

### 1バイトずれる

ストローブを1回余計に打って補正しようとしたら**2バイトずれた**（対処が逆方向）。
本当の原因は**PC側スクリプトがシリアル受信バッファをクリアしていなかった**ことで、
前回セッションの残留バイトを読んでいました。`reset_input_buffer()` と
「要求サイズちょうどだけ読む」の2点で解決。

**教訓: ハードを疑う前に、自分のホスト側コードを疑う。**

---

## 第5章 最大の落とし穴 — ヘッダのチェックサムは何も保証しない

ぷよぷよの1MBダンプが取れ、内部ヘッダの検証も通ったので「成功」と報告しました。

**これは誤判定でした。**

SNESの内部ヘッダには「チェックサム」と「その補数」が入っており、
2つのXORが `0xFFFF` になるかを見るチェックがあります。しかしこれは
**ヘッダの4バイトが正しく読めたことしか保証しません**。ROM本体が壊れていても通ります。

発覚したのはエミュレータに読ませたときで、Snes9xコアが `Invalid Checksum` を出力しました。
正しい検証は **ROM全体のバイト総和** です。

```python
checksum = rom[off+30] | (rom[off+31] << 8)   # ヘッダが主張する値
computed = sum(rom) & 0xFFFF                  # 実際に計算した値
```

以降、この総和とNo-IntroのCRC32の両方で検証しています。

---

## 第6章 バンク転送の設計ミス

本体が壊れている原因を追うため、一晩かけて20回以上ダンプし、バイト単位の多数決で
マージしました。結果、**特定のバンクだけが毎回丸ごと化ける**ことが判明。

原因は Nano-2 ⇔ Nano-3 の3線シリアル転送でした。2台は**別々の水晶発振子で非同期に動く**ため、
クロック同期でビットを取りこぼします。パルス幅を5µs→300µsに広げても完全には安定しませんでした。

**解決: Nano-1と同じ「STROBEでカウントアップ」方式に統一。**
バンクは常に0から+1ずつ進むだけなので、シフトレジスタである必要がそもそもなかった。
クロック同期という概念自体が消え、原理的に安定します。

配線は変更不要でした。旧DATA線をRESET、旧CLK線をSTROBEとして読み替え、旧LATCH線は放置。
誤り率が数十万バイトから数千バイトへ、**約100分の1**に激減しました。

その後27サンプルの多数決マージでぷよぷよのチェックサムが一致し、**1本目が完成**しました。

---

## 第7章 スーパーマリオコレクション — 24回読んでも合わない

2本目で最も長く詰まりました。

### マッピングの誤判定

バンク0の前半32KBと後半32KBを比較し、「一致しない＝ミラーなし＝**HiROM**」と判定しました。

**これが誤りでした。** 前半は単に**全部0x00で死んでいた**だけで、それを「別内容」と読み違えていました。

さらに悪いことに、ヘッダの `map_mode` バイトは `0x20`（＝LoROM）と**最初から正しく読めていた**のに、
自分の推論を優先して「HiROMなのに0x20とは妙だ、ビット落ちか」と疑ってしまいました。

### この誤判定が引き起こしたこと

LoROMではROMは各バンクの `$8000-$FFFF` にしか現れません。したがって:

- 2MBのLoROMには**64バンク必要**（32KB×64）なのに、32バンクしか読んでいなかった
- しかも**データのない下位32KBの方を採用**していた

出来上がったのは「実データ1MB＋ゼロ1MB」。**24回ダンプしようが多数決を取ろうが、
合うわけがありませんでした。**

ぷよぷよは上下がミラーだったため下位半分でも正解になり、その成功体験に引きずられました。

### 途中で立てて否定された仮説

| 仮説 | 検証結果 |
|---|---|
| 誤りは「ビット落ち」の一方向のみ。だからORマージが正しい | **誤り。** 基準に多数決値を使ったため、多数決自体が壊れた位置で正しいサンプルが「ビット増加」に見えていた。7サンプル時点で期待値まで682だったのも偶然 |
| OLEDの表示更新が5Vレールを揺らしている | 読み出し中にOLEDへ一切触れなくても誤り率は変わらず。**否定** |
| バンク切替直後の電源整定不足 | OLED更新後に `delay(250)` を入れたら誤りが約6,500→19,000バイトに**悪化**。**否定** |

### 突破口

8KB刻みでゼロ率を出したのが決定打でした。

```
  窓        A15 A14 A13   bank0   bank1   bank2   bank3
  0x0000     0   0   0    100.0%  100.0%  100.0%  100.0%
  0x2000     0   0   1    100.0%  100.0%  100.0%  100.0%
  0x4000     0   1   0    100.0%  100.0%  100.0%  100.0%
  0x6000     0   1   1    100.0%  100.0%  100.0%  100.0%
  0x8000     1   0   0     16.1%   35.4%   73.9%    5.6%
  0xa000     1   0   1      9.0%   39.7%   31.2%    4.2%
  0xc000     1   1   0      4.6%   45.5%   10.8%    3.1%
  0xe000     1   1   1      0.7%   40.5%    3.2%    2.8%
```

**A15=0の領域が丸ごと死んでいる＝LoROM。** ヘッダの申告通りでした。

上位32KBを64バンク分集め直したところ、**一発で通りました**。統計的なマージも再試行も不要。

```
checksum = 0x4bca  計算値 = 0x4bca
CRC32    = 232bb5b8 → No-Intro "Super Mario Collection (Japan)" と完全一致
```

**教訓: ROMが自己申告しているものは、まず信じる。自分の推論より優先する。**

---

## 第8章 高速化 — 「1回おきの取りこぼし」

当初331µs/バイト（2MBで約12分）でした。内訳はほぼ全部が待ち時間で、
ROMの実力（アクセスタイム120〜200ns）から見て500倍以上過剰です。

### 一度目の挑戦と失敗

`digitalWrite`/`digitalRead`（1回約4µs）をポートレジスタ直叩きに置き換え、
ボーレートも1Mbpsへ。速度は12倍出ましたが、**データが壊れました**。

ここでまた誤診を重ねました。

| 仮説 | 実際 |
|---|---|
| ポート直叩きで同時スイッチングノイズが増えた | アドレスは毎回+1なので遷移するビットは平均2本程度。この説明は苦しい |
| 長時間の連続動作による電圧降下 | 外部電源でも変化なし |
| デカップリング不足 | 制作者から「既に最短距離で実装済み、33µF搭載済み、GNDも両方引いている」と回答。**打つ手は尽きていた** |

### 決定打

同じバンクを10回読み、**毎回きっかり30966バイトの相違**という結果が出ました。
ノイズなら数値がばらつくはずです。完全に決定的でした。

そこでアドレスの進み方を検算したところ:

```
そのまま      : 5.5%
2倍速         : 66.7%
半分(重複読み): 32768/32768 (100.0%)  ★
```

**`出力[i] == 正解[i÷2]` が100%一致。同じアドレスを2回ずつ読んでいました。**

Nano-1がストローブを**きっかり1回おきに取りこぼしていた**のです。
ポーリングには「ループを一周する間に来たパルスを取りこぼす」という原理的な穴があり、
Nano-1の処理時間がNano-2の1サイクルより長くなると**必ず半分落ちます**。

パルス幅を60µs、100µsと広げていたのは、この穴を塞がずに誤魔化していただけでした。
電源もデカップリングも無関係で、**純粋なソフトウェアの取りこぼし**でした。

### 解決 — ポーリングから割り込みへ

Nano-1/Nano-3を**ピン変化割り込み（PCINT）**に変更。
エッジをハードウェアがラッチするので、ISRが動く前にパルスが終わっていても取りこぼしません。
穴そのものが消えます。

その後、待ち時間を5段階で振り、**各条件で2回読んで両方とも正解と完全一致した場合のみ合格**
という基準で掃引しました（単発の一致を信じて痛い目を見た教訓の反映。実際PULSE=60は
単発では完全一致したのに、繰り返すと数千バイト化けた）。

```
RD=20 ADDR=20 PULSE= 5 -> 合格 (79us/byte)
RD=10 ADDR=10 PULSE= 3 -> 合格 (57us/byte)
RD= 5 ADDR= 5 PULSE= 3 -> 合格 (47us/byte)   ← 採用
RD= 3 ADDR= 3 PULSE= 2 -> 合格 (42us/byte)
RD= 2 ADDR= 2 PULSE= 2 -> 合格 (40us/byte)
```

最速値ではなく1段手前を採用したのは、カートの接触状態のばらつきに対する余裕のためです。

**331µs → 47µs/バイト（7倍）。2MBが約12分から約3分になりました。**

---

## 第9章 ハマりどころ — 実際に踏んだもの

READMEから移した。**同じ地雷を踏む人を減らすため**の記録なので、
うまくいった手順ではなく、誤診とその気づき方を中心に書いてある。

### コネクタ

- SFCのカードエッジは **62pin = 表31 + 裏31**。表裏で124本ではない
- ピッチは通称2.54mmではなく **実測2.50mm**。さらに列間隔とキー溝の位置も非標準なので、
  2.54mmグリッドのユニバーサル基板とは完全には整合しない
- 62本のうち相当数はGND/VCCの重複。実際に配線が必要なユニーク信号は
  アドレス24 + データ8 + 制御2 + 電源/GND数本で足りる

### メモリマップ

- **LoROMはバンク内で上位/下位32KBが同一内容にミラーされる**（A15がROM選択に関与しないため）。
  これは故障ではなく正常な電気的挙動。ダンプ後に前半32KBだけ抽出する
- HiROMは1バンク64KBをフルに使う（ミラーなし）

### タイミング

- Nano間の3線シフト転送（DATA/CLK/LATCH）は、2台が**別々の水晶発振子で非同期に動く**ため
  クロック同期でビットを取りこぼす。パルス幅を5us→300usに広げても完全には安定しなかった
- 最終的に **Nano-1と同じ「STROBEでカウントアップ」方式に統一**して解決。
  クロック同期という概念自体が消えるため原理的に安定する（誤り率が数十万バイト→数千バイトに激減）
- ROMのアクセスタイム自体は120〜200ns程度。当初は`/RD`後の待ちを100usも取っていたが、
  下記の割り込み化のあとに実測で詰めて5usまで短縮した（1バイト331us→47us）
- **必要なマージンはカートの個体差でかなり違う。** Super Mario Collection と夜光虫は
  5us（最速）で一発で通ったが、Street Fighter II は5usだと2回連続一致すら得られず、
  100usまで上げてようやく安定した。全カート一律で遅くすると要らないカートの速度を捨て、
  一律で速くすると要るカートで延々と読み直すことになる
- そこで `host/bankio.py` に**段階的エスカレーション**を実装した。最速（5us）から始め、
  規定回数一致しなければ次の段階へ落とす（5→20→50→100→300us）。さらに一度落とした後も
  数バンクごとに最速側を試し直し、通れば速度を取り戻す（`AdaptiveTiming`）。
  タイミング値は起動のたびにPCからファームへ送るので、書き込み直しは不要
- 「2回読んで一致すれば正しい」という検証には落とし穴がある。カートが外れて全バイト0x00に
  なった場合、その出力は**自分自身と必ず一致する**ため素通りしてしまう。
  全バイトが同一値のデータは異常として弾いている（`_is_degenerate`）
- **電源が読み取り品質を支配する。** USBバスパワーで動いてはいたが、消費電流の大きい
  カート（Super FX機など）では読むたび数百バイトが化けた。安定化電源から5Vバスへ直結したら
  連続5回読んで1バイトも違わなくなった。**タイミングをいくら詰めても直らない誤りに出会ったら、
  まず電源を疑うこと。**段階を下げたのに悪化するなら、ほぼ電源で確定（コプロセッサ搭載カートの
  節に実測値あり）

#### ストローブの取りこぼし — 最も長く誤診した問題

高速化しようとしてポート直叩き化したところ、データが壊れました。当初は電源やデカップリング、
連続動作による電圧降下を疑いましたが、**すべて外れ**でした。

決定打は、同じバンクを10回読んで**毎回きっかり30,966バイトの相違**が出たことです。
ノイズなら数値がばらつきます。完全に決定的でした。そこでずれ方を総当たりで検算すると:

| 仮説 | 一致率 |
|---|---|
| そのまま `出力[i]==正解[i]` | 5.5% |
| 2倍速 `出力[i]==正解[2i]` | 66.7% |
| **半分 `出力[i]==正解[i÷2]`** | **100.0%** |

**同じアドレスを2回ずつ読んでいた**＝Nano-1がストローブをきっかり1回おきに取りこぼしていた。

ポーリングには「ループを一周する間に来たパルスを取りこぼす」という原理的な穴があり、
Nano-1の処理時間がNano-2の1サイクルより長くなると**必ず半分落ちます**。
パルス幅を60usや100usに広げていたのは、穴を塞がずに誤魔化していただけでした。

**解決: Nano-1/Nano-3をピン変化割り込み(PCINT)に変更。**
エッジをハードウェアがラッチするので、ISRが動く前にパルスが終わっていても取りこぼしません。

その後、待ち時間を掃引して詰めました。**各条件で2回読んで両方とも正解と完全一致した場合のみ合格**
という基準です（単発の一致は当てにならない。実際PULSE=60usは単発では完全一致したのに、
繰り返すと数千バイト化けた）。

| 設定 | 結果 |
|---|---|
| RD=20 ADDR=20 PULSE=5 | 合格 (79us/byte) |
| RD=10 ADDR=10 PULSE=3 | 合格 (57us/byte) |
| **RD=5 ADDR=5 PULSE=3** | **合格 (47us/byte) ← 採用** |
| RD=3 ADDR=3 PULSE=2 | 合格 (42us/byte) |
| RD=2 ADDR=2 PULSE=2 | 合格 (40us/byte) |

最速値ではなく1段手前を採用したのは、カートの接触状態のばらつきに対する余裕のためです。
**331us → 47us/byte（7倍）、2MBが約12分から約3分になりました。**

なお、この真因が判明する前は「複数回ダンプして多数決マージ」で押し切っていました。
Super Puyo Puyo (LoROM 1MB) は27サンプルかけて通しましたが、
Super Mario Collection (LoROM 2MB) は24サンプルでも収束しませんでした。
そちらの真因は別で、**LoROMなのにHiROMと誤判定してデータのない下位32KBを集めていた**ためです。
詳細は [開発史](docs/HISTORY.md) に書いてあります。

#### バンク単位で読む方式

[host/dump_by_bank.py](host/dump_by_bank.py) は1バンクごとにNanoをリセットして読み直し、
**2回読んで完全一致するまで繰り返します**。確定したバンクはキャッシュされるので、
中断しても続きから再開できます。統計的なマージが不要になるため、これを推奨します。

#### コプロセッサ搭載カート

**一括りに「読めない」と書いていたが誤りだったので訂正した。** コプロセッサには2種類ある。

**Super FX（スターフォックス、ヨッシーアイランド）は読める。** 当初「バスを支配するので
読めない」と書いたが、これも誤りだった。2本ともチェックサム・No-IntroのCRC32ともに一致
(Star Fox `41a60b3f` / Yoshi's Island `343e0dfb`)。詳細は下記。

**SA-1（スーパーマリオRPG、星のカービィ スーパーデラックス）も読める。**
3個体・2タイトルでNo-IntroのCRC32が一致し、Snes9xも `Checksum OK` を出す。
必要なのは **CIC認証** と **カートにクロックを与えないこと**、そして
**1回の接続で64バンクを読み切ること**。詳細は
[SA-1はクロックを与えず、CIC認証を通して読む](#sa-1はクロックを与えずcic認証を通して読む)。

    Super Mario RPG (Japan)                      5527071e
    Hoshi no Kirby Super Deluxe (Japan)          151bd470
    Hoshi no Kirby Super Deluxe (Japan) (Rev 2)  1f35f230

> **2026-08-29 訂正:** 以前ここに「CIC認証もマスタークロックも要らなかった」と書いた。
> **CIC認証について、これは誤りだった。** 詳細は下記の訂正節に書く。
> マスタークロックが不要である点は変わらない。

##### Super FX は「特殊チップだから読めない」のではなかった

スターフォックスは長らく読めなかった。同じバンクを読むたび数百バイトが化け、2回一致が
永久に成立しない。多数決ダンプ(dump_voting.py)まで作って10サンプル積んだが、1MB中
38,937バイトが決着せずCRCも合わなかった。

**原因はGSUではなく電源だった。** 安定化電源から5Vバスへ直結したところ、同じ設定で
連続5回読んで**1バイトも違わなくなった**。その状態で普通にLoROM 32バンクを読んだら、
チェックサムもNo-IntroのCRC32も一発で一致した。

誤診に至った理由は、症状がいかにも「動作中のバスマスタと衝突している」ように見えたこと。
特に**遅くするほど悪化する**という挙動が決定的な誤解を招いた（5us:89バイト相違 →
300us:9828バイト相違）。「読み出しに時間をかけるほどGSUが割り込む機会が増える」と解釈したが、
実際は**遅い設定ほど1バンクの読み出しが長引き、弱い電源を長時間虐めていた**だけだった。

電源改善後に同じ比較をすると、この現象は消える:

| 段階 | 所要 | 2回読みの相違（改善前 → 改善後） |
|---|---|---|
| 高速 (5us) | 15.0s | 89/75 → **0** |
| やや低速 (20us) | 19.2s | 338/611 → **0** |
| 低速 (50us) | 27.8s | 5259/2758 → **0** |
| 安全 (100us) | 42.3s | 1969/1340 → **0** |
| 最安全 (300us) | 99.1s | 2524/9828 → **29** |

**教訓: 段階を下げたのに相違が増えるなら、タイミングではなく電源を疑うこと。**
bankio.py のエスカレーション機構は「遅くすれば安全になる」を前提にしているが、
その前提は電源が健全なときにしか成り立たない。電源が弱いと**自動エスカレーションが
自ら傷口を広げる**。

##### ヨッシーアイランド(GSU-2)は接触が原因だった — 症状が同じでも原因は違う

スターフォックスの次にヨッシーアイランド(2MB / GSU-2)を読んだら、**まったく同じ症状**が出た。
読むたび数百〜数千バイトが化け、バンク1で全段階失敗して止まる。電源が犯人だった直後なので
当然そちらを疑ったが、**外れだった**。

| 疑ったもの | 検証結果 |
|---|---|
| 電源不足 | ❌ 安定化電源が4.99Vを維持 |
| 発熱 | ❌ 触っても熱くない |
| アドレス線・データ線の不良 | ❌ どのビットにも偏りなし(各3.4〜6.6%) |
| **カートの接触** | ✅ **挿し直しで0xFFが12分の1、連続3回で相違0** |

決め手は**数分の間に品質が12倍変動したこと**(上位32KBの0xFFが15,306個→1,268個)。
電気的な設計問題ならこんな不連続な揺れ方はしない。接触なら当然。
持ち主いわく「実機で遊んでいた頃から調子の悪いカセット」で、その一言が測定より早く正解に
近かった。

**同じ症状に同じ原因を当てはめると間違える。** 電源・接触・マッパーの三者は、
どれも「読むたび化ける」という同じ顔で現れる。

##### キャッシュは条件を変えたら捨てること

挿し直し後に64バンクすべてリトライなしで読めたのに、チェックサムが **4だけ**合わなかった
(0x7312 / 期待 0x730e)。原因は、**最初の失敗した実行が接触の悪い状態でバンク0を確定させ、
キャッシュに書き込んでいた**こと。以降の実行はそれを再利用し続けていた。

バンク0のキャッシュを消して読み直したら一発で一致した。

中断から再開できるのがキャッシュの利点だが、**悪条件下で確定したバンクも同じように信頼される**
という裏返しがある。**電源・配線・カートの挿し直しなど条件を変えたら、キャッシュを消してから
やり直すこと。** 今回はチェックサムが捕まえたが、検証手段がなければ壊れたROMを保存していた。

##### 接触不良のカートを回数で押し切る

挿し直しで直らないカートが残る。[host/contact_merge.py](host/contact_merge.py) は
そういう相手に、時間を払って票を積む。ここまでに分かっている壊れ方をそのまま設計に写した。

| 実測されている事実 | 設計への反映 |
|---|---|
| 誤りは**数十〜250バイトの連なり**で出る（あるビットが数十ms張り付く） | 外れ値の判定を**256バイトの窓ごと**に行う。壊れた区間だけ票から外し、同じサンプルの正常な区間は数える |
| **数分の間に品質が12倍変動**する（ヨッシーアイランド） | サンプルを**バンクを一周しながら1本ずつ**集める。同じバンクを連続で読むと、その全部が「悪い数分」に入りうる |
| 誤りは**双方向**（ビット落ち一方向説はコミット `d0d1876` で撤回済み） | **ORは使わない**。バイト単位で決着しない場所だけビット単位の多数決に落とす |
| 0xFF一色の読みは安定していて「2回一致」を通す | 全バイト同一のサンプルは票に入れる前に捨てる |
| 悪条件下で確定したキャッシュも同じ重みで信頼される | `--fresh` で退避してから取り直せる。`.banks` の確定済みバンクは既定では票にしない |

`dump_voting.py`（Super FX用）との違いは、外れ値の判定単位が「サンプル1本まるごと」か
「窓ごと」かにある。1本まるごと捨てる方式だと、途中で浮いただけのサンプルの
**正常な数万バイトまで一緒に捨てる**。接触不良ではそれが頻繁に起きる。

窓ごとの判定は、仮の多数決値を基準にしている以上**循環している**。多数決が丸ごと
間違っている窓では、正しいサンプルの方が外れ値に見える。一方向のビット落ちだと誤断したのは
まさにこの循環が原因だったので、相違の少ない上位3本は必ず残し、判定に「多数派から遠い」
以上の意味は持たせていない。0xFFの密度による除外だけは多数決と独立した指標になる。

決着しなかったバイトは `<出力名>.report.txt` に位置が出る。なお、未決着の候補値を
入れ替えればチェックサムが合う組み合わせは、たいてい**存在してしまう**。それを見つけて
書き戻す `--guess-checksum` も用意してあるが、既定では存在を報告するだけにしてある。
このプロジェクトでチェックサムは「本物かどうか」を決める唯一の材料なので、
自分で合わせにいったらその材料を失う。

##### キャッシュは「どのカートから取ったか」を覚えていない

かまいたちの夜を吸い終わったあと、以前の実行が残していた
`KAMAITACHINOYORU.sfc.banks/` の中身を答え合わせしたら、32,768バイト中**32,191バイトが相違**した。
ずれや化けではない。**中身はスターフォックスだった**（ヘッダのタイトルが `STAR FOX`、
先頭256バイトが `STARFOX.sfc` のオフセット0と完全一致）。

上に「条件を変えたらキャッシュを捨てること」と書いたが、危険はもう一段深い。
**キャッシュが信頼しているのは出力ファイル名だけで、カートの同一性は誰も見ていない。**
カートを差し替えて同じ名前で走らせれば、別のゲームのバンクが黙って混ざる。
チェックサムが捕まえてくれなければ、そのまま保存される。

`contact_merge.py` はキャッシュを再利用するとき、**そのキャッシュが名乗るタイトルを表示し、
開始バンクを1本だけ読んで突き合わせる**。食い違ったらその場で止まる。
1本ぶんの時間で、数時間を無駄にする事故を防げる。

```
既存のサンプル 320 本を再利用します。
  キャッシュのカート: SUPER MARIOWORLD
キャッシュと同じカートかを確認しています…

キャッシュのカートは SUPER MARIOWORLD ですが、今挿さっているのは STAR FOX です。
混ぜると壊れたROMができます。--fresh を付けて取り直すか、--out の名前を変えてください。
```

##### 0xFF率が動くかどうかで「接触」と「タイミング不足」を切り分ける

電源・接触・マッパーが同じ顔で現れることは上に書いた。**タイミングマージン不足**も同じ顔をする。
かまいたちの夜(LoROM 3MB)は連続2回読みで上位32KBが2,271バイト相違し、
0xFFが16.8%もあった。接触不良にしか見えない。

段階を掃引したら答えが出た。

| 段階 | バンク$00 相違 | バンク$28 相違 | 0xFF率 |
|---|---|---|---|
| 高速 (5us) | 3,238 | 1,502 | 0.1675 |
| やや低速 (20us) | 1,028 | 239 | 0.1678 |
| 低速 (50us) | 438 | 51 | 0.1678 |
| 安全 (100us) | 110 | 7 | 0.1677 |
| **最安全 (300us)** | **1** | **0** | 0.1678 |

**判定材料は2つある。**

1. **相違が段階に対して単調に減る** → タイミング。接触なら遅くしても変わらないし、
   Super FXなら逆に悪化する（5us:89バイト → 300us:9828バイト）
2. **0xFF率が動かない** → その0xFFは本物のデータ。接触不良なら跳ね回る
   （ヨッシーアイランドは同じ場所で15,306個→1,268個と12倍動いた）

つまりこのカートの16.8%の0xFFは正常で、**遅く読めば読める**。多数決を何本積むかの問題では
なかった。`contact_merge.py` は追加取得のたびにタイミングを1段上げる（`--no-escalate` で無効化）。
**票で駄目なら微秒を払う**——Super FX用の `dump_voting.py` が最速固定なのとちょうど逆で、
どちらが正しいかは事前に分からないので、掃引して決めるのが確実。

##### 「多数決は完璧、それでも合わない」— サイズの方が嘘だった

ドラゴンクエストI・II を `contact_merge.py` で読んだら、**64バンクすべてが未決着0バイト**
（＝5サンプルが全バイトで一致）なのにチェックサムが合わなかった（0x47b5 / 期待 0x2d8a）。
読みが完全に安定しているのだから、犯人は多数決ではない。

**このカートは12Mbit(1.5MB)で、ヘッダのROMサイズ申告 0x0b は2の累乗に切り上げられた
2MBだった。** 後半4Mbitはアドレス空間に2回現れるので、本体もそう数える。
2MBぶんを素直に足せば当然合わない。

```
1.5MBとして sum(前半1MB) + 2 * sum(後半512KB) = 0x2d8a  → 一致
CRC32 = 98bb6853 → No-Intro の Dragon Quest I & II (Japan) / 1,572,864 bytes と一致
```

`contact_merge.py` の検証はこれを見るようにしてある。全体で合わなければ
「2の累乗」または「2の累乗＋2の累乗」の大きさを順に試し、合った時点でそこまでを実体として
末尾のミラーを切り落とす。DBによるサイズ確認が有効なのと同じ理由（[データベース検索について]
(#データベース検索について)）が、読んだ後の検証側にもそのまま当てはまる。

**「チェックサムが合わない＝読めていない」ではない。** 読みの品質とサイズの解釈は
別々に疑う必要がある。

##### SA-1はクロックを与えず、CIC認証を通して読む

    Super Mario RPG (Japan)                      CRC32 5527071e
    Hoshi no Kirby Super Deluxe (Japan)          CRC32 151bd470
    Hoshi no Kirby Super Deluxe (Japan) (Rev 2)  CRC32 1f35f230

4MBを **95秒** で読み切る。Snes9xも `ROM+RAM+BAT+SA-1` と認識して `Checksum OK` を返す。

**必要な条件:**

| 項目 | 要否 |
|---|---|
| **CIC認証**（本体側Lock役を演じる） | **必要** |
| マスタークロック 21.477MHz（カート1番） | **不要。むしろ有害** |
| システムクロック（カート57番） | **出してはいけない** |
| 1回の接続で全64バンクを読み切る | **必要** |
| リトライ（窓は確率的） | **必要** |
| 接触の良いカート個体 | **必要** |

**クロックを与えてはいけない理由。**
Super FXで到達した「クロックが無いから通せないのではなく、
**クロックが無いから大人しかった**」が、そのままSA-1にも当てはまる。
クロックを与えればSA-1は起きてバス調停を始め、ROMを握ってしまう。
与えなければ眠ったままで、ROMは素通しで読める。
MCKを供給していた時期にSA-1が `0x02` や `0x34` を返していたのは、
起きたSA-1がバスを握っていたからだった。

**CIC認証が要る理由。** カート内蔵のCIC(Key)に対して本体側のLock役を演じ、
ラウンド0の握手を成立させる必要がある。本リポジトリのファームは
`nano3_cicbank`（別リポジトリ）で、電源投入300ms後に自力で認証を実行する。

##### 訂正: 「CIC認証は不要」は交絡した実験による誤りだった

2026-08-28、ここに「CIC認証は不要」と書いた。**誤りである。**

誤った根拠はこうだった。

    ① nano3_cicbank（CIC認証あり）で カービィ成功・再現成功・マリオRPG成功
    ② nano3_bank（CIC認証なし）に書き換えて「CICなしでも5/6で成功」

②を独立した検証だと考えたが、**独立していなかった。**
①でCIC認証を何度も通したあとの状態で②を実行していた。
SA-1のBW-RAMは電池でバックアップされており、状態が電源サイクルを越えて
残る経路が実在する。

**一度も認証していない状態からCICなしで試したのは2026-08-29が初めてで、
結果は 0/16 だった**（カービィ8回・マリオRPG8回、いずれも電源サイクルつき）。
同じ条件でCIC認証を有効にしたところ、**2回目で成功した**（CRC 151bd470）。

順序を変えれば結論が変わる実験を、独立した検証として扱ったのが誤りだった。

##### 2026-08-31 追記: 45連敗の原因は「起動読み」の欠落だった

上の訂正のあと、SA-1は45回連続で失敗し続けた。原因は運ではなかった。

**いきなり64バンクを読みに行くと、SA-1はROMを出さない。**
先に1バンクずつ短い読み出しを何度か行うと、以後すべての窓が開く。

    起こす前  : $C0 は 0xFF 一色（異なる値1種）
    起動読み  : $00 $20 $40 $80 $C0 $E0 を1バンクずつ。**$E0 だけ実データが出る**
    起こした後: $C0/$D0/$E0/$F0 すべて 256種。64/64バンク成立

`dump_sa1.py` の prime（バンク$C0のダミーアクセス1回）だけでは足りない。
**SA-1を吸うなら `host/sa1_wake.py` を使うこと。**

**切り分けの決め手は、正常なLoROMカート（スターフォックス）を挿して $C0 を読んだこと。**
LoROMカートに $C0 は存在しないので 0xFF 一色になる。45回見ていたのと同じ絵だった。
そこで「施錠されている」ではなく「**何もマップされていない**」と読み替えられた。

###### CIC認証はやはり必要（起動読みを固定して再検証）

「CIC必要という結論も交絡ではないか」と疑い、Nano-3を `nano3_bank`（CICなし）に
焼き替えて比較した。**起動読みは両条件で同一。**

| 条件 | 正解 | 内訳 |
|---|---|---|
| CICあり | **4/4** | すべて 151bd470、バイト単位で一致 |
| CICなし | **1/6** | 成功1・**壊れたデータ2**・施錠3 |

CICなしの唯一の成功は、CIC版で最後に成功した11分後だった（残留の疑いが濃い）。

**壊れ方が危険である。** CICなしで「64/64バンクがROMらしい」「ヘッダ
『KIRBY SUPER DELUXE』も読める」のに、正解と 31.6% / 96.7% 違う回があった。
`rom_likeness` は全バンク合格していた。**総和検査とCRC照合を外してはいけない。**

###### 対照実験でわかったこと（2026-09-01、355試行）

クロックはハイインピーダンス固定。判定は起動読み後に $C0 を1バンク読み、
既知の正解の先頭64KBとバイト単位で一致するか。

**起動読みの中身（各20回）**

| 条件 | 成功 | 95%CI |
|---|---|---|
| 起動読みなし | **0/20 (0%)** | 0-16% |
| `[0xC0]` 1回（sanni相当） | 13/20 (65%) | 43-82% |
| `[0xC0]` 6回 | 13/20 (65%) | 43-82% |
| **`[0xE0]` 1回** | **18/20 (90%)** | 70-97% |
| 6バンク全部 | 18/20 (90%) | 70-97% |

**効いているのは回数ではなくバンクの選択。$E0 を1回叩けば足りる。**

**訂正:** 「sanniのダミー読みでは足りない」と書いていたが誤り。**65%通る。**
45連敗は 0.35^45 ≒ 10^-20 なので、あの時期は別の何かが違っていた。何かは不明。

**クロック（各20回）**

| 条件 | 成功 | 電流 |
|---|---|---|
| ハイインピーダンス | 17/20 (85%) | 72.3 mA |
| 2.667 MHz | 16/20 (80%) | 71.7 mA |
| 4.000 MHz | 10/20 (50%) | 71.3 mA |
| **LOW固定** | **0/20 (0%)** | **92.2 mA** |

**カート1番はLOWに落としてはいけない。** 通算0/29。電流も20mA多い。
「駆動しない」であって「LOWにする」ではない。従来は配線していなかったので
結果的にハイインピーダンスで、区別が付いていなかった。

1〜8MHzなら読める（21.477MHzで駄目だったのは速すぎたから）が、与えて得はない。

**電圧（各20回）**

5.00〜4.50Vで **97/120 (81%)、傾向なし。** 信頼区間が全部重なる。
**SA-1もGSUと同じく4.5Vまで丈夫。** 電流が71.0→60.9mAと滑らかに下がるので、
USB側の肩代わりは起きていない。

**窓は閉じない**

起こしてから0〜180秒待っても成功率が落ちない（80/80/80/80/73%）。
「1接続で読み切れ」は窓の寿命が理由ではない。

**判定方法そのものの検証**

1バンク判定と全64バンク読みを20回突き合わせた。一致18/20で、
**外れた2件はどちらも「判定○・全体×」＝楽観側。**
64/64バンクが成立してCRCだけ違う、例の静かに壊れる型だった。
**この節の成功率はすべて約10%の上振れを含む。**
基準80% → 実際の全ダンプ成功率は70%前後と見るのが妥当。

###### 2026-09-02 追試: CICの根拠は20回ずつで消えた

前日の「CICあり4/4 対 CICなし1/6」は標本が小さすぎた。
全64バンクをバイト単位で比べて各20回取り直した。

| 条件 | 1バンク判定 | **全ダンプ** | 95%CI |
|---|---|---|---|
| CICなし | 11/20 | **8/20 (40%)** | 22-61% |
| CICあり | 13/20 | **9/20 (45%)** | 26-66% |

**差がない。** しかもこれは判定の死角ではなく、全64バンクで比べた結果である。

**ただし「CIC不要」とは書かない。** この問いでは既に3回結論を変えており、
今回も**否定できないだけで「同じである」ことを示したわけではない。**
書けるのは「**20回ずつでは差が検出できなかった**」までである。

前日CICなしで観測した「31.6%相違」「96.7%相違」という壊れ方は、
**CICありでも同じ頻度で起きた。** あれはCICの効果ではなく元々ある失敗モードだった。

###### 実際の成功率は40〜60%

| | 成功率 |
|---|---|
| 1バンク判定 | 80-90% |
| **全64バンク（実際に使えるROM）** | **40-60%** |

**判定は楽観側に偏る**（40回中7回が偽陽性）。**SA-1は2回に1回失敗する。**
リトライ前提の運用しかない。

失敗はほぼ全て先頭バンク($C0)から崩れ、うち7回は
「64バンク全部がROMらしいのに中身が違う」型だった。

###### prime は効いている（初めて外して測った）

| | 成功 |
|---|---|
| prime 有 | 19/20 (95%) |
| prime 無 | 15/20 (75%) |

全ての読み出しで prime=True を送り続けており、**一度も外して測っていなかった。**
信頼区間は重なるので断定はできないが、外す理由もない。

###### 起動読みの本体は「読むこと」

| 条件 | 成功 |
|---|---|
| 何もしない | 1/20 |
| **接続を開いて閉じるだけ（読まない）** | **0/20** |
| $E0 を1バンク読む | 14/20 |

**リセットだけでは足りない。読み出しそのものが必要。**

そして**「$E0 が特別」は誤読だった。**

| バンク | 成功 |
|---|---|
| $C0 | 11/20 (55%) |
| $D0 | 13/20 (65%) |
| $E0 | 13/20 (65%) |
| $F0 | 17/20 (85%) |
| **$80（窓の外）** | **0/20 (0%)** |

$C0〜$F0 は信頼区間が完全に重なる。**境界は「SA-1のROM窓の内か外か」。**
起動読みの瞬間はほぼ常に何も読めていない（種類1）のに効く。
**sanniが $C0 を使っているのは間違っていない。**

###### マリオRPGでも通る（手順の一般性）

確定版の手順を20回。**10/20 (50%)、CRC 5527071e = Super Mario RPG (Japan)。**
カービィの40-60%とほぼ同じで、**この成功率はカート個体ではなくSA-1の性質。**

失敗10回はほぼ全部違うCRCで、しかも「64/64バンクがROMらしい」
「ヘッダ『SUPER MARIO RPG』も読める」。**弾いたのは総和検査だけ。**

###### 検証済みの組み合わせ

    CIC認証あり ＋ 起動読みあり ＋ クロック供給なし ＋ 1接続で64バンク

    カービィSDX  CRC32 151bd470 / SHA-1 2f2ff2c75eafa705363feb435a88d2c914d301cf
                 電源断からの4回がすべてバイト単位で一致

##### SA-1のセーブデータは、逆に取り出せない（未達）

ROMとは対称の問題が起きる。CIC認証はどちらにも要る。

    クロックを与えない -> SA-1は眠る   -> ROMが読める / **BW-RAMには届かない**
    クロックを与える   -> SA-1が起きる -> BW-RAMが読める / ROMはSA-1に握られる

**両立しない。** カート1番へのクロック配線1本の抜き差しで切り替わる。

MCKを繋いでCIC認証を成立させると、$6000-$7FFF のBW-RAM窓に実データが現れる
（I-RAM窓も応答する＝SA-1が起動している）。カービィSDXで吸い出した8KBは、
ゲーム自身が初期化する空セーブと**同じ位置に同じ構造**を持っており、
本物のセーブデータであることは間違いない。

しかし**ゲームに読ませると拒否され、空データで初期化される**。
読みごとの相違が8192バイト中27〜166バイトあり、多数決でも詰めきれていない。
セーブデータはROMと違って1バイト違えば全体が無効になる。

    未解決: 読みの誤差なのか、起動したSA-1が自分でBW-RAMを書き換えているのか
    未検証: 同一電源投入内で連続2回読んで比較すれば判別できる

なお**スーパーマリオRPGはSRAM 32KBだが窓は8KB**で、残りはSA-1レジスタ `$2224` の
ブロック切替が要る。`/WR` を +5V に直結した読み出し専用機では書き込めないため
**原理的に到達できない**。カービィSDXはSRAM 8KBなので窓1枚で全部入る。

##### Super FXのセーブはヘッダが容量を偽る

ヨッシーアイランドのヘッダはSRAM容量を **0x00 (=なし)** と申告する。実際には32KBの
バッテリーバックアップRAMがあり、`$70:0000-$7FFF` から読める(バンク `$71` は `$70` の
ミラーだった)。GUIの自動判定は「セーブ領域なし」と表示してしまうので、CLIで手動指定する:

```bash
python host/dump_sram.py --port COM12 --mapping lorom --size 65536 --out YoshiIsland.srm
```

窓の上限が32KBなので、64KBを指定しても32KBが返る。それで全部。
実際にRetroArchへ置いてファイルメニューにセーブが出ることを確認済み。

##### GSUのレジスタ窓は下位32KBにある

読み出しが安定した後も、1バンク(64KB)あたり1,059バイトが 0xFF のまま残る。ただしこれは
問題ではなかった。上下32KBのミラーを比較すると、**相違は `$3000-$34FF` に完全に収まる**。
そこはGSUのレジスタとキャッシュRAMの窓で、丸ごと下位32KB側にある。

LoROMのROMは各バンクの**上位32KB**にしか出ないので、そもそも重ならない。残りの 0xFF は
ROMに実在するパディングで、上下のミラーに同じ位置で現れることがその証拠になる。

##### カートへのクロック供給は Super FX には逆効果

Nano-2 の D11(OC2A) から 1MHz を PHI2(カート57番) へ供給できるようにしてある
(フラグ bit2、既定は供給しない)。SA-1やCIC関連には必要になるが、**Super FXでは有害**。

クロックが無い間GSUは眠っていてROMが見えるが、与えた途端に起きてバスを完全に奪い、
読めるのは4種類の16バイトブロックが延々と続くオープンバスだけになる。
「クロックが無いから通せない」ではなく「**クロックが無いから大人しかった**」が正解だった。

##### `/RESET` を引いた結果（否定的結果）

+5Vに直結していた `/RESET` を Nano-2 の D7 へ引き直し、コプロをリセット保持できるように
した。しかし**Super FXにもSA-1にも効果はなかった**。カートエッジの `/RESET` は主に
カート内のCICへ向かう線で(CIC Pinout参照)、GSUを止めるための線ではないため。

配線自体は残してある(フラグ bit1)。無駄ではないが、コプロ攻略の切り札にはならない。

##### SA-1のCIC認証に挑んだ記録（結論: 吸い出しには不要だった）

> **経緯:** 一時期ここに「この苦労はROM吸い出しには不要だった」と書いたが、
> **それ自体が誤りだった**（上記の訂正節を参照）。CIC認証はROMの読み出しに必要である。
> 以下の記録はそのまま残す。

SA-1はROMを開示する前に、自分のCICを介して本物のSNESと通信していることを検証する
（詳細は下記謝辞のCIC関連資料）。本体基板からジャンク機のF411Aを取り外し、Nano-2の
D11(クロック)・D12(RST)・A6/A7(監視)へ配線して、本体側CICとしてSA-1に握手を挑んだ。

**結論から言うと、通らなかった。** ただし過程で分かったことは記録しておく価値がある。

- **CIC自体は生きて動作している**: RSTを解除するとリセットループを示す振動が観測でき、
  クロック周波数に比例して振動周期が変わる。これはプログラムが実行されている証拠
- **本体→カート側CICのリセット経路は機能している**: 11番ピンを監視すると、1MHz以下の
  クロックでHigh固定（＝Key側が解除されて動いている）になる場面があった
- **握手そのものは一度も安定して成立しなかった**: 250kHz〜8MHzの範囲で掃引したが、
  どの周波数でも「成立」と見えた瞬間は再現性がなく、判定条件を3回作り直しては
  失敗モード側に条件を満たされ続けた（詳細はコード内コメント参照）
- 本来の3.072MHzは16MHzから整数分周で作れない。近い周波数（2.67MHz/4MHz等）を
  試したが、これが握手不成立の原因かは特定できていない
- SEEDピン(3番)はコンデンサ経由でVCCに接続する設計。周辺回路ごと切り出した個体
  （1990年前期型）でも試したが、給電経路の問題か個体差か切り分けられないまま終わった

**「新規部品を買わない」という制約が、初めて本当に効いた場所だった。** DSP-1もSuper FXも
既存の配線とタイミング調整だけで突破できたが、SA-1はそもそも相手役のハードウェア
（正確なクロックとCICの認証プロトコル）が要る。ジャンク機からの部品取りには限界があった。

なお、この一連の作業中に配線の物理的なトラブル（ソケットへの異物混入、ボード焼損）が
発生している。詳細は下の「配線トラブルの記録」を参照。

##### 判定をやめて波形を見たら、配線ミスが見つかった

上に「判定条件を3回作り直しては失敗モード側に条件を満たされ続けた」と書いたが、
最終的にこれは**5回**になった。2.5Vしきい値、瞬間4.4V、200ms保持、1秒保持 —
どれも失敗しているときに満たされてしまった。

原因は判定基準ではなく**測り方**だった。`analogRead()` は1回に約100usかかる。
相手が数十us単位で動いているなら、見えるのは「なんとなくLow」だけで、
そこに意味のあるしきい値は存在しない。

そこでADCをフリーランニングモードにして約6.5us間隔で記録し、900サンプルを
まるごとホストへ持ち帰る簡易ロジックアナライザを作った（`host/cic_scope.py` と
Nano-2側の `logicCapture()`）。**判定をやめて波形そのものを見る**方針に変えた。

これが最初に出した答えは「完全に静止」だった。ところが同じピンを `analogRead()` で
見ると 0.00〜3.77V で振れている。**測定器の側のバグだった** — ビットパックで生値を
潰していたことと、ADC設定変更後の捨て変換を入れていなかったこと。
8bitの生値をそのまま記録する方式に直した瞬間、静止どころではない情報が出てきた。

そして生値を見て初めて、**クロック入力とリセット入力が短絡していた**ことが分かった。
表面実装チップへのはんだ付け不良で、クロックがリセット線に乗っていた。

**この時点で、それ以前の実験は全て無効になった。** 極性の判定も、周波数の掃引も、
データ線を入れ替えた比較も、すべて壊れた治具の上での測定だった。

**教訓**: 「判定が安定しない」ときは判定条件を作り直すのではなく、
生の観測値を取りに行くこと。しきい値をいじっている限り、
測定系そのものが壊れている可能性には辿り着けない。

##### 規定外で動かした部品は、直しても信用してはいけない

短絡を修正した直後、リセット出力は「Highで安定、351msにわたり遷移ゼロ」になった。
これは**私が最初に「成立の証拠」として定義した条件そのもの**だったが、カートは
依然として何も返さなかった。そして数時間後、チップは焦げた。

抜いて単独で測ると、クロック入力・リセット入力・GNDの3本が導通していた。
入力段が内部で焼損していた。つまり修正後に観測した「安定したHigh」は成立ではなく、
**もう動けなくなった部品の沈黙**だった。5回目の誤検出である。

壊れた原因は、ほぼ間違いなく**短絡したまま長時間動かしていた期間**にある。
クロックがリセット入力に直結した状態で通電し続けていた。

**教訓**: 配線ミスを見つけて直したとき、「直った」と「間に合った」は別の話である。
規定外の条件で通電していた部品は、修正後の挙動が改善して見えても、
それが回復なのか劣化の途中経過なのかを外から区別できない。
**修正後の最初の観測は、疑ってかかること。**

また、相手がどう振る舞うか分からない信号線をマイコンの端子に直結したのは設計として
甘かった。片側がLowに固定された線に電流が流れ込む形になり得る。
**直列抵抗を入れるべきだった。**

**アドレス空間に間借りしているだけのタイプ** — 読める
- DSP-1（**スーパーマリオカート**、パイロットウイングス）、CX4（ロックマンX2/X3）

ROMは通常どおりバス上にいる。DSP-1の内部ROMは読めないが、それは `.sfc` に含まれない
（エミュレータが自前で持っている）ので問題にならない。

##### DSP-1カートは $C0 から読む

スーパーマリオカートは HiROM 512KB として素直に8バンク読めるが、**それではチェックサムが
合わない**（実測 0x110e / 期待 0x8a23）。DSP-1 がバンク `$00-$3F` の `$6000-$7FFF` に
マップされていて、その8KB×8バンク＝64KB分がROMではなくDSPの応答になるため。

領域ごとに「異なるバイト値の種類数」を数えると一目で分かる:

| 領域 | 異なる値 |
|---|---|
| `$4000-$5FFF` | 200種（ROM） |
| `$6000-$7FFF` | **4種**（DSPに乗っ取られている） |
| `$8000-$9FFF` | 255種（ROM） |

HiROMではバンク `$C0` 以降にもROM全体がマップされ、そちらにDSP-1は居ない。
**`--start-bank 0xC0` で読み直せばチェックサムが一致する**（CRC32もNo-Introと一致を確認済み）。

#### 配線トラブルの記録 — アドレスが0から進まなくなった一日

SA-1のCIC実験の途中から、Nano-1が生成するアドレスが0で固定される症状が出た
（1バンクの全バイトが同一値になる）。原因の特定に非常に長くかかったので、
切り分けの過程と最終的な原因を記録しておく。

**疑って外れたもの**: Nano-1のファーム、Nano-2のファーム（診断コード追加分を含む）、
配線の断線（導通試験は終始「正常」）、電源、接地ループ、新品Nano-1への交換（同じ症状が
再現した＝ボード個体の問題ではないと確定）。

**通電中のAVRピン同士は導通して見える**: 隣接ピン間をテスターの導通モードで測ると、
チップが通電中は静電気保護ダイオード経由でほぼ必ず「導通」を示す。これはそのチップの
正常な仕様であって、2つのピンが実際に繋がっている証拠にはならない。この日は同じ理由で
誤った手がかりを2回追いかけた。

**受け手に数えさせて初めて切り分けられた**: 導通試験は「2点が繋がっているか」しか
見せてくれず、パルスが実際に届いているかは分からない。Nano-1とNano-3にストローブ/
リセットのパルスをカウントして報告するだけの最小限の診断ファームを書き、Nano-2にも
パルスを出し続けるだけの診断ファームを入れて、3枚を同時に生かして初めて
「Nano-3は受信できているのにNano-1だけ受信できていない」ことが確定した。

**真犯人はNano-1のソケットに挟まっていた金属片**だった。GND-RST間を短絡させており、
ストローブが来るたびにNano-1がリセットされ続けてアドレスカウンタが0から進めなかった。
取り除いた瞬間に解決した。ファームを何度戻しても直らなかったのも、新品のNano-1でも
再現したのも、原因が配線でもコードでもなくハードウェアの異物だった以上当然だった。

**この作業中にNano-3、続けてNano-2が物理的に破損した**（絶縁対策なしでの作業中に別の
金属片が接触）。交換したボードはどちらも異なるブートローダ系統（115200bps、
`arduino:avr:nano:cpu=atmega328`）を積んでおり、それまで使っていた
`cpu=atmega328old`（57600bps）では書き込めなかった。書き込み前に
`avrdude -c arduino -b 57600` と `-b 115200` の両方を試すか、`atmega328`/`atmega328old`
を両方試すのが安全。

**教訓**: 複数のNanoを同時にUSB接続すると、共有GND経由の電位差や電源同士の干渉で
故障のリスクが上がる。通常運用（Nano-2だけがPCと通信する）以外では、同時に挿すのは
1枚だけに留める。

### スーパーFXカートがHiROMと誤判定されていた

STAR FOX を連続読みしたら、こうなった。

    判定結果: HIROM （根拠: 下位32KBに独自データあり）
    map_mode=0x20 / ROMサイズ申告 1024 KB
    → バンク数を 16 に設定
    チェックサム 計算値=0xb6e0 期待値=0xab12 → 不一致

**map_mode=0x20 はLoROM**である。ヘッダ自身が正しく読めているのに、
判定がそれを無視して上書きしていた。

原因は判定の前提。「LoROMなら下位32KBは上位のミラーか、駆動されず0x00になる」
としていたが、**スーパーFXカートはGSUが $0000-$7FFF に応答して独自データを返す。**

    bank$00 上位32KB == 正解の先頭32KB : True   ← 抽出そのものは正しい
    bank$00 下位32KB == 上位32KB       : False  ← ミラーではない。GSUの応答
    下位32KBの値の種類: 256

**ヘッダが妥当なら map_mode を信じるようにした。** read_header は
チェックサムと補数の関係を検査しているので、通った時点で位置は正しい。
下位32KBの状態は、ヘッダが読めなかったときの最後の手段として残してある。

    map_mode の下位4bit  0,2 -> LoROM / 1,5 -> HiROM / 3 -> SA-1

あわせてヘッダ 0x16（カートリッジタイプ）から搭載チップを読むようにした。
判定時に「搭載チップ: スーパーFX (GSU)（0x13）」と表示する。
SA-1カートなら「SA-1カートを吸う」ボタンを使うよう促す。

**DSP-1向けの「$C0から読み直す」も、DSP搭載カートに限定した。**
以前は無条件だったため、スーパーFXでも $C0 を読みに行き、
何も無いので「ヘッダが読めない」まで走って50秒を捨てていた。

修正後、STAR FOX は LoROM / 32バンクと判定され、チェックサム 0xab12 一致、
No-Intro『Star Fox (Japan)』一致、従来のダンプとバイト単位で完全一致した。

### 連続読み — なぜ最初からこれにしなかったのか

昔はストローブを取りこぼして化けたため、1バンクずつ読み直す方式に逃げていた。
取りこぼしはピン変化割り込み(PCINT)で直っており、SA-1の連続読みが実際に
通ることで裏が取れた。**バンクごと読みは、もう回避策としては要らない。**
接触が悪いカートで「2回一致」が取れない場合の手段としては残してある。

### 給電方法による歩留まり（2026-08-31 実測）

起動読みを固定し、給電だけを変えて比較した（カービィSDX、条件同一）。

| 給電 | 正解 | 備考 |
|---|---|---|
| 安定化電源 (DP100 5.00V) | **4/4** | すべて 151bd470 |
| ACアダプター | **2/2** | 安定化電源のダンプとバイト単位で一致 |
| USBバスパワーのみ | **2/6** | Nano-2のUSB1本で全体を給電 |

**「ACアダプタでは電力不足で読めない」は誤りだった。** 以前 0/16 だったのは
起動読みをしていなかったためで、電源のせいではない。

**USB給電の壊れ方が危険。** 6回すべてが `rom_likeness` で 64/64バンク合格したのに、
正解は2回だけ。**品質判定は給電不足を検出できない。総和検査だけが弾いた。**

崩れ方には構造がある。最初の49バンクは正しく、**$F1（読み始めから約73秒）で崩れて
そのまま戻らない**（誤りバンク15/64、各95〜99%相違、8本のデータ線に均等に散る）。
読み進むうちに電圧が垂れる形に見える。

運用手順には「USBバスパワーだけではクロック出力の電圧が足りない」と書いていたが、
SA-1ではクロックを与えないのでこの理由は当てはまらない。
**それでも外部電源は要る。理由はクロックではなく、長い読み出しの完走率。**

---

## 第10章 この記録の読み方

同じ問いで結論を3回変えた箇所がある（CIC認証の要否）。
その経緯をあえて残してあるのは、**訂正の過程そのものが結論と同じくらい重要**だからである。

- **1回の成功や失敗で結論しない。** 各20回を基準にした
- **信頼区間を見る。** 5回試行では 1/5 と 4/5 を区別できない
- **判定方法自体を検証する。** 1バンク判定は全ダンプに対し楽観側へ偏っていた
- **否定できないことと、同じであることは違う**

---

## 付随して作ったもの

- **GUIアプリ** — Tkinterのみ（ブラウザ不要）。ポート選択、ファーム書き込み、カート判定、
  チェックサムが一致するまでの自動ダンプ
- **オフラインDB検索** — RetroArch同梱の `.rdb`（No-Intro準拠、7,621件）を読む
  MessagePackデコーダを自前実装。タイトル名から正確なバイト数を引ける。ネットワーク不要
- **検証ツール群** — `timing_tune.py`（正解と照合しながら最速設定を探す）、
  `degradation_test.py`（誤りが累積的か調べる）、`probe_size.py`（ミラーからROM実サイズを測る）

---

## まだ分かっていないこと

- **長時間の連続読み出しで壊れる**現象を、当初は電源の問題と考えていました。
  真因がNano-1の取りこぼしだったと判明した今、この現象も同じ原因だった可能性がありますが、
  **未検証**です。割り込み版で長時間の通しダンプを試せば白黒つきます
- Nano-2の制御ピンはまだ `digitalWrite` のままで、47µsのうち約34µsがそのオーバーヘッドです。
  ここをポート直叩きにすれば **15µs/バイト（2MBで約1分）** が見込めます

---

## 全体を通しての教訓

1. **ヘッダのチェックサム欄が通っても、ROMが正しいとは限らない。** 全バイト総和で検証する
2. **ROMの自己申告（map mode、サイズ）は自分の推論より信頼できる**
3. **単発の測定を信じない。** 2回一致してようやく候補、CRCが合ってようやく確定
4. **決定的か確率的かを見分ける。** 毎回同じ誤りならノイズではなく論理の誤り。
   これが最大の突破口になった
5. **数値の規則性を疑う。** `出力[i] == 正解[i÷2]` に気づけたのは、ずれ方を総当たりで
   検算したから。「壊れている」で止めずに「どう壊れているか」を測る

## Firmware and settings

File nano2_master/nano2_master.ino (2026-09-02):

// Nano-2: バスサイクル制御 + データ読み取り + USBストリーム（案A: SDなし、PC直送）
//
// 手順（1バイトごと）:
//   1. /ROMSEL, /RD をLowにしてROMを選択・読み出しアサート
//   2. 数us待ってからD0-D7を読む
//   3. /RD, /ROMSELをHighに戻す
//   4. Serial.write()でPCへ送信
//   5. STROBEパルスでNano-1のアドレスを+1
//   6. 64KB(1バンク分)読み終えたらNano-3へ次のバンク値を送る
//
// 出荷時点でNUM_BANKSは仮値。実際のROMサイズが分かったら書き換えて再書き込みすること。
// (ヘッダ自動判定は未実装。まずは大きめの値で全部読み、PC側で余分を切り捨てる運用でも良い)

const uint8_t RD_PIN = 2;
const uint8_t ROMSEL_PIN = 3;
const uint8_t STROBE_PIN = 4;
// 旧DATA/CLK/LATCHのシフトレジスタ方式は非同期タイミングのレースで不安定だったため廃止。
// 配線はそのまま流用し、旧BANK_DATA線をRESET、旧BANK_CLK線をSTROBEとして使う(Nano-1と同じ方式)。
const uint8_t BANK_RESET_PIN = 5;
const uint8_t BANK_STROBE_PIN = 6;
// 旧BANK_LATCH線(D7)はNano-3のD12から切り離し、カートの /RESET へ引き直した。
// カート側で +5V に直結していた線は撤去済み(残したままここをLowにすると電源とショートする)。
// 通常はHighに保つ。コプロ(Super FX / SA-1)をリセット状態に保持してROMを覗きたいときだけLow。
const uint8_t CART_RESET_PIN = 7;
const uint8_t D6_PIN = 8;
const uint8_t D7_PIN = 9;
const uint8_t DATA_LOW_PINS[6] = {A0, A1, A2, A3, A4, A5}; // cart D0-D5
const uint8_t ADDR_RESET_PIN = 10; // Nano-1のアドレスカウンタを0に戻す

// 配線替え: このピンは元々カート57番(PHI2/SYSCK)に繋いでいたが、
// SA-1の解錠中にSYSCKを供給するとデータが壊れるという報告があったため、
// カート1番(MCK)へ繋ぎ直した。SA-1には自前の発振子が無く、MCKが無いと
// チップ全体がただの箱になる。CIC認証だけが通ってROMが0のままだった
// 症状は、これで説明がつく。
//
// D11でなければならない理由: ソフトでは出せずタイマーのハードウェア出力が要る。
// Nano-2で解放できるタイマー出力ピンはOC2A(=D11)だけ。
//
// 実機のMCKは21.477MHzだが、AVR(16MHz)のタイマーで単純トグルできる上限は
// 8MHz(Fclk/2)なので正確には出せない。OSCRは解錠時にあえて4MHzへ落として
// 供給し、成功後に21.477MHzへ戻している実績があるため、解錠時は4MHzで試す
// (startCartClockのocr=1が4MHz)。
const uint8_t CART_CLK_PIN = 11;

// カート33番(REFRESH)。SA-1に必要、Low固定で出力する。
// D13は基板上のLED+抵抗が乗るが、ここは静的なLow出力なので問題ない
// (OLEDデータ線や監視線のような双方向・高速・微弱信号ではない)。
const uint8_t REFRESH_PIN = 13;

// 起動時からカートへ出すクロックの分周値。-1 で「読み出し時だけ」。
// 16MHz/(2*(1+n)) が出力周波数。1=4MHz / 3=2MHz / 7=1MHz / 0=8MHz。
//
// **既定は -1（無効）。** Super FX ではカートへのクロックは有害で、与えた途端に
// GSUが起きてバスを完全に奪う（README「カートへのクロック供給は Super FX には逆効果」）。
// 全カートに無条件で流すわけにはいかない。
//
// なお、これを有効にしても読み出し要求時の `--clock` の代わりにはならない。
// スーパーマリオRPGのバンク$C0を安全段階で3回読むと、読み出しごとに明示指定した
// 場合は相違0、起動時クロックだけの場合は1〜2バイト化けた。Nano-2はシリアルを
// 開くたびリセットされるのでクロックも途切れる。sanniがSi5351(独立したIC)を
// 使って回しっぱなしにしているのは、この構造的な差を避けるためでもある。
// 起動時からカートへ出すクロックの分周値。-1 で「読み出し時だけ」。
// 16MHz/(2*(1+n)) が出力周波数。1=4MHz / 3=2MHz / 7=1MHz / 0=8MHz。
//
// **2026-08-28: 一度 1(4MHz常時) にして D11 -> カート56番 を試したが失敗した。**
// 「実データ率1.00」と出たので窓が消えたと判断したが、**判定が誤っていた**。
// 0x00 や 0x02 で埋まっていても「0xFFではない」ので1.00になる。
// 実際には KIRBY の文字列がROM内のどこにも存在せず、中身は空だった。
// Nano-3のD12が認証後に手放すのと同じ状態に戻す。
//
// **既定は -1（無効）。** Super FX ではカートへのクロックは有害で、与えた途端に
// GSUが起きてバスを完全に奪う（README「カートへのクロック供給は Super FX には逆効果」）。
const int8_t BOOT_CART_CLOCK_OCR = -1;

// 検証用。true にすると起動時クロックを約30Hzまで落とす（テスターで平均電圧を読むため）。
// 通常のダンプでは必ず false に戻すこと。
const bool BOOT_CART_CLOCK_SLOW = false;

// ■ sanniの起動シーケンスを再現する（2026-08-28）
//
// setup_Snes() を逐語で読み直したら、**周波数の解釈を間違えていた**。
// Si5351の set_freq は 0.01Hz 単位（後段の 2147727200 = 21.47727MHz から確定）。
// つまり起動時の設定は:
//
//     clockgen.set_freq(400000000ULL, SI5351_CLK0);  // マスター =  4.000MHz
//     clockgen.set_freq(100000000ULL, SI5351_CLK2);  // CIC     =  1.000MHz
//     clockgen.output_enable(SI5351_CLK1, 0);        // CPU     = 無効
//     delay(500);
//     PORTG &= ~(1 << 1);                            // CICリセット解除
//     delay(500);
//     getCartInfo_SNES();                            // ← ここでヘッダを読む
//     // **その後で** 21.477MHz / 3.072MHz へ上げる
//
// **ヘッダが読めるまでは低い周波数で動かしている。**
// こちらは最初から21.477MHzを流しっぱなしだった。順序が違う。
//
// 1MHzはNano-2のTimer2で誤差なく作れる: 16MHz/(2*(1+7)) = 1.000MHz (OCR2A=7)
//
// 0 にするとこの機能を使わない。
const uint16_t BOOT_CLOCK_BURST_MS = 0;

// CICクロック(カート56番)の分周値。7 = 1.000MHz（sanniの起動時と同じ）。
// -1 で出さない。
// -2 = D11を静的にLowで駆動 / -3 = 静的にHigh（配線が生きているかの確認用）
// **CICクロックは21.4MHzduinoが出すようになったので、-1(出さない)にする。**
// D11はカート56番から外れた。ここから出しても行き先が無い。
// 出力の衝突を避けるためにも無効のままにしておくこと。
const int8_t CIC_CLOCK_OCR = -1;
// Nano-3が電源投入300ms後にCICリセットを打つ。sanniはリセット解除後500ms待つので、
// それを覆う時間だけクロックを出し続けてから読み出しに入る。
const uint16_t CIC_SETTLE_MS = 900;

// OLEDは休止中。D11をカートのクロック出力に明け渡した際、データ線をD13へ移したが、
// D13にはNano基板上のLEDと抵抗がぶら下がっていて駆動が足りず表示できなくなった。
// Nano-2に他の空きピンは無いため、進捗表示を諦めてD12/D13をCIC制御へ回す。
// 1に戻せば元の配線(clock=12,data=11)で復活するが、その場合カートクロックは使えない。
#define USE_OLED 0

#if USE_OLED
#include <U8x8lib.h>
U8X8_SH1106_128X64_NONAME_SW_I2C oled(/*clock=*/ 12, /*data=*/ 11, /*reset=*/ U8X8_PIN_NONE);
#else
// 呼び出し側を #if で汚さずに済ませるための何もしない代替。
static const uint8_t *u8x8_font_chroma48medium8_r = nullptr;
struct OledStub {
  void begin() {}
  void clear() {}
  void setFont(const uint8_t *) {}
  void drawString(uint8_t, uint8_t, const char *) {}
  void draw2x2String(uint8_t, uint8_t, const char *) {}
  void setInverseFont(uint8_t) {}
} oled;
#endif

// ── CIC(F411A)の制御 ────────────────────────────────────────────────
// SA-1はROMを開示する前に、自分のCICを介して本物の本体と通信していることを検証する。
// 本体基板から取り外したF411Aを繋ぎ、その検証相手を務めさせるための配線。
//
//   CIC 8番(RST)  <- D12    リセットを解除すると認証が始まる
//   CIC 10番(/RESET出力) -> A6   認証に失敗している間Lowのまま
//   CIC 7番(CLK)  <- D11    カートの56番/57番と同じクロックを分岐して供給
//
// A6を使うのはNanoの入力専用ピンだから。出力に使えず今まで遊んでいた。
// D13を避けるのは上記のLEDのため。監視線に余計な負荷を掛けたくない。
const uint8_t CIC_RST_PIN = 12;
const uint8_t CIC_OK_PIN = A6;   // analogRead専用。digitalReadは使えない
// A7は用途を付け替えながら使う唯一の観測窓。今はCICのデータ線(1番)を見ている。
// 11番(カート側CICのリセット)を見たときは、1MHz以下でHigh固定＝Key側は解除されて
// 動いていることが確認できた。次に知りたいのは「両者が実際に喋っているか」なので、
// データ線に移した。振動していれば通信は起きていて中身が合わないだけ、静止していれば
// どちらかが応答していない。
const uint8_t CIC_PROBE_PIN = A7;

// 16MHz / (2 * (1 + OCR2A)) = 出力周波数。7で1MHz、1で4MHz、0で8MHz。
// slow=true では1024分周を掛ける。16MHz/1024/(2*(1+OCR2A))。OCR2A=255で約30Hz。
//
// なぜ低速モードが要るのか: 「発振しているか」をテスターで確かめるため。
// 50%デューティの方形波はDCモードで電源電圧の半分(2.5V)に見えるはずだが、
// 4MHzでは実測1.75Vだった。テスターのDC帯域は普通数kHz程度しかないので、
// この値は「発振していない」証拠にも「電圧不足」の証拠にもならない。
// 30Hzまで落とせばどんなテスターでも正確に平均でき、2.5Vちょうどが出れば
// 出力は健全（＝1.75Vは測定器側の帯域不足）と確定する。
void startCartClock(uint8_t ocr, bool slow) {
  pinMode(CART_CLK_PIN, OUTPUT);
  TCCR2A = _BV(COM2A0) | _BV(WGM21); // CTCモード、比較一致でOC2Aをトグル
  TCCR2B = slow ? (_BV(CS22) | _BV(CS21) | _BV(CS20))  // 1024分周
                : _BV(CS20);                            // 分周なし
  OCR2A = ocr;
}

// バンク単位モード:
//   長時間連続で読み続けると読み取りが化ける（同じバンクでも全体ダンプ中は毎回700バイト前後
//   誤るのに、単独で読めば2回とも完全一致する）。そこで1回の起動につき1バンクだけ読む。
//   PC側が起動ごとに「読みたいバンク番号」を1バイト送ってくる。
const uint32_t BANK_SIZE = 65536UL;

// PC側がシリアルポートを開くたびDTRでリセットがかかるため、放っておくと
// 1バンクごとに起動演出が流れる（64バンク×2回=128回）。
// SRAMの内容はリセットでは保持され、電源を切ると失われる。この性質を使って
// 「電源を入れた最初の1回」だけ演出を出す。.noinit なので初期化されない。
__attribute__((section(".noinit"))) uint32_t bootMagic;
const uint32_t BOOT_MAGIC = 0x5FC0DEADUL;

// 読み出しタイミングはPC側から毎回指定される（コンパイル時固定ではない）。
// 理由: 必要なマージンはカートのROMチップ個体差でかなり違う。同じ5usの設定で
// Super Mario Collection と 夜光虫 は一発で通ったが、Street Fighter II は
// 2回連続一致に何度失敗しても揃わず、100usまで上げてようやく安定した。
// 全カート一律で遅くするのは、マージンが要らないカートの速度を無駄に捨てることになる。
// そこでPC側が「まず5usで試し、駄目なら段階的に上げる」エスカレーションを行い、
// 都度この変数へ値をセットしてから読む。
uint16_t rdSettleUs = 5;
uint16_t addrSettleUs = 5;
uint16_t pulseUs = 3;

void setDataPinsInput() {
  for (uint8_t i = 0; i < 6; i++) pinMode(DATA_LOW_PINS[i], INPUT);
  pinMode(D6_PIN, INPUT);
  pinMode(D7_PIN, INPUT);
}

// cart D0-D5 -> A0-A5 = PINC bit0-5 / cart D6-D7 -> D8-D9 = PINB bit0-1
// ■ 制御線のポート直叩き（2026-08-27 高速化）
// digitalWrite は1回**約4us**かかる。ピン番号からポートを引き、割り込みを止め、
// PWMを無効化する処理が毎回走るため。1バイトあたり6回呼んでいたので24us、
// tier1の実測77.7us/byteのうち3割がここだった。
//
// RD_PIN=2 / ROMSEL_PIN=3 / STROBE_PIN=4 はいずれも PORTD なので、
// ビット操作1命令(約0.06us)で置き換えられる。70倍速くなる。
//
// なお Nano-1 は**既に直叩き化済み**だった。addrSettleUs のコメントにある
// 「Nano-1側の16本分のdigitalWrite完了を待つマージン」は、直叩き化する前の
// 古い記述が残っていたもの。実コードは writeAddr() で3命令しか使っていない。
#define RD_HIGH()     (PORTD |= _BV(PD2))
#define RD_LOW()      (PORTD &= ~_BV(PD2))
#define ROMSEL_HIGH() (PORTD |= _BV(PD3))
#define ROMSEL_LOW()  (PORTD &= ~_BV(PD3))
#define STROBE_HIGH() (PORTD |= _BV(PD4))
#define STROBE_LOW()  (PORTD &= ~_BV(PD4))

static inline uint8_t readDataBus() {
  return (uint8_t)((PINC & 0x3F) | ((PINB & 0x03) << 6));
}

void resetNano1Addr() {
  digitalWrite(ADDR_RESET_PIN, HIGH);
  delayMicroseconds(pulseUs);
  digitalWrite(ADDR_RESET_PIN, LOW);
  delayMicroseconds(100);
}

void pulseStrobe() {
  STROBE_HIGH();
  if (pulseUs) delayMicroseconds(pulseUs);
  STROBE_LOW();
  // Nano-1がPCINT割り込みでアドレスを更新し終えるのを待つ。
  // Nano-1側は既に直叩き(writeAddrは3命令)なので、必要なのは
  // 「割り込みが起動してISRが走り終わる」時間だけ。従来の20usは過剰の疑いがある。
  // ただし削りすぎるとアドレスがずれたまま読むので、正解の分かっている
  // カートで実測して決めること。
  if (addrSettleUs) delayMicroseconds(addrSettleUs);
}

void resetNano3Bank() {
  digitalWrite(BANK_RESET_PIN, HIGH);
  delayMicroseconds(pulseUs);
  digitalWrite(BANK_RESET_PIN, LOW);
  delayMicroseconds(100);
}

// Nano-1のpulseStrobe()と同じ発想: このパルス1回でNano-3のバンクが+1される
void pulseBankStrobe() {
  digitalWrite(BANK_STROBE_PIN, HIGH);
  delayMicroseconds(pulseUs);
  digitalWrite(BANK_STROBE_PIN, LOW);
  delayMicroseconds(100);
}

void splashScreen() {
  oled.clear();
  oled.setFont(u8x8_font_chroma48medium8_r);

  // 枠線
  oled.draw2x2String(1, 1, "SFC");
  oled.draw2x2String(1, 4, "DUMP");
  oled.drawString(2, 7, "Nano x3 Reader");

  delay(600);

  // ローディングバー風アニメーション
  char bar[17] = "[              ]";
  for (uint8_t i = 0; i < 14; i++) {
    bar[i + 1] = '#';
    oled.drawString(0, 6, bar);
    delay(70);
  }
  delay(300);

  // 起動完了フラッシュ演出
  for (uint8_t i = 0; i < 3; i++) {
    oled.setInverseFont(1);
    oled.drawString(2, 7, "Nano x3 Reader");
    delay(120);
    oled.setInverseFont(0);
    oled.drawString(2, 7, "Nano x3 Reader");
    delay(120);
  }

  delay(400);
  oled.clear();
}

// セーブ用SRAMを読むときは /ROMSEL をアサートしてはいけない。
// ROMは /ROMSEL で選択されるが、カート上のSRAMはバンク($70〜 / $20〜)とアドレスを
// カート内部のデコード回路が見て自前で選択する。ROM読み出しと同じように /ROMSEL を
// Lowにすると、SRAMではなくROM側が応答してしまう。
//
// なお /WR はカート側で +5V に直結してあるので、ここで何をしようとSRAMへの書き込みは
// 物理的に起こらない。救出対象のセーブデータを壊す事故は原理的に発生しない。
bool sramMode = false;

// ■ sanni方式: /RD と /ROMSEL を Low に固定したまま読む（2026-08-28）
//
// sanni の setup_Snes() は起動時に一度だけ落として、以後**一切動かさない**:
//
//     PORTH &= ~((1 << 3) | (1 << 6));   // /CS と /RD を LOW
//
// そして readBank_SNES() は「アドレスを置く → 6NOP待つ → PINCを読む」だけ。
// **制御線をバイトごとに触らない。**
//
// こちらは1バイトごとに /ROMSEL と /RD を Low→High と往復させていた。
// 64KBなら65536回。SA-1は**バス調停チップ**なので、制御線が動くたびに
// 「SNES側が新しいバスサイクルを始めた」という信号になり、
// **そのたびに調停の機会を与えている**ことになる。
//
// 「バンクの途中で力尽きる」「数秒で閉じる」という実測は、
// この往復のどこかでSA-1にバスを奪われていると考えると筋が通る。
//
// HOLD_STROBES_LOW = 1 でsanni方式（固定）、0 で従来方式（往復）。
//
// **注意**: /RD をLow固定にするとROMが常時データを出し続ける。
// アドレス変更中も出力されるので、配線によってはバス競合や消費電流増が起きうる。
// sanniのMega構成では問題ないが、この配線で同じとは限らない。
#define HOLD_STROBES_LOW 0

// ══════════════════════════════════════════════════════════════════════
// カートへの書き込み（SA-1のBW-RAM窓を開けるためのレジスタ書き込み用）
//
// **既定では絶対に動かない。** ホストが flags bit6(0x40) を立てたときだけ通る。
// /WR を出すのは Nano-1 で、こちらは「長いストローブ」で指示する。
//
// ■ なぜ長いストローブなのか
// Nano-1 はPCと通信できず、知っているのは STROBE と RESET だけ。
// STROBE の立ち上がりでアドレスを+1したあと、まだHIGHのままなら書き込み指示、
// という約束にしてある。**アドレスを進めた直後なので目的の番地に書ける。**
// RESET幅で判定する案は、リセット直後でアドレスが必ず0になり使えなかった。
//
// ■ 手順
//   1. RESET（短く）           addr = 0
//   2. STROBE × (A-1) 回（短く） addr = A-1
//   3. データバスを出力にして値を置く
//   4. STROBE × 1 回（長く）    addr = A になり、その状態で /WR が出る
//   5. データバスを入力に戻す
//
// ■ 守っていること
//   ・データはストローブを上げる**前**に確定させる（/WRはISR内で即座に出るため）
//   ・書き終わったら必ず入力に戻す。カートと出力がぶつかる時間を最小にする
//   ・/ROMSEL は上げたまま（$2224 等は $8000 未満なのでROM領域ではない）
// ══════════════════════════════════════════════════════════════════════

// Nano-1 が「書き込み指示」と判定する閾値を確実に超える長さ。
// Nano-1 側は WR_COUNT_MIN 回のループで判定しており、実測前なので余裕を取る。
const uint16_t WRITE_STROBE_US = 200;

void setDataPinsOutput(uint8_t value) {
  // 先に値を確定させてから出力にする。出力にした瞬間に前の値が出ないように。
  for (uint8_t i = 0; i < 6; i++) digitalWrite(DATA_LOW_PINS[i], (value >> i) & 1);
  digitalWrite(D6_PIN, (value >> 6) & 1);
  digitalWrite(D7_PIN, (value >> 7) & 1);
  for (uint8_t i = 0; i < 6; i++) pinMode(DATA_LOW_PINS[i], OUTPUT);
  pinMode(D6_PIN, OUTPUT);
  pinMode(D7_PIN, OUTPUT);
  // pinMode後にもう一度書く。INPUT時のdigitalWriteはプルアップ設定なので。
  for (uint8_t i = 0; i < 6; i++) digitalWrite(DATA_LOW_PINS[i], (value >> i) & 1);
  digitalWrite(D6_PIN, (value >> 6) & 1);
  digitalWrite(D7_PIN, (value >> 7) & 1);
}

void pulseStrobeLong() {
  STROBE_HIGH();
  delayMicroseconds(WRITE_STROBE_US);   // Nano-1 がここで /WR を出す
  STROBE_LOW();
  delayMicroseconds(20);
}

// バンク0の address に data を1バイト書く。
// SA-1のレジスタ($2224/$2226/$2228)を叩くのが目的なので bank は0固定でよい。
// Nano-3 にCIC認証をやり直させる。
//
// **バンクリセット線を長く保持するだけ。配線は増やさない。**
// Nano-3側は「短い→バンクを0に戻す（従来）」「長い→加えて認証やり直し」で分けている。
//
// 認証は数十ms掛かり、その間 Nano-3 はバンクストローブを受け付けない。
// **戻ってくるまで読み出しを始めてはいけない。** 余裕を見て待つ。
const uint16_t REAUTH_HOLD_US = 1000;   // Nano-3 の閾値を確実に超える長さ
const uint16_t REAUTH_WAIT_MS = 300;    // 認証と再初期化が終わるのを待つ

void requestReauth() {
  digitalWrite(BANK_RESET_PIN, HIGH);
  delayMicroseconds(REAUTH_HOLD_US);
  digitalWrite(BANK_RESET_PIN, LOW);
  delay(REAUTH_WAIT_MS);
  resetNano3Bank();          // 認証後の状態を揃えるため、通常のリセットを1回入れる
}

void writeCartByte(uint16_t address, uint8_t data) {
  // **バンク(A16-A23)を0に戻すのを忘れてはいけない。**
  // ここを抜かしたまま実装し、起動読みで $E0 を読んだ直後の状態から書いていたため、
  // SA-1のレジスタがある $00:2224 ではなく $E0:2224 に書いていた。
  // 「窓が開かない」のではなく、窓を開ける場所に書いていなかった。
  resetNano3Bank();                       // A16-A23 = 0
  resetNano1Addr();                       // addr = 0
  for (uint16_t i = 0; i + 1 < address; i++) pulseStrobe();   // addr = address-1
  setDataPinsOutput(data);                // **ストローブより先に値を確定させる**
  if (addrSettleUs) delayMicroseconds(addrSettleUs);
  pulseStrobeLong();                      // addr = address になり /WR が出る
  setDataPinsInput();                     // **必ず入力へ戻す**
}

uint8_t readByte() {
#if HOLD_STROBES_LOW
  // 制御線はsetup()でLowにしたまま。ここでは触らない。
  if (rdSettleUs) delayMicroseconds(rdSettleUs);
  return readDataBus();
#else
  if (!sramMode) ROMSEL_LOW();
  RD_LOW();
  // delayMicroseconds(0) はArduinoの実装でループカウンタがアンダーフローし、
  // 極端に長く待つ既知の罠がある。0のときは呼ばない。
  if (rdSettleUs) delayMicroseconds(rdSettleUs);
  uint8_t v = readDataBus();
  RD_HIGH();
  if (!sramMode) ROMSEL_HIGH();
  return v;
#endif
}

// CICを起動して認証の成立を待つ。戻り値は成立したかどうか。
//
// 10番ピンは本体のリセット線を駆動する出力で、CICは認証が通らない限りここをLowに
// 保持し続ける。つまり**ROMを読む前に握手の成否だけを切り分けられる**。
// これが無いと「読めない」という結果だけを見て、認証・配線・クロックのどれが悪いのか
// 区別できなくなる。
// 監視ピンの実測値の範囲も返す。'成立/不成立'の一言だけだと、A6がCICを本当に読めて
// いるのか(繋がっていて常にLow)、それとも浮いてノイズを拾っているだけなのかが分からない。
// 実測の最小値・最大値が分かれば、固定Low・固定High・不安定のどれかを判別できる。
// リセットを解除したあと、監視ピンが実際に何をしているかを1秒間観測して返す。
//
// 二値の「成立/不成立」を判定条件で決めようとして三度失敗した(2.5V閾値・4.4V瞬時・
// 200ms保持)。いずれも失敗モード側が条件を満たせてしまう。CICは認証に失敗すると本体を
// リセットし続けるので出力は振動し、クロックを落とすほどその周期が伸びて、どんな
// 「一定時間High」条件もいつかは通過してしまう。
//
// なので判定をやめて波形を測る。認証が通ったならリセットは恒久的に解除され、遷移は
// 起きないはず。失敗しているなら往復が観測される。
// Arduinoのプリプロセッサは構造体定義より前に関数プロトタイプを差し込むため、
// 自作型を引数に取るとコンパイルが通らない。素直にグローバルで受け渡す。
uint8_t obsKeyLo, obsKeyHi, obsKeyTransitions;  // 11番(カート側CICのリセット)の観測
uint8_t obsLo, obsHi;        // 観測した電圧の範囲(0-255に丸め)
uint8_t obsTransitions;      // Low↔Highの遷移回数。0でHigh維持なら本物
bool obsEndedHigh;

// ── 簡易ロジックアナライザ ──────────────────────────────────────────
// analogRead()は1回に約100usかかる。CICの握手はそれよりずっと速く進むので、
// 「Low固定に見えた」のは単に速すぎて見えていなかっただけの可能性がある。
//
// ADCを毎回起動・停止するのをやめ、フリーランニング(連続変換)モードにすると
// 1変換13クロック。プリスケーラ8で16MHz/8=2MHz、つまり約6.5us間隔まで詰められる。
// 8bit精度(ADLARで上位バイトだけ読む)で十分——見たいのはHigh/Lowだけなので。
//
// 1サンプル1ビットに潰してRAMへ詰めるので、900バイトで7200サンプル＝約47ms分。
// CICの握手は内部計算を挟みながら進むので、開始部分を捉えるにはこれで足りる。
#define LA_BYTES 900
uint8_t laBuf[LA_BYTES];

// ch: 6=A6(CICの10番/リセット出力) 7=A7(CICのデータ線)
static void logicCapture(uint8_t ch, bool activeLow, uint8_t decim) {
  // ADC設定: 基準電圧AVCC、左詰め(上位8bitだけ読む)、指定チャンネル
  ADMUX = _BV(REFS0) | _BV(ADLAR) | (ch & 0x0F);
  ADCSRB = 0;                                   // フリーランニング
  // ADEN=有効 ADATE=自動トリガ ADPS=8分周(2MHz)。まだ開始しない。
  ADCSRA = _BV(ADEN) | _BV(ADATE) | _BV(ADPS1) | _BV(ADPS0);

  // 初回変換は25クロックかかる上、チャンネル切替直後の値は当てにならない。
  // 捨て変換を数回まわしてから本番に入る。ここを省いて同じ古い値を読み続け、
  // 「完全に静止」という誤った観測を得ていた。
  ADCSRA |= _BV(ADSC);
  for (uint8_t i = 0; i < 4; i++) {
    while (!(ADCSRA & _BV(ADIF))) { }
    ADCSRA |= _BV(ADIF);
  }

  // リセットを解除して、その瞬間から記録を始める。時間の基準点になる。
  //
  // 極性を引数で受けるのは、以前「アクティブLowで確定」と判断した根拠が、
  // 7-8番ピンが短絡していた時期の観測だったため。あの時はRSTピンにクロックが
  // 乗っていて、どちらの極性を指定してもチップは叩かれ続けていた。判定は無効。
  pinMode(CIC_RST_PIN, OUTPUT);
  digitalWrite(CIC_RST_PIN, activeLow ? LOW : HIGH);
  delay(20);
  digitalWrite(CIC_RST_PIN, activeLow ? HIGH : LOW);

  // 閾値で潰さず、8bitの生値をそのまま記録する。
  // 「完全に静止」という結果が測定系のバグなのか本当に信号が無いのかを、
  // 二値化した後のデータからは区別できない。生値なら中間電位もノイズも見える。
  // decim個に1個だけ記録して観測窓を伸ばす。握手の開始が遅い場合、
  // 6.5us刻みの5.8msでは窓の外に出てしまうため。
  for (uint16_t i = 0; i < LA_BYTES; i++) {
    for (uint8_t d = 0; d < decim; d++) {
      while (!(ADCSRA & _BV(ADIF))) { /* 変換完了待ち */ }
      laBuf[i] = ADCH;
      ADCSRA |= _BV(ADIF);
    }
  }
  ADCSRA = 0;   // ADCを止めて通常のanalogRead()に戻せるようにする
}

static void cicObserve(bool activeLow, uint16_t windowMs) {
  pinMode(CIC_RST_PIN, OUTPUT);
  digitalWrite(CIC_RST_PIN, activeLow ? LOW : HIGH);
  delay(20);
  digitalWrite(CIC_RST_PIN, activeLow ? HIGH : LOW);

  uint16_t mn = 1023, mx = 0, kmn = 1023, kmx = 0;
  uint8_t tr = 0, ktr = 0;
  bool prevHigh = false, kPrevHigh = false, first = true;
  const uint32_t deadline = millis() + windowMs;
  while (millis() < deadline) {
    const uint16_t v = analogRead(CIC_OK_PIN);
    if (v < mn) mn = v;
    if (v > mx) mx = v;
    const bool h = (v > 900);
    if (!first && h != prevHigh && tr < 255) tr++;
    prevHigh = h;

    const uint16_t k = analogRead(CIC_PROBE_PIN);
    if (k < kmn) kmn = k;
    if (k > kmx) kmx = k;
    const bool kh = (k > 900);
    if (!first && kh != kPrevHigh && ktr < 255) ktr++;
    kPrevHigh = kh;
    first = false;
  }
  obsKeyLo = (uint8_t)(kmn >> 2);
  obsKeyHi = (uint8_t)(kmx >> 2);
  obsKeyTransitions = ktr;
  obsLo = (uint8_t)(mn >> 2);
  obsHi = (uint8_t)(mx >> 2);
  obsTransitions = tr;
  obsEndedHigh = prevHigh;
}

void setup() {
  // /RESET はアクティブLow。先にポートビットを立ててから出力に切り替えると、
  // 一瞬もLowを出さずに済む。逆順だと数サイクルLowが出てカート内のチップが不用意に
  // リセットされる。なお電源投入からここに来るまでの間はINPUTのまま浮いている。
  digitalWrite(CART_RESET_PIN, HIGH);
  pinMode(CART_RESET_PIN, OUTPUT);
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
void loop() {}

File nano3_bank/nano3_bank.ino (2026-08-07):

// Nano-3: cart A16-A23（バンク）カウンタ ＋ OLED進捗表示
// Nano-1のアドレスカウンタと同じ「STROBEで+1、RESETで0」方式。
// 旧DATA/CLK/LATCHのシフトレジスタ方式は、2枚のNanoが非同期クロックで動くため
// タイミングのレースでビットを取りこぼし不安定だったので廃止した。
// 配線は変更していない。旧BANK_DATA線(D10)をRESET、旧BANK_CLK線(D11)をSTROBEとして使う。
// 旧BANK_LATCH線(D12)は未使用。
//
// Nano-1と同じ理由でピン変化割り込みを使う（ポーリングだとパルスを取りこぼす）。
//
// ■ OLEDをNano-2からこちらへ移した理由
// 元はNano-2が読み出しループの中で8192バイトごとにI2Cをビットバンギングしていた。
// 読み出しの真っ最中に数msかけてピンを叩き、表示モジュールが電流を食う設計で、
// 読み取り品質への影響が疑われた。またNano-2のD11をカートのクロック出力に明け渡した際、
// OLEDのデータ線をD13へ逃がしたところ基板上のLEDと抵抗が負荷になって表示できなくなり、
// Nano-2には他に空きピンが無かった。
//
// Nano-3は本来ほぼ遊んでいる上に、**バンク番号をすでに知っている**（ストローブを数えた
// 値がそのままバンク番号）。バイト位置もNano-2→Nano-1のSTROBE線を分岐して数えれば分かる。
// 表示が多少もたついても、あるいは取りこぼしても、**ダンプの正しさには一切影響しない**。
//
// ピン割り当てとポートの対応:
//   A16-A21 -> D2-D7  = PORTD bit2-7
//   A22-A23 -> D8-D9  = PORTB bit0-1
//   RESET   -> D10    = PINB bit2 (PCINT2)
//   STROBE  -> D11    = PINB bit3 (PCINT3)
//   OLED SCL-> A0                          (ソフトI2C。D13はLEDが負荷になるので使わない)
//   OLED SDA-> A1
//   BYTE STB-> A2     = PINC bit2 (PCINT10) Nano-2 D4から分岐した1バイトごとのパルス

#include <U8x8lib.h>

const uint8_t BANK_PINS[8] = {2, 3, 4, 5, 6, 7, 8, 9}; // A16..A23
const uint8_t RESET_PIN = 10;
const uint8_t STROBE_PIN = 11;
const uint8_t BYTE_STROBE_PIN = A2;

#define RESET_BIT  _BV(PB2)
#define STROBE_BIT _BV(PB3)
#define BYTE_BIT   _BV(PC2)

U8X8_SH1106_128X64_NONAME_SW_I2C oled(/*clock=*/ A0, /*data=*/ A1, /*reset=*/ U8X8_PIN_NONE);

volatile uint8_t bank = 0;
volatile uint16_t byteCount = 0;

static inline void writeBank(uint8_t v) {
  // PORTD bit0,1 は RX/TX、PORTB bit2,3 は入力、bit6,7 は水晶なので保存する
  PORTD = (PORTD & 0x03) | (uint8_t)((v & 0x3F) << 2);
  PORTB = (PORTB & 0xFC) | (uint8_t)((v >> 6) & 0x03);
}

// PCINT0 は PORTB の変化でまとめて呼ばれる。立ち上がりだけを拾う。
ISR(PCINT0_vect) {
  static uint8_t last = 0;
  const uint8_t now = PINB & (STROBE_BIT | RESET_BIT);
  const uint8_t rose = (uint8_t)(now & ~last);
  last = now;

  if (rose & RESET_BIT) {
    bank = 0;
    byteCount = 0;   // 1バンク読み出しの開始。バイト位置も0から
    writeBank(0);
  } else if (rose & STROBE_BIT) {
    writeBank(++bank);
  }
}

// PCINT1 は PORTC の変化。A2(バイトストローブ)だけを有効にしてある。
// 1バイトあたり47us程度なので約21kHz。表示用の数え上げなので、
// OLED更新中に取りこぼしても表示がわずかにずれるだけで実害はない。
ISR(PCINT1_vect) {
  static uint8_t last = 0;
  const uint8_t now = PINC & BYTE_BIT;
  if (now && !last) byteCount++;
  last = now;
}

void setup() {
  for (uint8_t i = 0; i < 8; i++) pinMode(BANK_PINS[i], OUTPUT);
  pinMode(RESET_PIN, INPUT);
  pinMode(STROBE_PIN, INPUT);
  pinMode(BYTE_STROBE_PIN, INPUT);
  writeBank(0);

  // 以前はここで TIMSK0 = 0 として millis() を止めていた。ポーリングで
  // パルスを追っていた頃、タイマ割り込みが邪魔だったため。割り込み方式に
  // 変えた時点でその理由は消えており、U8x8が delay() を使うので有効に戻す。

  oled.begin();
  oled.setFont(u8x8_font_chroma48medium8_r);
  oled.clear();
  oled.drawString(0, 0, "SFC DUMPER");
  oled.drawString(0, 2, "waiting...");

  PCICR |= _BV(PCIE0) | _BV(PCIE1);
  PCMSK0 = STROBE_BIT | RESET_BIT;
  PCMSK1 = _BV(PCINT10);   // A2のみ。A0/A1はI2C出力なので絶対に含めない
  sei();
}

void loop() {
  // 割り込みで進む値を、人が読める速さで描くだけ。
  // I2Cは数ms掛かるので、毎回描くと割り込みを塞ぐ時間が増える。
  static uint32_t lastDraw = 0;
  static uint8_t shownBank = 255;
  if (millis() - lastDraw < 120) return;
  lastDraw = millis();

  uint8_t b;
  uint16_t n;
  noInterrupts();          // 16bitの読み出しは分割されると壊れるので止めて読む
  b = bank;
  n = byteCount;
  interrupts();

  char line[17];
  if (b != shownBank) {
    shownBank = b;
    snprintf(line, sizeof(line), "Bank $%02X       ", (unsigned)b);
    oled.drawString(0, 2, line);
  }
  snprintf(line, sizeof(line), "%5u/65536    ", (unsigned)n);
  oled.drawString(0, 4, line);
}

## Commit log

2026-08-04 Add SFC cartridge reader: Nano x3 (address/data/bank) + host tools
    No level-shifter/shift-register ICs needed - all three Nano boards
    run natively at 5V. Verified against a real Super Puyo Puyo cartridge
    (checksum-valid dump, confirmed booting in Snes9x/RetroArch).
2026-08-05 Add GUI app, offline title database, and detailed README
    - gui/: Tkinter GUI covering port selection, firmware upload, cart
    identification, and repeat-until-checksum-valid dumping
    - gui/rdb.py: dependency-free MessagePack reader for RetroArch's
    bundled SNES .rdb, enabling offline title search -> exact ROM size
    - host/dump_until_valid.py: CLI equivalent of the repeat/merge loop
    - Replace the Nano-2 <-> Nano-3 three-wire shift transfer with the same
    STROBE counter scheme Nano-1 uses; the async clock races were the
    root cause of the corrupted banks (error rate dropped ~100x)
    - README: rationale, wiring, pitfalls hit in practice, and full
    acknowledgements to every source this project r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
    [dump_until_valid.py, nano2_master.ino, nano3_bank.ino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]
2026-08-05 Fix merge strategy: read errors are one-directional bit drops
    Comparing samples showed every observed value at a disputed position is a
    bit-subset of one maximal value (e.g. 0x83 / 0x82 / 0x02 / 0x00) - ones
    fall to zero, zeros never rise. The ROM briefly fails to drive the bus.
    Majority voting cannot converge under this failure mode: wherever the
    dropped-bit reading is in the majority, it locks in the wrong value. A
    bitwise OR across samples recovers the dropped bits and approaches the
    true value monotonically. Measured on Super Mario Collection (7 samples):
    OR landed 682 away from the expected checksum while majority was far off.
    Both the CLI and GUI now try OR first and fall back to maj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
    [dump_until_valid.py, sfc_dumper_gui.py]
2026-08-05 Add build photos and hand-drawn schematic
    Six photos of the actual build (overview, salvaged 62-pin connector,
    socket mounting, reverse-side hand wiring, OLED progress display, and
    the DC jack that turned out to be unnecessary) plus the hand-drawn
    sketch as a PDF.
    Photos are downscaled to 1600px and re-encoded with all EXIF stripped -
    five of the originals carried GPS coordinates.
2026-08-05 Retract the one-directional bit-drop claim; document what was ruled out
    The earlier "errors are always bit drops, so OR-merge converges" finding
    was wrong. It compared each sample against the *majority* value, so
    wherever the majority itself was corrupted, correct samples looked like
    spurious bit additions. Against known-good data the errors go both ways.
    Two hardware theories were tested and disproven as well:
    - Disabling the OLED entirely during reads left the error rate unchanged
    - Adding a settle delay after the OLED update made it markedly worse
    (~6.5k -> ~19k bad bytes), so the OLED update stays inline
    What is actually established: errors come in runs of tens to ~250 bytes
    where a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
    [dump_until_valid.py, nano2_master.ino, sfc_dumper_gui.py]
2026-08-05 Read one bank per power-up: continuous dumping is what corrupts data
    A timing sweep settled the question. Reading a single 64KB bank in
    isolation is perfectly repeatable - two reads differ by 0 bytes at
    100us settle and above. The same bank read partway through a 12-minute
    32-bank dump differs by ~700 bytes every time.
    So the corruption is not signal integrity or settle time; it is
    duration. Something sags after minutes of sustained draw (a USB
    polyfuse heating up fits). That also explains why bank 0 was always
    clean - it is read right after startup.
    nano2_master now dumps exactly one bank per power-up, taking the bank
    number over serial after an 'R' handshake. dump_by_bank.py drives it,
    r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
    [dump_by_bank.py, nano2_master.ino, timing_sweep.py]
2026-08-05 Add a build-and-use guide so this is reproducible without an AI agent
    docs/GUIDE.md walks through parts, the connector hack, the full wiring
    table, flashing, dumping, and verification, with a troubleshooting
    section built from the failures actually hit: all-zero reads, doubled
    bytes from a stuck A0, 32KB LoROM mirroring mistaken for corruption,
    and drift during long continuous dumps.
    It also states plainly that header checksum/complement agreement only
    proves four bytes read correctly - the whole-ROM sum is the real check.
    That mistake cost a lot of time here.
    Documents 支柱.stl as well: print four, fit them at the corners to lift
    the board off the desk so the reverse-side wiring is not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
    [bank_stability.py, cross_timing_check.py]
2026-08-05 Latch strobes with pin-change interrupts: 331us -> 47us per byte
    Polling could never be made reliable. Whenever Nano-1's loop took longer
    than one Nano-2 cycle it dropped exactly every other strobe, and widening
    the pulse to 60-100us only papered over the hole.
    What proved it: reading the same bank ten times gave the identical 30,966
    differing bytes each run - deterministic, not noise. Testing offset
    hypotheses showed output[i] == correct[i/2] at 100%, i.e. every address
    was read twice because the counter advanced half as often as it should.
    Nano-1 and Nano-3 now take the strobe on a pin-change interrupt, so the
    hardware latches the edge even if the ISR starts after the pulse ends.
    Timing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
    [bank_stability.py, cross_timing_check.py, degradation_test.py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]
2026-08-05 Rework the GUI for per-bank dumping; splash only on cold boot
    The GUI still spoke the old whole-ROM protocol at 250k baud, so every
    action timed out against the current firmware. It now uses the per-bank
    protocol ('R' handshake, then a bank number), reads each bank twice
    until two reads match, caches confirmed banks so a run can resume, and
    verifies with checksum plus CRC32 matched against the local database.
    Mapping detection no longer trusts the header's map_mode byte alone.
    It decides from the state of the lower 32KB - a mirror of the upper half
    or all zeros means LoROM, independent data means HiROM - which is what
    the Super Mario Collection misidentification came down to. LoROM
    extracti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
    [nano2_master.ino, sfc_dumper_gui.py]
2026-08-05 Escalate read timing per bank, and probe back toward fast
    The margin a cart needs varies a lot between chips. Mario Collection and
    Yakouchuu both dumped at 5us on the first try, but Street Fighter II could
    not even get two matching reads until 100us. A single global setting is
    wrong in both directions: slow wastes time on easy carts, fast burns
    retries on hard ones.
    bankio.py now starts at the fastest tier and steps down (5/20/50/100/300us)
    only as needed, remembering across banks what the current cart requires.
    Staying slow forever is its own waste, so it re-probes the fastest tier
    every few banks and recovers speed when the cart allows it.
    Timing is sent from the PC on every bank read, s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
    [bankio.py, dump_by_bank.py, nano2_master.ino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]
2026-08-05 Match cart titles against the database ignoring case, spacing and numerals
    Cart headers store titles uppercase with no separators ("MARIOPAINT",
    "FINALFANTASY4"), while the .rdb spells them normally ("Mario Paint",
    "Final Fantasy IV"). A plain substring match can never hit, so every
    lookup returned zero results.
    Comparison now strips non-alphanumerics and maps standalone Roman numeral
    tokens to digits. Both sides get the same transform, so an ambiguous token
    like a pronoun "I" still matches itself.
    Verified against the real 7621-entry database: MARIOPAINT, FINALFANTASY4,
    STREET FIGHTER 2, SUPER MARIOWORLD, YAKOUCHUU and SUPER DONKEY KONG all
    resolve now.
    [rdb.py]
2026-08-06 Search several locations for RetroArch's SNES database
    The .rdb path was pinned to ~/Downloads/RetroArch/RetroArch-Win64. RetroArch
    is a portable install that can sit anywhere, so moving it made every title
    lookup silently return nothing - no error, just zero results, which reads
    like a broken search rather than a missing database.
    Now walks a list of common install roots and takes the first hit, with
    SFC_DUMPER_RDB as an override for anything unusual.
    [rdb.py]
2026-08-06 Dump battery-backed save SRAM
    ROMs can be re-dumped; save files cannot. The coin cells in these carts are
    near end of life and take the saves with them when they go, so this is the
    data actually worth rescuing.
    Reads the SRAM bank and slices it to the size declared in the ROM header.
    /WR is already tied to +5V on the cart side, so no firmware mistake can
    write to the chip - the read-only wiring doubles as the safety interlock.
    The one trap was /ROMSEL polarity, which inverts with the mapping. /CART is
    asserted for all addresses in banks $40-$7D but only above $8000 in banks
    $00-$3F, so LoROM SRAM at $70:0000 needs it asserted while HiROM SRAM at
    $20:6000 does not. Guessing the other way ga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
    [bankio.py, dump_sram.py, nano2_master.ino]
2026-08-06 Add save-data dumping to the GUI
    Same flow as dump_sram.py, driven from the cart detection that already
    runs: the header's SRAM size now comes back with the rest of the header,
    so identifying a cart is enough to enable the button and show the capacity.
    Mapping decides both the bank and the /ROMSEL polarity, so the button
    refuses to run until a mapping is confirmed rather than guessing and
    producing an all-zero read.
    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
2026-08-06 Read DSP-1 carts from $C0, and stop calling them undumpable
    Super Mario Kart dumps as plain 512KB HiROM but the checksum lands on
    0x110e instead of 0x8a23. The DSP-1 sits at $6000-$7FFF in banks $00-$3F,
    so 8KB per bank comes back as the coprocessor's response rather than ROM -
    that region has 4 distinct byte values where its neighbours have 200+.
    HiROM mirrors the whole ROM into $C0 and up, where the DSP-1 is not mapped,
    so reading from there gets the real bytes. Checksum and No-Intro CRC32 both
    match now. The CLI takes --start-bank; the GUI retries from $C0 by itself
    when a HiROM dump fails verification, since the checksum makes that safe to
    attempt automatically.
    The README claimed ever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
    [dump_by_bank.py, sfc_dumper_gui.py]
2026-08-06 Drive cart /RESET from D7, and record that it does not unlock SA-1
    Rewired /RESET from its +5V tie to Nano-2 D7 (the old BANK_LATCH stub,
    now cut from Nano-3 D12) so the line can actually be driven, then tried
    holding Super Mario RPG's SA-1 in reset to see if it would release the bus.
    It does not. Every combination of bank $00/$C0 and /RESET high/low returns
    all 0x00. Super Mario Kart in the same rig reads correctly at $C0 and
    returns byte-identical data whether /RESET is high or low, which confirms
    both that mask ROM ignores /RESET and that D7 really is on /RESET - a
    mis-wire onto /RD or an address line would have corrupted that read.
    So the all-zero result is the SA-1's own behaviour, no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
    [bankio.py, nano2_master.ino]
2026-08-06 Add majority-vote dumping for carts that never read the same way twice
    dump_by_bank.py waits for two identical reads, which assumes errors are
    rare. That assumption fails against a cart with its own bus master: Star
    Fox's bank 0 changed 75-89 bytes out of 65536 on every single read, so two
    reads never agreed no matter how long it ran.
    Voting per byte across several reads recovers the data instead, and the
    header checksum still decides whether the result is real.
    Two things learned the hard way are built in. Slowing down makes Super FX
    worse, not better (5us gave 89 differing bytes, 300us gave 9828), so this
    stays at the fastest tier and spends reads rather than microseconds. And
    occasional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
    [bankio.py, dump_voting.py]
2026-08-06 Star Fox dumps clean - the Super FX problem was the power supply
    Star Fox resisted for hours. Every read of a bank differed from the last by
    hundreds of bytes, two reads never agreed, and majority voting over ten
    samples still left 38,937 bytes undecided across 1MB.
    None of that was the GSU. Running the cart from a bench supply instead of
    USB made five consecutive reads byte-identical, after which a plain 32-bank
    LoROM dump matched both the header checksum and the No-Intro CRC32 on the
    first try.
    What sold the wrong diagnosis was that slowing down made it worse - 89
    differing bytes at 5us against 9828 at 300us. That reads exactly like
    losing races to a bus master, so I built a whole voting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
    [bankio.py, dump_voting.py, nano2_master.ino]
2026-08-06 Yoshi's Island too - and it was contact, not power
    Second Super FX cart, same symptoms as Star Fox: hundreds to thousands of
    bytes changing between reads, bank 1 failing every timing tier. Having just
    found the power supply behind Star Fox, that is where I looked. Wrong.
    The supply held 4.99V and nothing was warm. What gave it away was quality
    swinging twelve-fold within a few minutes - 15,306 stray 0xFF bytes in the
    upper half of a bank, then 1,268. An electrical design fault does not move
    like that; a contact does. Reseating the cart made three consecutive reads
    byte-identical. The owner had already said it was a flaky cart back when he
    played it on real hardware, which beat my measuremen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
2026-08-07 Move OLED to Nano-3, add cart clock + CIC control, chase down a metal sliver
    OLED moves off Nano-2 onto Nano-3 (SCL/SDA on A0/A1, byte position tapped
    from Nano-2's D4 strobe via A2). Nano-2 was doing I2C bit-banging mid-read
    every 8192 bytes; Nano-3 already knows the bank number for free (it's
    literally what it counts), so this drops one more variable from the read
    loop and frees D11 back up on Nano-2.
    Nano-2 gains cart clock output (D11, selectable divider) and CIC control
    (D12 reset, A6/A7 monitoring) for the SA-1 authentication attempt - see
    README for what that did and didn't prove. Wasn't reachable this round,
    but the wiring stays since SA-1 is the only cart left that needs it.
    Also: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
    [bankio.py, nano2_master.ino, nano3_bank.ino]
2026-08-07 Stop judging, start scoping: a logic analyzer found the real wiring fault
    The CIC handshake test had produced five false positives in a row. Each new
    pass/fail criterion got satisfied by the failure mode. The problem was never
    the threshold - analogRead() takes ~100us per sample, so anything moving
    faster than that just looks like a flat line.
    Replaced the judgment with measurement. host/cic_scope.py plus logicCapture()
    in nano2_master run the ADC free-running at ~6.5us intervals and ship 900 raw
    samples back to the host. No threshold on the device.
    The first version reported "completely static" - which was a bug in my own
    instrument, not a finding. Bit-packing threw away the raw values an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
    [cic_scope.py, nano2_master.ino]
2026-08-09 Rewire cart clock to MCK, add REFRESH pin and SA-1 prime sequence
    SYSCK during SA-1 unlock was corrupting data; SA-1 has no oscillator
    of its own so it needs MCK (cart pin 1) instead - explains why CIC
    auth passed but ROM read back as zeros. Also ties REFRESH (pin 33)
    low as SA-1 requires, and adds an OSCR-style warm-up (1024 dummy
    reads at bank $C0) before the real read, gated by a new prime flag.
    [bankio.py, nano2_master.ino]
2026-08-17 Androidアプリを追加: スマホとNano直結でPCなしダンプ
    host/bankio.py と gui/sfc_dumper_gui.py のロジックをKotlinへ移植した。
    ファームウェア(nano1/nano2/nano3)は一切変更していない。PC版と同じ
    スケッチのまま、AndroidからUSB(OTG)直結で動作する。
    CartReader.kt : Nano-2との通信。5段階タイミング制御、2回読み一致検証、AdaptiveTiming
    RomAnalyzer.kt : LoROM/HiROM判定、ヘッダ解析、ROM抽出、チェックサム検証
    DumpJob.kt : 判定 → 全バンク読み出し → ROM抽出 → 検証
    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
2026-08-25 Vote per byte in windows, and tell timing faults from bad contact
    dump_by_bank waits for two identical reads and dump_voting drops whole
    samples as outliers. Both assume errors are spread evenly. Contact faults
    are not: they come in runs of tens to ~250 bytes, and quality swings
    within minutes, so one sample can be clean for 40KB and garbage after.
    Dropping the whole sample throws away the good part with it.
    contact_merge.py rejects outliers per 256-byte window instead, gathers
    samples by sweeping across banks rather than reading one bank five times
    in a row, and falls back to bit-level voting only where no byte value
    wins. It does not OR - errors go both ways (d0d1876).
    Two carts went thr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
    [contact_merge.py, sfc_dumper_gui.py]
2026-08-25 Reach SA-1 ROM once, and find the power behind it
    Super Mario RPG had returned nothing but 0x00 for months. It read out once
    tonight - the 65816 reset routine (REP #$30 / SEI / LDA #$0000 / TCD), the
    SUPER MARIO RPG header with a valid complement pair, and bank $C0 reading
    identical three times in a row. It has not been reproducible since, so the
    README still does not claim SA-1 works.
    The cause was never the coprocessor. Five variables got ruled out one by one
    - clock frequency, when the clock starts, whether CIC authentication is
    complete, the power-up order, the cart seating - and all of them were wrong.
    What settled it was measuring the clock pin instead of reasoning about it:
    1.75V whe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
    [bankio.py, dump_by_bank.py, nano2_master.ino]
2026-08-27 Add a boot-time cart clock, and admit the readings that fooled me
    The SA-1 cart only answered for a few seconds after power-up, so this adds
    knobs for driving the cart clock from Nano-2's D11 while the wiring moved
    from Nano-3's D12: continuous, a burst that then releases the pin, and a
    static level. None of them changed what the cart returned, which is itself
    the finding - the signal is not reaching pin 56 and no amount of clock
    shaping fixes that.
    Also records what the delay sweep showed. Replacing digitalWrite with
    direct port writes saved nothing measurable: the fit is 1.011 x delay +
    34.1us, and the floor stays at 36us/byte even with every delay at zero.
    Ten of those microseconds are t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
    [nano2_master.ino]
2026-08-28 Hold the strobes low, and stop driving the CIC clock from Nano-2
    Reading sanni's setup_Snes() line by line turned up the difference that
    matters most. It drops /CS and /RD low once at startup and never touches
    them again; readBank_SNES only sets the address, waits six NOPs, and reads
    PINC. This rig toggles /ROMSEL and /RD on every single byte - 65536 times
    per bank - and the SA-1 is a bus arbiter, so each of those edges is another
    chance for it to take the bus back. That would explain banks that read fine
    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
2026-08-29 Retract "SA-1 needs no CIC": the experiment was confounded
    I concluded that SA-1 needs neither a clock nor CIC authentication. The
    clock half holds. The CIC half was wrong, and the way it was wrong is
    worth recording.
    The evidence was: run with CIC authentication, dump Kirby, reproduce it,
    dump Mario RPG; then reflash without CIC and get five successes in six.
    I treated the second run as an independent check. It was not. Every
    no-CIC attempt happened after many authenticated power cycles, and SA-1's
    BW-RAM is battery backed, so there is a real path for state to survive
    losing power.
    Starting from a cartridge that had not been authenticated at all:
    no CIC 16 attempts 0 successes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
    [dump_sa1.py]
2026-08-29 Add the printed shell, and stop claiming CIC never matters
    The shell holds the board, protects the hand-wiring underneath and keeps
    the perfboard from flexing when a cartridge is pushed in. Photo shows it
    in use with Super Mario RPG -- the SA-1 cartridge that took three weeks.
    While adding it, found the overview section still telling readers that
    "the CIC lockout chip is entirely irrelevant". True for ordinary
    cartridges, where CIC only drives the console's reset line and leaves the
    ROM bus alone. Not true for SA-1, as yesterday's retraction established.
    That sentence sat two screens above the correction, which is exactly
    where someone would stop reading.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
    [SFC.stl, shell_dumper.stl]
2026-08-31 docs: 1チップ化の机上検討（STM32F103 / Pico / RP2350B）
    Nano×3をやめて1枚のマイコンで賄えるかを、部品の入手性込みで検討した記録。
    まだ何も作っていない。
    要点:
    - 5Vトレラントは「受け」しか解決しない。「送り」は結局レベルシフタが要る
    （SNESDRONEもpakutoma氏の実装も、独立に同じ結論に達している）
    - STM32F103は直結だと41本必要で37本に足りない。74HCT573×3のラッチで28本に落ちる
    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
2026-08-31 電源をDP100(USB HID)へ。リレーとUnoが不要になった
    出力ON/OFF・電圧設定・電流測定をPCから直接できる。
    VID 2E3C / PID AF01。フレームは [0xFB, op, 0x00, len, data..., CRC16-Modbus]で、
    **先頭にレポートID 0x00 が要る**（無いと fa 00 00 01 しか返らない）。
    ■ 安全装置は「引数で渡せない」形にした
    このダンパーは5V専用で、それ以上かけると壊れる。
    1. VMAX_MV = 5000 を超える要求は例外で拒否する
    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
    [power_log.csv]
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2026-08-31 GUI: ヘッダが読めないと落ちる不具合を修正 / 終了時の後始末
    ■ unsupported format string passed to NoneType.__format__
    verify_checksum はヘッダが読めないと (False, None, None, len(rom)) を返すが、
    表示側は expected しか None を見ておらず、computed を素通ししていた。
    f"計算値=0x{computed:04x}" ← None が来ると落ちる
    2026-08-05 の 496e368 から在ったもので、今日の連続読みで踏んだ。
    2か所直した。
    - 発生源: ヘッダが読めなくても計算値そのものは出せるので rom_sum を返す
    - 表示側: computed も None を許す。加えて「ヘッダが見つかりません。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
    [sfc_dumper_gui.py]
2026-08-31 スーパーFXカートがHiROMと誤判定される不具合を修正
    STAR FOX を連続読みすると、こうなっていた。
    判定結果: HIROM （根拠: 下位32KBに独自データあり）
    map_mode=0x20 / ROMサイズ申告 1024 KB → バンク数を 16 に設定
    チェックサム 計算値=0xb6e0 期待値=0xab12 → 不一致
    **map_mode=0x20 はLoROMである。** ヘッダ自身は最初から正しく読めていたのに、
    判定がそれを無視して上書きしていた。
    ■ 原因
    判定の前提が「LoROMなら下位32KBは上位のミラーか、駆動されず0x00になる」
    だったが、スーパーFXカートはGSUが $0000-$7FFF に応答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
    [sfc_dumper_gui.py]
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2026-09-01 SA-1を対照実験で測り直した（355試行）／PDFを訂正
    条件を1つずつ変えて各20回ずつ取った。クロックはハイインピーダンス固定。
    判定は「起動読み後に $C0 を1バンク読み、既知の正解とバイト単位で一致するか」。
    ■ 起動読みの要素分解（各20回）
    起動読みなし 0/20 ( 0%) 95%CI 0-16%
    [0xC0] 1回 13/20 (65%) 95%CI 43-82%
    [0xC0] 6回 13/20 (65%) 95%CI 43-82%
    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
    [baseline40.csv, clock_confirm.csv, clock_sweep.csv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]
2026-09-02 CICの根拠が20回ずつで消えた／マリオRPGで手順の一般性を確認
    全64バンクをバイト単位で比べて各20回取り直した。
    ■ CICの差は全ダンプでも検出できない
    CICなし 1バンク判定 11/20 / 全ダンプ 8/20 (40%) 95%CI 22-61%
    CICあり 1バンク判定 13/20 / 全ダンプ 9/20 (45%) 95%CI 26-66%
    判定の死角ではなかった。前日の根拠「4/4 対 1/6」は標本が小さすぎた。
    **それでも「CIC不要」とは書かない。** この問いで既に3回結論を変えており、
    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
    [bwram_probe.csv, cic_fulldump.csv, cic_recheck.csv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]
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2026-09-02 Nano-1: リセットを立ち上がり即実行に戻す（読み出しを壊していた）
    /WR の指示をRESETのパルス幅で受ける実装で、リセットの実行自体を
    立ち下がりまで遅らせていた。アドレスを保ったまま書き込めるので
    綺麗だと思ったが、**マリオRPGが 0/6 になった**（変更前は10/20）。
    Nano-2がRESETを戻す前にSTROBEを打つと、まだ addr=0 になっていないため
    アドレスがずれる。既存の読み出しを壊さないことを優先し、
    リセットは従来どおり立ち上がりで即実行、/WR は立ち下がりで追加で出す形にした。
    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
    [rpg_check.csv]
2026-09-02 SA-1のBW-RAMを読む経路を実装（Nano-1 / Nano-2 / ホスト）
    ■ 経緯: 設計を2回間違えた
    1. 指示をRESETの幅で受ける案 → **リセットの実行を立ち下がりまで遅らせて
    読み出しを壊した**（マリオRPG 0/6、元は10/20）
    2. リセットを元に戻したが `TIMSK0 = 0;` を消したまま → **まだ 0/6**
    micros() を使いたくて外したが、元のコメントが正しかった。
    「ISR内では割り込み禁止だから競合しない」と考えたのは誤りで、
    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
    [rpg_check.csv]
2026-09-02 Nano-2: writeCartByte がバンクを戻していなかった
    A16-A23 を resetNano3Bank() で0に戻す処理が抜けており、
    起動読みで $E0 を読んだ直後の状態から書いていた。
    SA-1のレジスタがある $00:2224 ではなく $E0:2224 に書いていたことになる。
    修正しても窓は開かなかった。壁は別のところにあり、
    読み出しの時点で $2200-22FF (SA-1レジスタ域) が 0x00 一色で無反応である。
    [rpg_check.csv]
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2026-09-02 CIC認証の任意タイミング実行が動作／DP100の通信断に再接続を追加
    ■ CIC再認証: 実機で成立を確認
    Nano-3のOLEDに **re-auth done** が出た。
    電源を切らずにCIC認証をやり直せるようになった。
    読み出しも 4/6 で元の水準（50%）を維持しており、
    バンクリセットのISRに判定ループを足した影響は出ていない。
    これまでNano-3は電源投入から300ms後に1回だけ認証し、それきりだった。
    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
    [rpg_check.csv]
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
